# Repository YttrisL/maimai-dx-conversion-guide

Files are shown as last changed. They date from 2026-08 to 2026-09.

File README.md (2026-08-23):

# maimai FiNALE to DX Upgrade Guide

This repo hosts a step-by-step hardware guide for converting a **maimai
FiNALE** arcade cabinet into a working **maimai DX** cabinet - a project the
community calls "DxNALE". It covers everything from sourcing the right
equipment, to wiring, the touchscreen, the I/O board, the Aime reader, proxy
compatibility, audio, lighting, and cameras, in an order meant to be
followed start to finish by someone who isn't an electronics engineer.

The guide's guiding principle is **total software fidelity**: the goal is
never to modify the game's own software, but to make the hardware
adaptation invisible to it, so the resulting cabinet stays the way 
a genuine cabinet would behave.

## Building, running, or publishing this site

If you need to set up MkDocs locally, preview changes as you write, or build/publish
the static site, that's all covered separately in [DEVELOPMENT.md](DEVELOPMENT.md).

---

## A note on AI involvement

Claude (Anthropic) was used to help set up the MkDocs infrastructure for this
repo, and to assist with proofreading - fixing spelling and grammar,
rewording awkward turns of phrase - and with translating pages. 
Claude was **not** used to draft or generate the guide's
actual content from scratch: every `.md` file's substance - the steps, the
explanations, the technical knowledge - is human-written. AI here played an
editing and translation role, not an authoring one.

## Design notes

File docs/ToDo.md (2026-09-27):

---
title: "☑️ ToDo"
search:
  exclude: true
---

# ☑️ ToDo

- [ ] Check que toutes les références de FiNALE sont entre ** et pareil pour DX
- [ ] Vérifier la graphie de ALLS et de RingEdge2, s'assurer qu'elle est cohérente entre toutes les pages. (Entre ** également ?)
- [ ] PCB de conversion : Toujours écrit avec un lien
- [ ] Hub 4x RS-232 vers USB: Décider d'une graphie et la réutiliser partout. De manière générale, toute les pièces référencées.
- [ ] "Voir étape XX : Description" : S'assurer que tous les liens sont cohérents, qu'ils aient tous la même graphie et la même description.
- [ ] Vérifier les quantités et les objets de la liste de course
- [ ] Proposer un support en 3D de caméra incluant les leds et utilisant un module simple à trouver
- [ ] Pour toutes les mentions du style 1P SELECT, s'assurer qu'ils soient entre accent comme `1P SELECT`
- [ ] 
- [ ] 
- [ ] 
- [ ] 
- [ ] 
- [ ] 
- [ ] 
- [ ] 
- [ ] 
- [ ] 
- [ ] 
- [ ] 
- [ ] 
- [ ] 
- [ ] 
- [ ]

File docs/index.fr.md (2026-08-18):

---
title: "🏠 Accueil"
---

# Guide Complet : Projet "DxNALE"

## Convertir une borne maimai FiNALE en maimai DX

Bienvenue dans le guide détaillé de conversion matérielle d'une borne d'arcade **maimai FiNALE** vers le système **maimai DX**. Ce document est basé sur [les notes de conversion de la communauté](pdfs/dxnale-original-guide.pdf) et a été enrichi pour être accessible même si vous n'êtes pas un ingénieur en électronique.

---

## Qu'est-ce que "DxNALE" ?
DxNALE est le nom donné par la communauté aux bornes maimai FiNALE converties afin de faire fonctionner maimai DX. En effet, les deux systèmes sont radicalement différents, et il est strictement impossible de faire tourner DX sur une borne FiNALE dans son état d'origine.

Il existe une rumeur persistante au sein de la communauté selon laquelle convertir une borne en DxNALE serait un travail colossal, titanesque, presque irréalisable. **Il n'en est rien.** Certaines étapes sont effectivement complexes, mais ce guide a pour but de vous assister tout au long de l'opération.

!!! tip ""
    **L'objectif final : Une fidélité logicielle parfaite**

    Il est possible de modifier les données du jeu afin de pouvoir rendre compatible n'importe quelle dalle tactile produite par la communauté, toutefois nous visons ici une fidélité logicielle totale.
    
    **Aucune modification logicielle du jeu n'est tolérée.** Le jeu doit "penser" qu'il tourne sur une borne originale Sega. Par conséquent, toute notre adaptation matérielle doit être invisible pour le jeu.

    L'avantage de cette approche est que la borne DxNALE obtenue est théoriquement compatible avec l'idéologie de la plupart des serveurs privés principaux pour maimai DX.

---

## Par où commencer ?

1. Lisez les [Avertissements](warnings.md) pour comprendre les enjeux du projet et les conséquences de la modification.
2. Familiarisez-vous avec le [Lexique](glossary.md) afin de vous assurer de comprendre les termes employés par la suite.
3. Consultez la [Liste de courses](equipment.md), vous devez vous procurer chacun des éléments mentionnés.
4. Suivez les étapes de conversion dans l'ordre, en commençant par l'[Étape 1 : PC Central (ALLS)](step-1-pc-alls.md).
5. Pour les détails techniques du pont tactile, référez-vous à l'annexe [Comprendre maitouch_rs](understanding-maitouch_RS.md).

**Félicitations d'avance !** Si vous suivez toutes ces étapes, vous obtiendrez une borne *maimai DxNALE* fonctionnelle, sublimée et prête pour le jeu en ligne.

---

Prêt à vous lancer ? Commençons par les [Avertissements](warnings.md).

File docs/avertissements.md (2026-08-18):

# ⚠️ Avertissements et Considérations

Avant de vous lancer, voici la réalité du projet :

* **C'est coûteux :** Comptez entre 3000€ et 4000€ en plus du prix de la borne de base pour les pièces (Écrans tactiles ADX, PC ALLS, Raspberry Pi, câblages, etc.).
* **C'est complexe et long :** Il faut savoir lire un schéma de câblage, dénuder/sertir des fils, et utiliser Linux. Prévoyez au moins une semaine complète de travail acharné.
* **C'est quasi-irréversible :** Revenir en arrière (vers *Finale*) sera extrêmement fastidieux.
* **Testez avant :** Assurez-vous que votre borne *Finale* fonctionne parfaitement avant de commencer. Cela vous évitera de chercher des pannes imaginaires plus tard.

---

Un peu perdu dans les termes techniques ? Direction le [lexique](lexique.md).

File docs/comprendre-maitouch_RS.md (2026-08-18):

# Comprendre `maitouch_rs` : Un pont entre l'ancien et le nouveau

Ce document explique simplement le projet GitHub [`maitouch_rs`](https://github.com/4ndr3w/maitouch_rs). Si vous n'êtes pas un expert en protocoles de communication comme le port série RS-232 ou l'USB, ce guide est fait pour vous !

## L'Analogie Globale

Imaginez que vous avez un vieux jeu vidéo d'arcade qui ne sait communiquer qu'à l'aide d'un vieux talkie-walkie très lent. Vous voulez connecter à ce jeu un écran tactile moderne et ultra-rapide. 

L'écran tactile *fait semblant* d'avoir une prise de talkie-walkie pour être compatible avec l'ancien système (ce qu'on appelle l'USB-CDC), mais en réalité, il communique à la vitesse d'une connexion internet moderne. Parce que le talkie-walkie du vieux jeu est trop lent et qu'il est vite submergé, et parce que l'écran tactile est très exigeant sur la façon dont il reçoit les messages, les deux appareils ne peuvent pas se comprendre directement.

C'est ici qu'intervient **`maitouch_rs`**. C'est un petit programme qui agit comme un **traducteur intelligent** placé entre les deux.

## Les Deux Problèmes Principaux

Le créateur du projet explique deux problèmes majeurs lorsqu'on essaie de relier ces deux appareils directement avec des outils standards :

1. **La différence de vitesse (La lance à incendie vs la paille) :**
   L'écran tactile envoie des mises à jour de position (où vous touchez l'écran) à une vitesse folle (vitesse USB). De l'autre côté, le vieux jeu ne peut recevoir des données qu'au compte-gouttes (à "9600 baud"). Si on les relie sans réfléchir, le jeu est inondé de données, tout s'accumule, et le système plante.
   
2. **Le problème de la "gorgée unique" (Pas de mémoire tampon) :**
   L'écran a une particularité capricieuse : il exige qu'une commande lui soit envoyée en **un seul bloc parfait** (un seul appel de programmation appelé `write()`). Si la commande est découpée en plusieurs petits morceaux pendant le trajet sur le câble, l'écran ne sait pas comment la reconstituer et l'ignore tout simplement.

## Ce que fait cet outil

Pour résoudre ces problèmes, `maitouch_rs` effectue trois tâches principales :

1. **Il regroupe les commandes (Mise en mémoire tampon) :**
   Quand des messages lents arrivent du jeu pour paramétrer l'écran, le programme les conserve temporairement. Il attend que le message soit 100% complet, puis il l'envoie à l'écran tactile en **une seule fois** pour que l'écran l'accepte sans broncher.
   
2. **Il absorbe la haute vitesse :**
   Quand le jeu demande à l'écran tactile de commencer à envoyer les mouvements (mode "streaming"), l'écran se met à cracher des données à toute vitesse. Le programme absorbe cette quantité massive de données instantanément.
   
3. **Il donne la priorité aux données récentes :**
   Comme la connexion vers le jeu est trop lente pour lui transmettre *absolument tous* les petits mouvements de doigt, le programme fait le tri. Il jette les vieilles positions et n'envoie au jeu que **la position la plus récente possible**, aussi vite que la connexion lente le permet. Le jeu reste ainsi fluide et sans retard.

---

## Annexe : Petit lexique pour les débutants

Si les termes techniques vous semblent encore flous, voici de quoi y voir plus clair :

### Qu'est-ce que le RS-232 ?
Le RS-232 est une norme de câblage très ancienne pour brancher des appareils (comme les vieilles souris, imprimantes ou les modems des années 90) via ce qu'on appelle un **port série**. 
*   Il envoie les données à la queue leu-leu, "en série" (bit par bit sur un seul fil).
*   On mesure sa vitesse de transmission en **"bauds"**. Le terme "9600 baud" mentionné dans le projet signifie qu'il transmet environ 9 600 petits morceaux d'information par seconde. C'était suffisant pour du texte dans les années 80, mais c'est extrêmement lent pour du matériel d'aujourd'hui.

### Qu'est-ce que l'USB-CDC ?
CDC signifie *Communication Device Class*. C'est une petite ruse technique intégrée à l'USB.
*   Quand on branche un appareil USB-CDC sur un ordinateur, l'appareil ment à l'ordinateur et lui dit : *"Hé, fais comme si j'étais un vieux port série RS-232"*. 
*   Cela permet aux vieux logiciels (comme notre jeu d'arcade qui ne connaît que le RS-232) de fonctionner avec du matériel moderne USB sans que les développeurs aient besoin de modifier le code du jeu.
*   **Le piège :** Même s'il *fait semblant* d'être un vieux port série réglé à 9600 bauds, le matériel en lui-même s'en moque éperdument. Il utilise les vrais fils et la vraie puce USB (qui peut transmettre des millions de bits par seconde) et ignore totalement cette limite virtuelle. C'est exactement cette contradiction qui crée le goulot d'étranglement que `maitouch_rs` vient corriger !

---

Retour à l'[Étape 5 : Compatibilité avec le système d'origine via le Proxy](etape-5-proxy-compatibilite.md).

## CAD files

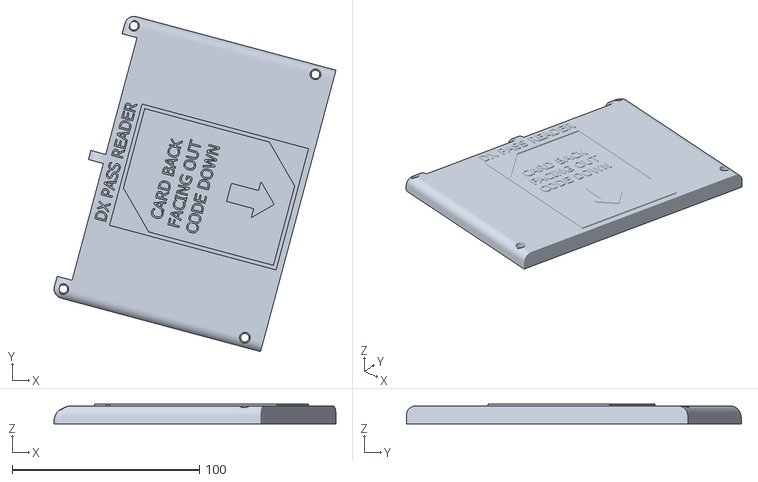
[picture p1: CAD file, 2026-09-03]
docs/resources/models/spiralglide/dxnale-dx-pass-reader-front-panel-v2.stl
150.5 x 178.9 x 10.5

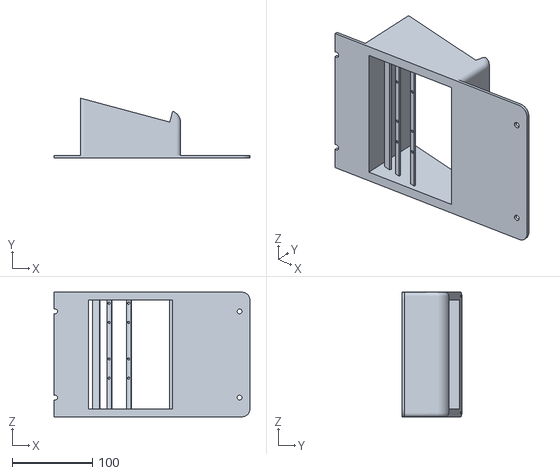
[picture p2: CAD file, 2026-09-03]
docs/resources/models/spiralglide/dxnale-dx-pass-reader.stl
244.5 x 74.5 x 155.5

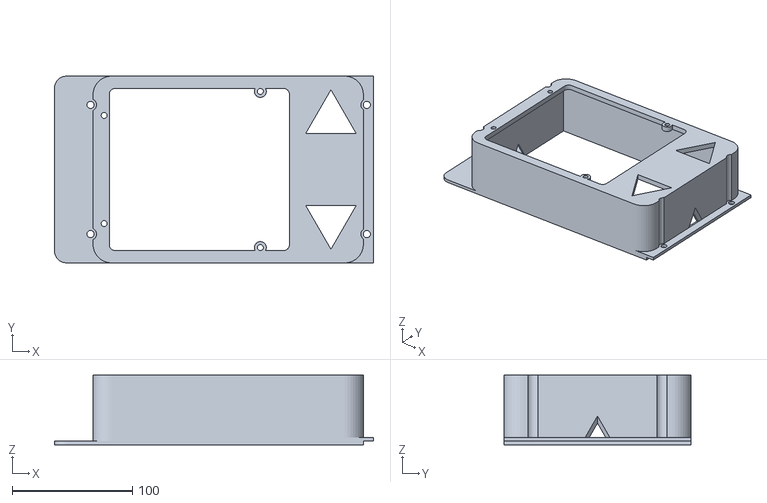
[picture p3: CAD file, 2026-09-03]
docs/resources/models/spiralglide/maimai-aime-reader.stl
265.5 x 155.5 x 58.0

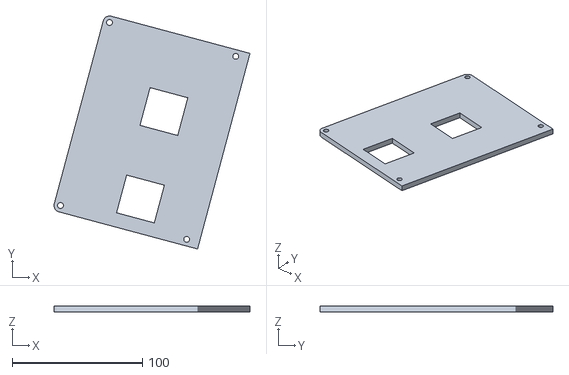
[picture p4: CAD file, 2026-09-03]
docs/resources/models/spiralglide/dxnale-dx-pass-reader-midpanel-v2.stl
150.5 x 178.9 x 4.50

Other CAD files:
docs/resources/models/spiralglide/maimai-aime-reader.ipt

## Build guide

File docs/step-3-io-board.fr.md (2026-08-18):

---
title: "🔌 3 - Carte I/O et boutons"
---

# 🔌 Étape 3 : La Carte I/O et les Boutons

Pour faire tourner *DX*, il est nécessaire de remplacer l'ancienne carte I/O par le nouveau modèle **IO4**. Heureusement, le câblage reste globalement le même, à quelques exceptions près.

*(Note : Le détail complet du câblage de la carte IO4 se trouve à la page 194 du [manuel](pdfs/maimai-dx-manual-full.pdf), en bas à droite)*

## 1. Le Bloqueur de Pièces (Coin Locker)

La broche (pin) correspondant au bloqueur de pièces a été déplacée au passage à l'IO4. Sur une borne *FiNALE*, il était câblé sur la broche 51.

1. Sur le gros faisceau de câbles anciennement raccordé à l'IO3, repérez la broche **51**.
2. Déplacez ce fil vers la broche **53**.

## 2. L'ajout des boutons "Select"

Sur *DX*, de nouveaux boutons physiques sont apparus pour permettre aux joueurs de trier les chansons. Vous devez les câbler manuellement :

1. Vous devez installer vos boutons sur le panneau central de votre borne, idéalement via la confection d'un boîtier personnalisé pour éviter une modification destructrice de la coque.
2. Connectez une broche de chaque bouton sur le neutre du faisceau de câbles (broches de 9 à 16).
3. Connectez l'autre broche du bouton sur la broche de la nappe correspondante :
   * "1P SELECT BUTTON" : Broche **27**
   * "2P SELECT BUTTON" : Broche **26**

## 3. Le contrôle des LEDs du Billboard (Toit de la borne)

Sur *DX*, l'IO4 est responsable de la gestion des lumières du sommet de la borne. Ce point sera également abordé à l'[Étape 7](step-7-lighting.md), mais voici déjà le schéma (pinout) des LEDs à raccorder :

* "BILLBOARD LED L RED" : Connecteur **CN3** - Broche **51** (Le gros faisceau de câbles)
* "BILLBOARD LED R RED" : Connecteur **CN3** - Broche **52** (Le gros faisceau de câbles)
* "BILLBOARD LED L GREEN" : Connecteur **CN9** - Broche **5**
* "BILLBOARD LED R GREEN" : Connecteur **CN9** - Broche **6**
* "BILLBOARD LED L BLUE" : Connecteur **CN9** - Broche **9**
* "BILLBOARD LED R BLUE" : Connecteur **CN9** - Broche **10**

Si vous ne souhaitez pas installer les LEDs du dessus de la borne, vous pouvez ignorer cette étape.

## 4. Branchement USB de la carte IO4

La nouvelle carte IO4 communique avec le PC *ALLS* via un simple câble USB. Cependant, **le choix du port USB sur l'ordinateur est défini dans le [manuel](pdfs/maimai-dx-manual-full.pdf)** *(Voir page 128 du manuel)*. Si vous regardez le PC *ALLS* posé à plat (à l'horizontale), vous devez brancher le câble de l'IO4 sur le port USB situé **en bas à gauche**.

---

Passons à l'[Étape 4 : Le Lecteur de Cartes Aime](step-4-aime-reader.md).

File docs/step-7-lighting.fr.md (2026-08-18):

---
title: "💡 7 - Lumières (optionnelle)"
---

# 💡 Étape 7 : Lumières (Optionnelle)

À ce stade, le jeu devrait être totalement jouable, mais l'éclairage esthétique de la borne n'est pas encore fonctionnel.
Sur *DX*, il y a trois contrôleurs différents qui gèrent l'éclairage de la borne :

* L'IO4 gère l'éclairage du "Billboard", le sommet de la borne. Référez-vous à l'[Étape 3](step-3-io-board.md) (point 3) pour savoir quelles broches utiliser.
* Deux cartes de contrôle identiques :
  * Une gère les LEDs des huit boutons du P1, l'éclairage du côté gauche, l'éclairage de l'anneau central de gauche et l'éclairage du fond de gauche.
  * L'autre gère les LEDs des huit boutons du P2, l'éclairage du côté droit, l'éclairage de l'anneau central de droite et l'éclairage du fond de droite.

Les deux cartes de contrôle s'interfacent en norme série RS-232 à une unique PCB convertissant les deux signaux RS-232 en USB. Cette PCB est elle-même raccordée à la même multiprise USB (Hub) que les caméras lecteurs de QR-Code (voir [Étape 8](step-8-cameras.md)).
Les ports COM logiciels sur lesquels les contrôleurs de LEDs sont interfacés sont le **COM21** pour les LEDs du P1 et le **COM23** pour les LEDs du P2.

Dans le cas d'une borne convertie, toutefois, les choses sont un peu plus compliquées.

Il est théoriquement possible de réutiliser les contrôleurs de LEDs d'une borne *FiNALE*, toutefois ceci s'accompagne de plusieurs inconvénients.

- Le numéro de série de la PCB ne correspond pas à ce que *DX* s'attend à trouver, cela provoquera ainsi un avertissement ("warning") au démarrage de la borne. Cela dit, le contrôleur fonctionnera tout de même.
- En cas de "warning", le jeu n'envoie simplement pas les données permettant d'éclairer l'anneau central (à ne pas confondre avec les boutons) et le corps de la borne (les données FET).

Les contrôleurs de LEDs de *FiNALE* s'interfacent de la même manière que ceux de *DX*, en passant par une carte de traduction intermédiaire convertissant le RS-232 des deux cartes en une unique connexion USB.
Les références sont les suivantes :

- *FiNALE* - Contrôleur LED : `837-15070-02-91 IC BD LED DRV32CH RS232` (Identique pour les deux joueurs)
- *FiNALE* - Convertisseur Serial-USB intermédiaire : `837-15067-02 IC BD USB TO 4SERIAL 232 IF`

Dans [le manuel de maimai *PiNK*](pdfs/maimai-pink-manual-full.pdf), on peut retrouver le contrôleur de LED à la page 192, et le convertisseur Serial-USB à la page 191 aux alentours de la zone FG-2.

Pour contourner le problème des avertissements sans avoir besoin de changer le contrôleur des LEDs, nous pouvons utiliser la même astuce de Proxy que nous avons utilisée à l'[Étape 5](step-5-proxy-compatibility.md). À l'aide d'un second Raspberry Pi 5 [et du logiciel `mailight_rs` (écrit en langage Rust)](https://gitea.farewell.dev/Yttris/mailight_rs), nous pouvons interfacer le contrôleur des LEDs avant la carte de traduction USB-Serial pour l'envoyer à notre proxy. Ce dernier s'occupera d'adapter le signal en modifiant les en-têtes pour fournir au jeu un signal lui faisant croire qu'il s'agit des bonnes PCB, il retournera ainsi un signal "GOOD" à la place du "warning". Le Raspberry Pi se placera alors entre les PCBs de contrôle des LEDs et le convertisseur serial USB, qui pourra lui être directement branché au ALLS sur le port dédié au Hub USB, ou au Hub USB lui-même si des lecteurs de QR-Code sont également installés.

Il est également possible de réutiliser le même Raspberry Pi 5 que celui des ADX pour effectuer le proxy des LEDs, toutefois à des fins de netteté et d'organisation, il est suggéré d'en dédier un pour chaque proxy.

---

Dernière étape (optionnelle) : les [Caméras](step-8-cameras.md).

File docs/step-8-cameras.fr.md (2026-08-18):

---
title: "📷 8 - Caméras (optionnelle)"
---

# 📷 Étape 8 : Caméras (Optionnelle)

Si vous souhaitez finaliser votre borne pour qu'elle soit parfaite, vous pouvez ajouter les caméras. Cependant, le jeu est tout à fait fonctionnel sans elles.

## 1. Caméra des joueurs (Photos in-game)

Prenez une webcam très basique et bon marché. Imprimez un support en 3D pour la fixer au sommet de la borne, sur la vitre en acrylique.

* **Branchement :** Sur l'ordinateur *ALLS* posé à plat, cette webcam doit se brancher sur le port USB situé **en bas à droite** *([Manuel](pdfs/maimai-dx-manual-full.pdf), page 128)*.
  Deux LEDs dédiées sont également à câbler sur l'IO4. Sur le connecteur CN9, en position 7 "CAMERA LED WARM" et en position 8 "CAMERA LED RED". *(Voir [manuel](pdfs/maimai-dx-manual-full.pdf), page 194)*.
* La plupart des réseaux privés ne gèrent pas la caméra, son usage se résumera donc à l'affichage en jeu.

## 2. Caméras des lecteurs de QR-Code

Dans *DX*, les joueurs peuvent scanner des cartes avec des QR codes.

* Pour que cela fonctionne, vous devez obligatoirement utiliser des webcams capables de filmer en **format UVC 640x480**.
* **L'éclairage :** Le jeu exige d'éclairer ces cartes avec des LEDs blanches (alimentées en 12V). Ces LEDs sont contrôlées par l'IO4, via les broches 55 et 56. *(Voir [manuel](pdfs/maimai-dx-manual-full.pdf), page 194)*.
  *Astuce : Ne braquez pas les LEDs directement sur la lentille de la caméra. Éclairez plutôt la paroi en plastique pour que la lumière rebondisse de façon diffuse sur la carte.*
* **Branchement :** Sur une véritable borne *DX*, ces caméras sont reliées à la même multiprise USB (Hub) que les lumières de la borne. Vous pouvez faire la même chose en utilisant un simple Hub USB branché sur le PC. Sur l'ordinateur *ALLS* posé à plat, le Hub doit être branché sur le port USB situé en **haut à droite** *([Manuel](pdfs/maimai-dx-manual-full.pdf), page 128)*.

**Faut-il vraiment installer les caméras QR Code ?**
C'est tout à fait optionnel. À moins que vous n'ayez accès à une autre borne très spécifique (le *Sega CardMaker*) pour imprimer vos cartes, elles ne vous serviront à rien. De plus, la plupart des réseaux privés offrent virtuellement un "DX Pass" à tous les joueurs, débloquant les fonctionnalités sans avoir besoin de scanner de cartes.

*Sachez qu'il est souvent possible lors de l'enregistrement de votre borne sur un réseau privé de demander à l'administrateur de désactiver complètement la recherche de ces caméras si vous ne souhaitez pas les installer.*

---

Vous avez terminé toutes les étapes ? Direction la [conclusion](conclusion.md) !

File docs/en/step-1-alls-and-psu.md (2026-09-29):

---
title: "🛠️ 1 - ALLS and PSU"
---

# 🛠️ Step 1: Replacing the Central PC (ALLS)

The old *RingEdge 2* PC cannot run *DX*: you need an **ALLS HX2** PC. Beyond the newer, more powerful hardware, the operating system is radically different between the two machines. **The replacement is mandatory.**

## Technical background

??? note "Click here for the technical explanation"
    The **ALLS HX2** is DX's native system: it is the one we substitute for FiNALE's RingEdge 2. An **ALLS MX2** also works: its specifications exceed the minimum required for *DX*. In principle, **every second-generation ALLS** (those whose model name ends in 2) **is software-compatible**, but some lack the power to run the game properly. That is the case, for example, of the **ALLS X2**: compatible, but too weak for a pleasant experience. These models can be upgraded, but the job quickly gets complicated: *you are better off getting a suitable model from the start.*

    An ALLS is very similar to a modern gaming PC, with two particularities:

    - **A recessed USB port** on top of the motherboard, reserved for the **keychip**. This USB key identifies the cabinet's owner on the official Sega network and decrypts the game data.
    - **Two expansion cards** (on second-generation models), which add three RS-232 serial ports and a 2.5mm audio jack. Together with the motherboard's COM port, these serial ports connect the Aime reader, the VFD and the touch panels of both screens. The jack is dedicated to one of the two headphone outputs.

    !!! tip "The ALLS power supply"
        The ALLS power supply switches voltage automatically: its C13 connector accepts 100V, 110V, 220V or 240V alike. **No external transformer is needed.**

    !!! warning "Storage"
        An official *DX* ALLS HX2 contains **two drives**: a 120GB SSD and a 500GB hard drive (named "SUB STORAGE"). **The game needs both**, the SSD alone is not enough. If your ALLS has only one drive, you will need to install a second one.

        To do so, see the [ALLS HX2 Service Manual](../resources/pdfs/alls-hx2-service-manual-full.pdf): **plugging in the drive is not enough**, a software step detailed in the manual is also required.

## Installing it in the cabinet

### Removing the RingEdge 2 and clearing the PC compartment

Start by **unplugging every connector from the RingEdge 2** and take it out of the cabinet. It will no longer be used: only keep it if you plan to convert the cabinet back to FiNALE someday.

!!! tip "Take out the whole board"
    Depending on your cabinet model, the RingEdge 2 is probably mounted on a wooden board. If so, remove the board directly rather than fighting with the hard-to-reach screws holding the PC in place.

Most of the surrounding components can be removed as well. To the right of the RingEdge 2, you will find **three PCBs**:

- **The IO3**, at the very top, recognizable by the large ribbon cable connected to it.
    * **Remove it**, along with its USB cable: it is replaced by the IO4 on *DX*.
- **The RS-232 to USB adapter**, bottom left, connected to the RingEdge 2 over USB. Two two-wire connectors are normally plugged into its bottom row.
    * **Keep it**: this board links the LED controllers to the PC. Take the opportunity to remove it and dust it off, you will reinstall it later.
- **The FiNALE touch panel controller**, bottom right, connected to the RingEdge 2 by a three-wire cable ending in a DB9.
    * **Remove it**, along with its cable and the two white cables connected underneath: the *DX* touch panels are radically different and no longer use this component.

Once these three PCBs are out, tidy up: **you will need all the available space.** If the RingEdge 2 was mounted on a board, you should now have a perfectly flat surface. *If it sat on two wooden slats, remove them too.* Where possible, secure the cables along the side walls rather than on the floor, to free up as much room as possible.

**The FiNALE router and camera** can be removed too: the router was notably used to link the camera to the RingEdge 2, and that camera is no longer used on *DX*. Also remember to remove the 2.5mm audio jack cable that linked the camera to the RingEdge 2.

#### Video cables

Originally, pre-*DX* maimai cabinets connect their screens to the RingEdge 2 with **two DVI to VGA cables** (VGA end on the screen). A choice that remains a mystery, since both screens have a DVI input: many operators therefore replaced them with plain DVI to DVI cables. Depending on your cabinet's history, you will find one or the other:

- **Player 1**: remove the cable, whatever it is.
- **Player 2**: **keep it if it is a DVI to DVI cable**, remove it if it is the original DVI to VGA.

!!! success "What should remain"
    Of the original RingEdge 2 wiring, you should only have left:

    - the two 2.5mm audio jack cables for the player 1 and player 2 speakers
    - the Molex Mini-Fit Jr cable (power)
    - possibly, the DVI to DVI cable for the player 2 screen

### Installing the ALLS

The ALLS is wider than the RingEdge 2, but the space you just cleared lets you install it comfortably, along with the various PCBs we will connect to it later. On official *DX* cabinets, the ALLS is actually installed *vertically*: that is an option if you are short on space. **What matters is that the PC is firmly secured** and cannot move if the cabinet is moved.

Once the ALLS is in place, you can already:

- **Mount the IO4**, ideally where the old IO3 was, to take advantage of the nearby original power cables. If you opted for the [conversion PCB]({{IO4_CONVERSION_PCB}}), plan room for it as well.
- **Reinstall the RS-232 to USB adapter.**
- **Plug the USB hub into the ALLS's USB 2 port**, then the RS-232 to USB adapter into that hub.
- **Install your new 5V/12V switching power supply** (see [Power supply](#power-supply)). Ideally, place it on the player 1 side with the other switching power supplies, even if that requires longer cables.

The remaining cables will be reconnected over the following steps.

## Connections

Here is the plate from the [official maimai DX manual](../resources/pdfs/maimai-dx-instruction-manual-full.pdf) (page 128) detailing all the connectors on an ALLS HX2. Let's go through each connection in detail.

!!! lightbox wide
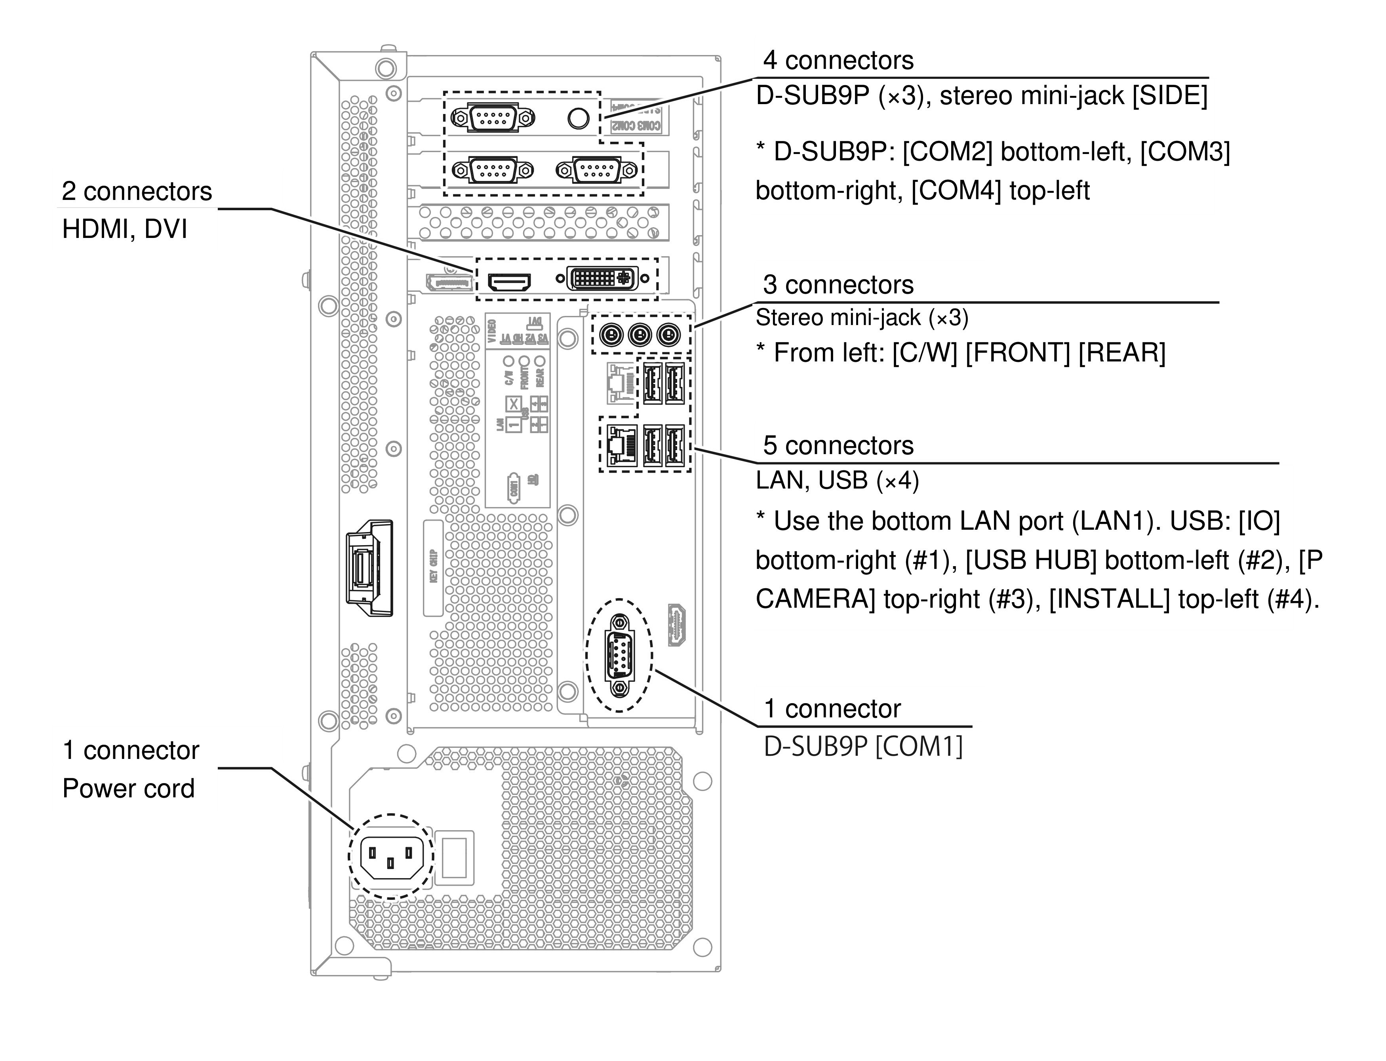
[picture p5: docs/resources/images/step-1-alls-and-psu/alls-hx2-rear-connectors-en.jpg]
Rear view of an ALLS HX2 and detail of its connectors.
    

Most of the devices to connect are covered in more detail in the following steps: if in doubt about a connection, finish the corresponding chapter first, then come back to this page. **According to the official *DX* manual, the order of the USB ports matters**: stick to the assignment below.

### Internal PSU

- **C13 connector**: Mains connection, accepts any input voltage from 100V to 240V.

### Keychip

- **USB port**: Reserved for the keychip. It can **not** be used as a regular USB port.

### Motherboard

- **COM1 - DB9 port**: Aime reader
- **LAN1 - RJ45 port**: Network port, to be connected to the service router. The second network port is unused.
- **2.5mm audio jacks**:
    - **C/W**: Player 1 [headphones](step-5-audio-headphones.md#the-headphone-jacks)
    - **FRONT**: Player 1 [speakers](step-5-audio-headphones.md#connecting-the-speakers)
    - **REAR**: Player 2 [speakers](step-5-audio-headphones.md#connecting-the-speakers)
- **USB**:
    - **USB 1**: SEGA IO4
    - **USB 2**: USB hub, to which the two QR code cameras and the `4x RS-232 to USB` adapter are connected.
    - **USB 3**: Player camera
    - **USB 4**: Installation port, for a USB stick containing the game data to install.

### Graphics card

- **HDMI**: Connected to the player 1 screen via an HDMI - DVI-D cable.
- **DVI**: Connected to the player 2 screen via a DVI-D cable.
- **DisplayPort**: Unused, mirrors the player 1 video signal.

### Expansion cards

- **COM2 - DB9 port**: VFD
- **COM3 - DB9 port**: Player 1 touch panel
- **COM4 - DB9 port**: Player 2 touch panel
- **SIDE**: Player 2 [headphones](step-5-audio-headphones.md#the-headphone-jacks)

## Power supply

Most connections are fairly straightforward, but **one essential RingEdge 2 connector has no equivalent on the ALLS**: the one that powers the external peripherals.

On the RingEdge 2, next to the keychip port, comes out a **female 2x7-pin Molex Mini-Fit Jr connector**. It links several parts of the cabinet, including the IO3, to the PC's internal power supply. Rather than rewiring the whole area, **the simplest solution is to build a small adapter** from an identical Molex Mini-Fit Jr connector, wired to a **switching power supply providing 5V and 12V** (typically an enclosed model with screw terminals, like those from the Mean Well brand). The original connector also provides 3.3V, but no hardware in this area uses it.

!!! warning "Do not reuse the cabinet's power supplies"
    Among other things, this harness will power the IO4. Reusing the existing 5V supply would have little consequence, but **reusing the LEDs' 12V supply would be a mistake**: to avoid any backfeed current, the IO4 and the LEDs must each have their own power supply, as the IO4 is not designed to handle that much current.

!!! warning "Tie the grounds together"
    **Connect the GND of your new power supply to the GND of one already in place in the cabinet.** A floating power supply can cause all sorts of unexpected problems.

Female Molex Mini-Fit Jr 2x7 connector, front view from the contact side: pins 1 to 7 are GND, 8 to 10 are +12V, 11 to 13 are +5V and 14 is +3.3V

Wire the female connector following the diagram above. It is shown **from the front, contact side**: do not confuse it with the wire side.

- Pin 14: **3.3V** (optional, unused)
- Pins 13-11: **5V**
- Pins 10-8: **12V**
- Pins 7-1: **GND**

Connect each wire to the matching terminal of your power supply. Little current flows through this harness (less than 3A in total, all voltages combined), but **make sure to use a suitable wire gauge**: the **20 AWG** (0.5mm²) wire from the [equipment list](equipment.md) is ideal. 22 AWG would also work, since each voltage is spread over several pins. Just check that your Mini-Fit Jr crimp terminals accept the gauge you choose (18-24 AWG terminals are the most common).

All that's left is to plug your homemade connector into the original cable.

!!! warning "The power supply must be firmly secured"
    The cabinet moves around a lot: **the power supply must never be able to shift or tip over.** Screw it firmly to the floor of the compartment.

## Summary
!!! tldr "The big picture"
    For the ALLS and the power supply:

    * Remove the RingEdge 2 and clear the compartment (IO3, FiNALE touch controller, router, camera)
    * Install the ALLS HX2 in its place and secure it firmly
    * Connect the various peripherals to the ALLS (see the following steps)
    * Build an adapter cable for the external power connector
    * Install the external power supply and the adapter cable in the cabinet, then plug in the existing connector

---

Let's move on to [Step 2: HDX Display and Touchscreens](step-2-touchscreen-display.md).

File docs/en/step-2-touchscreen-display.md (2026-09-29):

---
title: "📺 2 - Screens & touchscreens"
---

# 📺 Step 2: The Display and the HDX Touchscreens

--8<-- "includes/wip-en.md"

Let's start by installing the display and the touchscreens.

## The video connections

The game is programmed to send video to the two screens in a very specific way. The order must be respected. *(Reference: official [manual](../resources/pdfs/maimai-dx-instruction-manual-full.pdf) for the DX cabinet, page 128)*

* **Player 1 (P1):** can be connected to the **HDMI** or **DisplayPort** port (the [official manual](../resources/pdfs/maimai-dx-instruction-manual-full.pdf) recommends HDMI).
* **Player 2 (P2):** must be connected to the **DVI** port.

There is, however, a slight native difference between the screens of a *FiNALE* and a *DX*. In both cases they are 1920x1080 screens running at 60 Hz, but the *FiNALE* screens measure 42" diagonally, while the *DX* screens measure 43". The difference is practically imperceptible in-game.

## The HDX touchscreens

Remove the old touchscreens from the *FiNALE* cabinet (held by 8 screws) and install the new HDX touchscreens.
You then have to connect the touchscreens to the right "addresses" (COM ports) on the ALLS, otherwise the game will mix up the two players: *([manual](../resources/pdfs/maimai-dx-instruction-manual-full.pdf), page 128)*

* **Player 1:** must be connected to port **COM3**.
* **Player 2:** must be connected to port **COM4**.

!!! lightbox
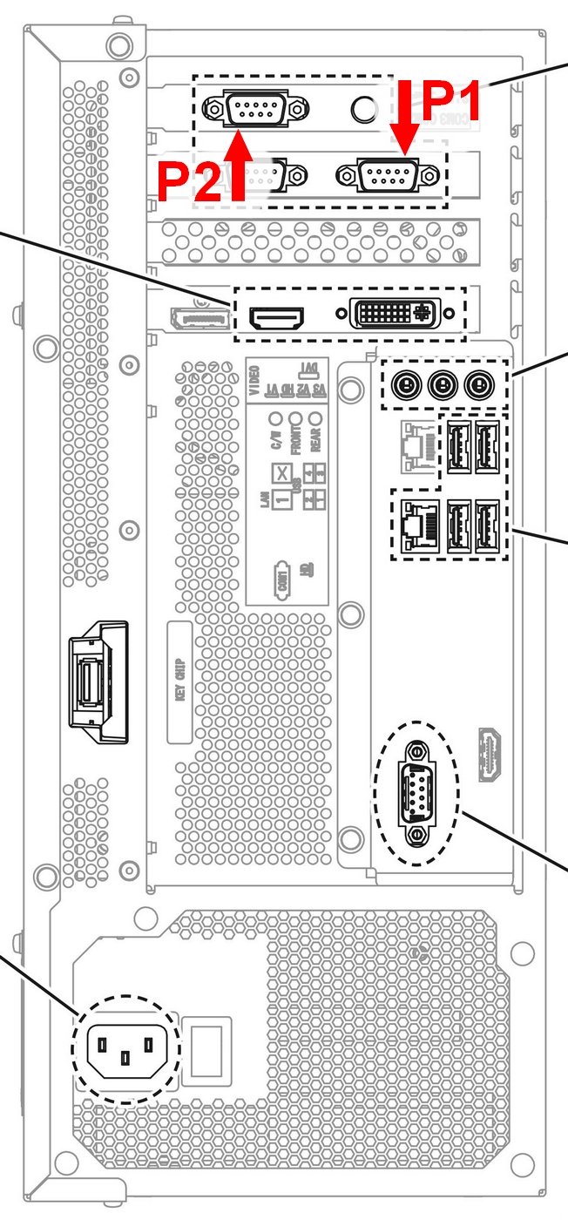
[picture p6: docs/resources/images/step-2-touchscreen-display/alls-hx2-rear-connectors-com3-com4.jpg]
Rear view of an ALLS HX2: red arrows point to the touchscreen DB9 ports on the expansion card, P1 at the bottom right and P2 at the top left
    

Unlike other conversion kits, the HanDevice I/O board supplied with the HDX touchscreens exposes a UART serial port directly. You can therefore connect it straight to the ALLS, with no signal conversion or intermediate Raspberry Pi - see the [Shopping list](equipment.md) for the details of this I/O board.

---

Let's move on to [Step 3: The Aime Card Reader](step-3-aime-reader.md).

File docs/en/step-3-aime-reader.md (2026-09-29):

---
title: "💳 3 - Aime card reader"
---

# 💳 Step 3: The Aime Reader and the VFD

**The FiNALE Aime readers are not compatible with DX**: you need to install a newer-generation reader. The VFD has no real use in our conversion, but the software still requires it. Good news: both are very simple to install.

## Technical explanation

??? note "Click here for the technical explanation"
    FiNALE uses two previous-generation Aime readers, chained to each other: the top one reads the left player's card, the bottom one the right player's.

    On DX, there is only **a single reader**. When a card is scanned, the profile appears on both screens: its owner confirms the login on their screen, then the second player can scan their own card. The technology used is completely different: **a FiNALE Aime reader cannot be reused.**

    !!! info "aic_pico"
        It is technically possible to use an [aic_pico]({{AIC_PICO_REPO}}), an open-source project that imitates a real Aime reader transparently for the game. It is much cheaper to produce, but would need a good deal of tinkering to be connected to the corresponding DB9 port on the ALLS.

    Last-generation Aime readers are not that rare anyway, and are often sold **as a combo with the VFD** that we also need. This generation is technically compatible with electronic payment, but even in Japan, that feature is almost never used: operators prefer to install their own, more flexible payment terminal.

## The connectors

Connecting to the ALLS is extremely simple:

* Aime reader: **COM1**
* VFD: **COM2**

Both COM ports are physical DB9 ports on the ALLS. However, your Aime + VFD combo probably did not come with a ready-to-use DB9 cable: **you will have to crimp your own cables**, from the Aime reader and VFD connectors to the DB9.

!!! lightbox
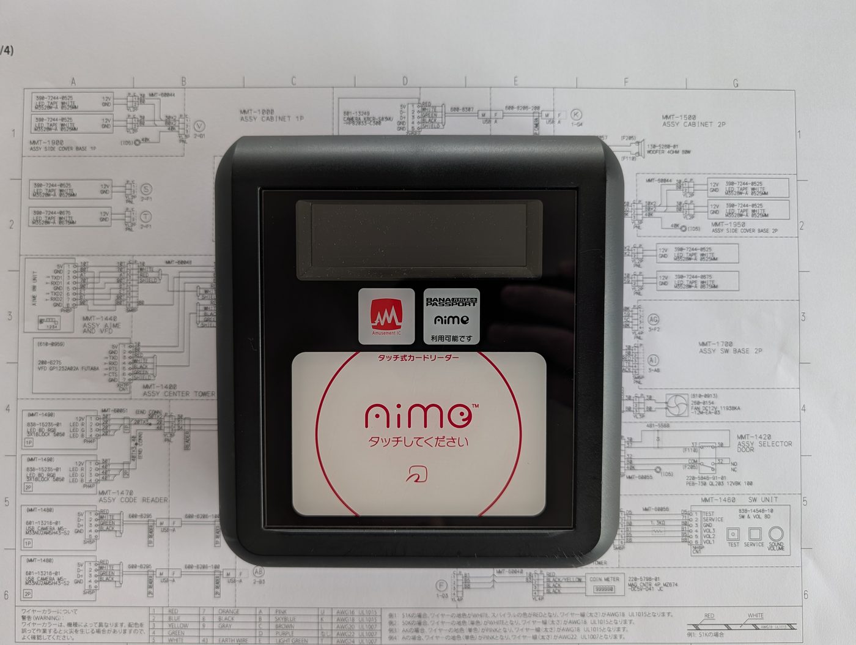
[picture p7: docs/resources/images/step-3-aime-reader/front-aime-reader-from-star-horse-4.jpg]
Front face of an Aime reader from a Star Horse 4 cabinet
    
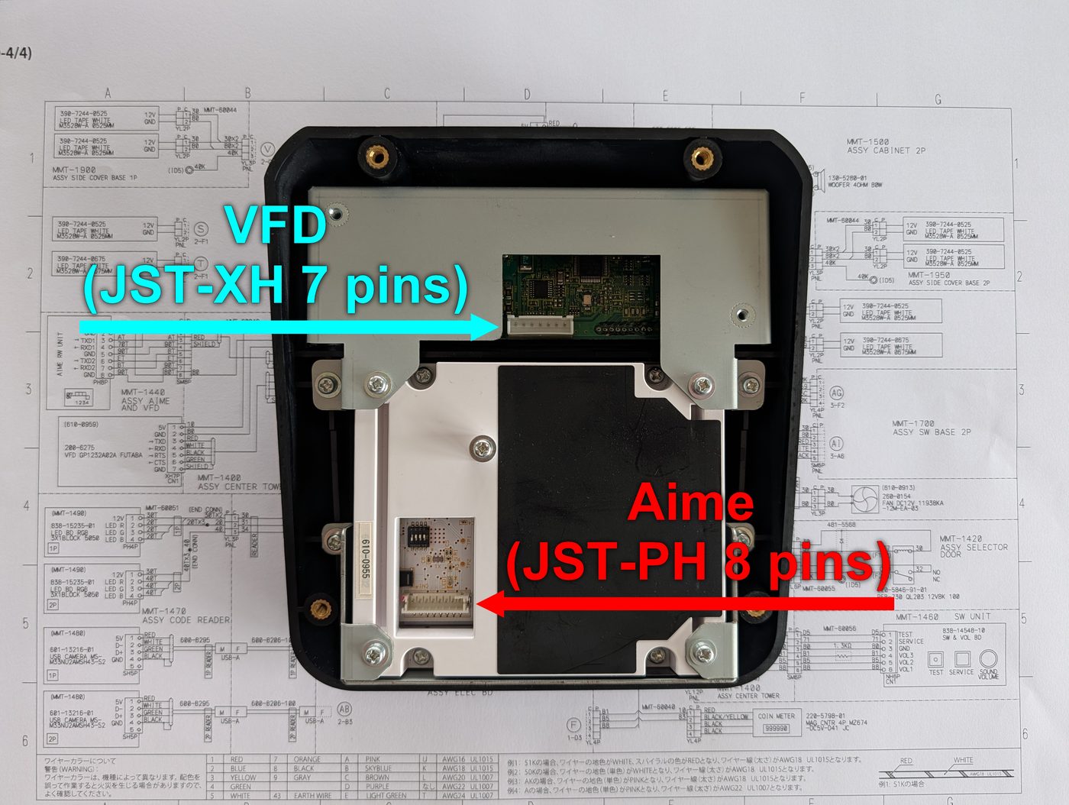
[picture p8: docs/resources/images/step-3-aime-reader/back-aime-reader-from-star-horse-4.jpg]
Rear face of an Aime reader from a Star Horse 4 cabinet
    

### Preparing the DB9 cable

Take your female-female DB9 cable and **cut it in two** to expose the wires. Two options:

* **Cut a long cable in the middle**, long enough once cut to run cleanly from the ALLS to the center of the cabinet, where the combo will be installed.
* **Cut about twenty centimeters** from one connector, then reach the ALLS with a simple male-female DB9 cable of the right length.

*The second option is recommended*: no bulky cable length while crimping, an easier installation, and a combo that is easier to unplug for maintenance.

!!! lightbox
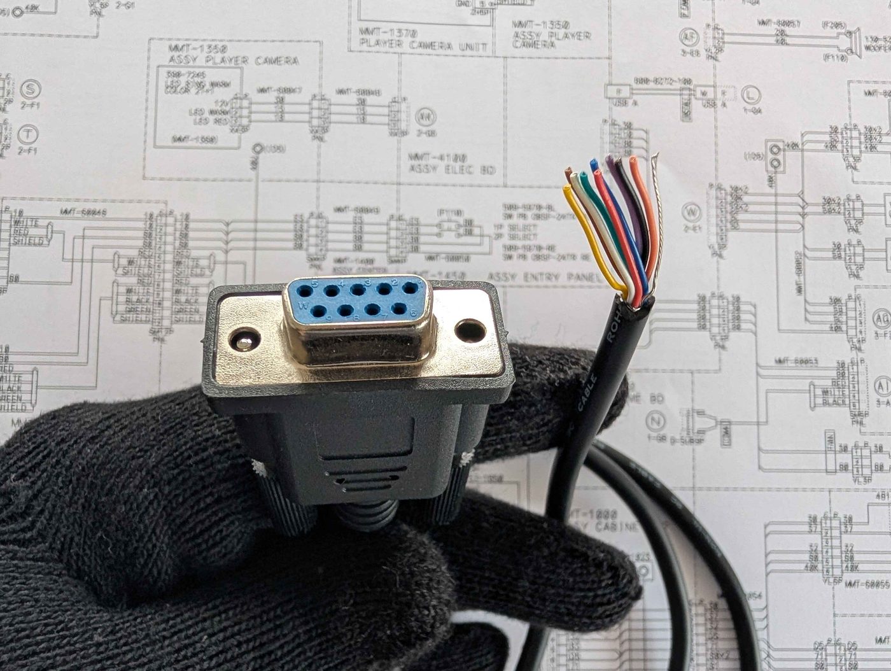
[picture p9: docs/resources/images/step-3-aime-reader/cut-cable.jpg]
Female DB9 cable cut open, sheath removed to expose the internal wires
    

### Identifying the right wires

Wire colors vary from one DB9 cable to another: do not rely on the colors in the photos. **The safest way is to use a multimeter in continuity mode**:

* Put one multimeter probe into the hole of the female DB9 plug matching the pin you want (see the diagrams below).
    * If the probe is too wide, attach a male Dupont wire to it.
* With the other probe, touch the wires one by one until you hear the beep. **The wire that beeps matches your pin**: mark it.
* Once all the useful wires are identified (*3 for the Aime reader, 5 for the VFD*), cut the others.

### Aime reader cable

The Aime reader is the simpler of the two: **only 5 of its 8 pins are used**. All 5 wires are crimped with **female JST-PH** pins and inserted into an **8-pin JST-PH** connector:

1. **3 signal wires**: the ones you identified on the DB9 cable.
2. **2 "flying" power wires**: a **red** wire on the **5V** pin and a **black** wire on the **GND** pin right next to it. They are not connected to the DB9: leave their other end free for now, it will be joined with the VFD's on a single connector (see [Grouping the power wires](#grouping-the-power-wires)).

Pin mapping between the Aime reader's JST-PH connector and the female DB9 port

!!! warning "Crimp both GNDs"
    Two of the pins to crimp are GND (common ground). In theory one would be enough, but **wire both**: one goes with the 5V to power the reader, the other is connected to the DB9 as the RS-232 standard requires.

### VFD cable

The VFD has a 7-pin connector, and **all of its pins must be crimped**.

The method is almost identical to the Aime reader's, with two differences:

* The VFD connector is a JST-**X**H (not JST-PH): crimp the wires with **female JST-XH** pins.
* **5 signal wires** instead of 3: you also need to connect the `CTS` and `RTS` signal wires to the serial port.

As for the Aime reader, add **2 flying power wires**, red on **5V** and black on **GND**, leaving their other end free.

Pin mapping between the VFD's JST-XH connector and the female DB9 port

### Grouping the power wires

The Aime reader and the VFD now each have a pair of flying 5V/GND wires. **Join them in a Y on a single 2-pin JST-SM connector**: both red wires (5V) together on one pin, both black wires (GND) together on the other. Placed next to your two DB9 cables, this connector makes the combo easier to install and to unplug for maintenance.

Congratulations, your cables for the ALLS are ready!

!!! lightbox
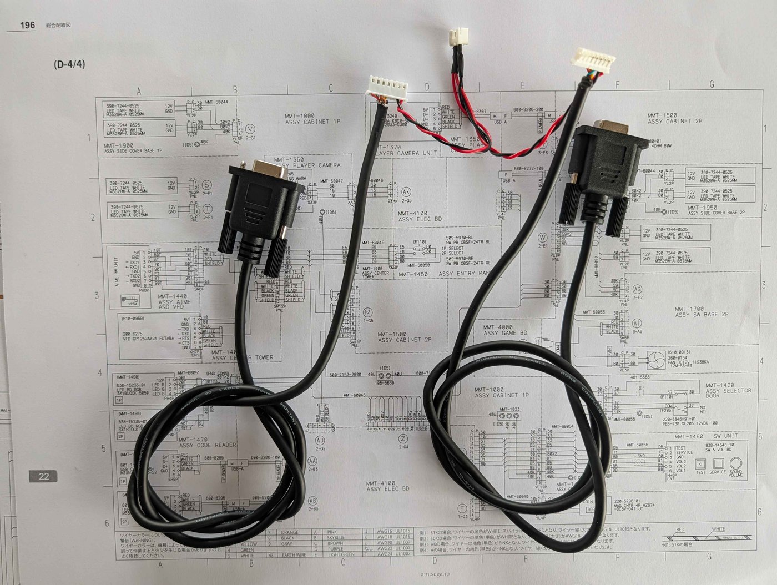
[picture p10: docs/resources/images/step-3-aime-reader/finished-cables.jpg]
The two finished female DB9 cables, with their JST connectors for the Aime reader and the VFD
    

### Securing the cables

Plug both cables into their connectors, then **fasten them to the back of the combo** so they are under no strain. Even well crimped, these connectors remain fragile.

!!! lightbox
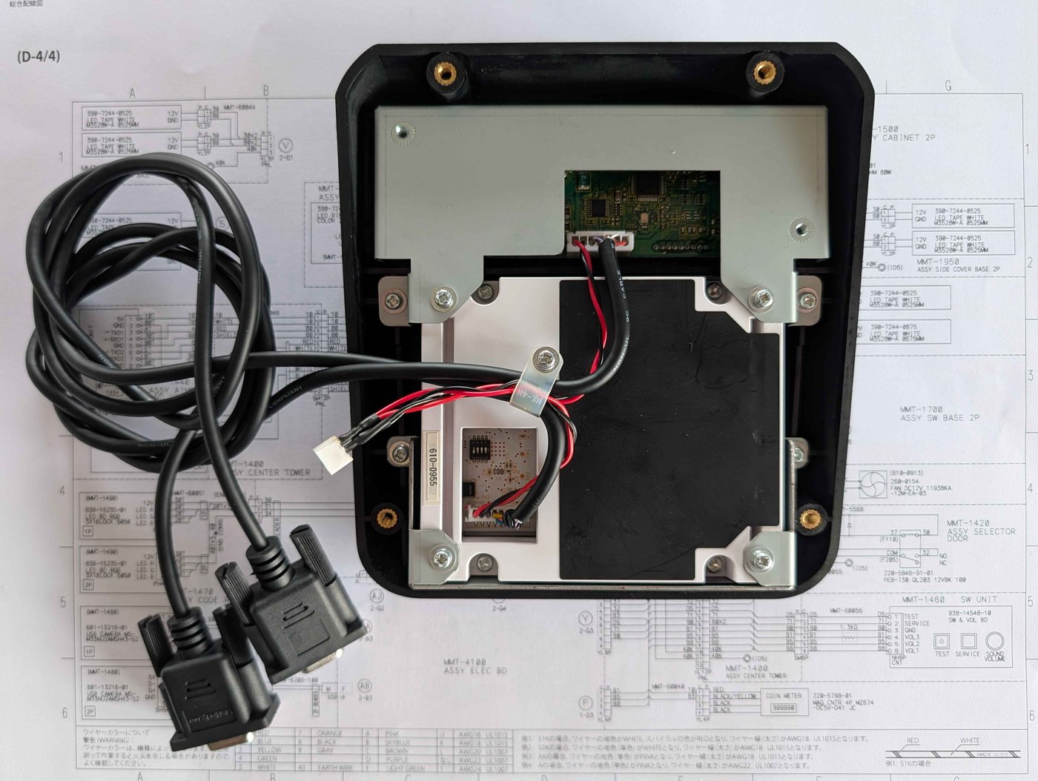
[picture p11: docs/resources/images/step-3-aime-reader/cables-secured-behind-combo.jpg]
The cables plugged in and then fixed at the back of the Aime reader + VFD combo to avoid any strain on the connectors
    

## Installing it on the cabinet

Use [the 3D model designed by SpiralGlide](spiralglide-resources.md#aime-reader-mount), which attaches to the cabinet using the existing screws of the acrylic panel. Designed for the Star Horse 4 Aime reader, it fits **without any destructive modification**, using the holes already there for the Aime readers. It also includes a spot for the 1P SELECT and 2P SELECT buttons, which you will install in [the next step](step-4-io-board.md).

!!! lightbox
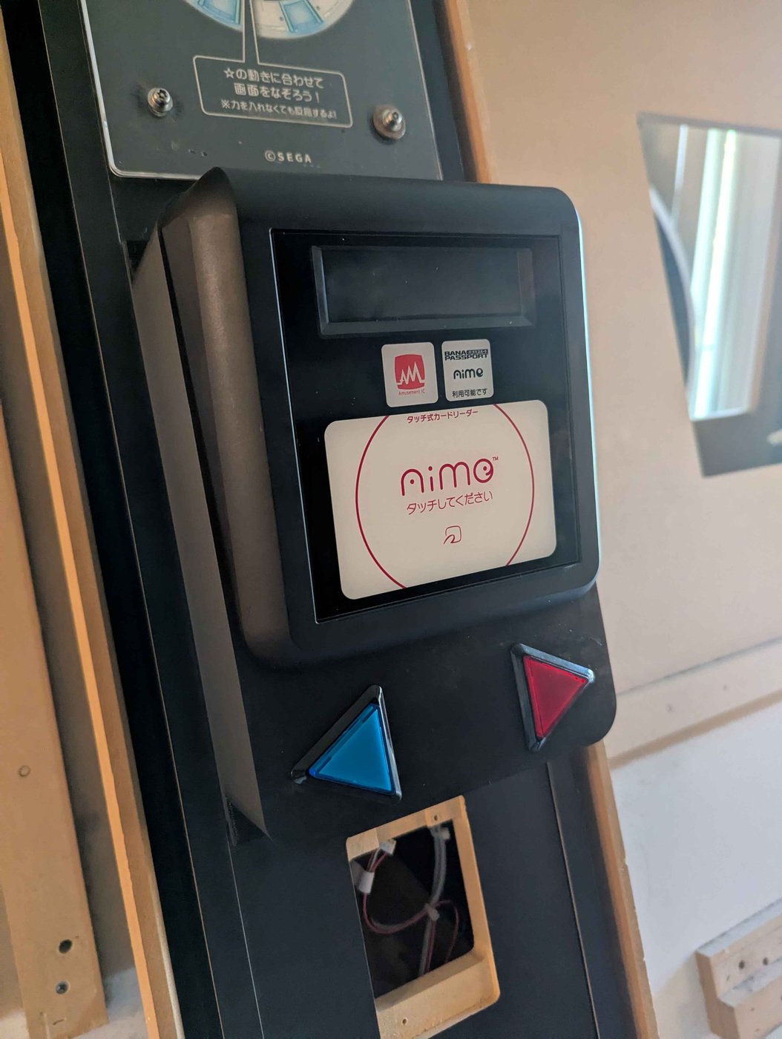
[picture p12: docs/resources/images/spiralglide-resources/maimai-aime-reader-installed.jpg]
The Aime reader mount printed and fitted into the front of the center tower, with the Aime reader in place. Photo by SpiralGlide
    

## Final step

Once the combo is installed on the front of the cabinet, all that's left is to plug the two cables into the ALLS DB9 ports. As a reminder: **Aime on COM1**, **VFD on COM2**.

Then don't forget to **connect the 5V and GND** of both connectors to the power supply installed in [step 1](step-1-alls-and-psu.md).

**Check that everything works** before moving on.

!!! lightbox
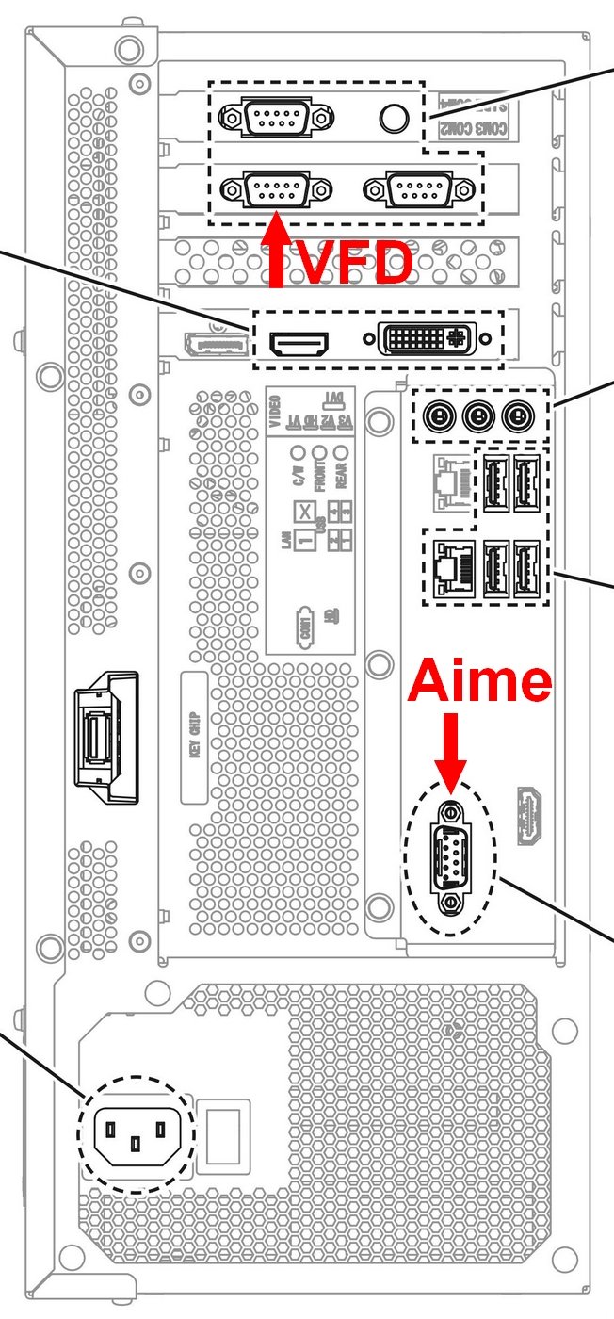
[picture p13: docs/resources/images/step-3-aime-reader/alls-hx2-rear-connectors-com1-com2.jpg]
Rear view of an ALLS HX2: red arrows point to the VFD DB9 port, on the expansion card at the top, and to the Aime reader one, at the bottom right of the motherboard
    

## In summary
!!! tldr "The big picture"
    For the Aime reader and the VFD:

    * Make a female DB9 cable for the Aime reader.
    * Make a female DB9 cable for the VFD.
    * Secure the cables so they don't move.
    * Install the combo on the front of the cabinet.
    * Plug both connectors into the ALLS.
    * Connect the power supply.

---

Let's move on to [Step 4: The I/O Board and the Buttons](step-4-io-board.md).

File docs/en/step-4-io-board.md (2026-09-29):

---
title: "🕹️ 4 - I/O board & buttons"
---

# 🕹️ Step 4: The I/O Board and the Buttons

To run *DX*, **the FiNALE IO3 must be replaced with a newer IO4**. Button-wise, the two models differ very little, but the wiring still needs to be adapted.

## Technical explanation

??? note "Click here for the technical explanation"
    The move to the IO4 brings two major changes to the DX cabinet wiring compared to FiNALE:

    * **The wiring harness was modified**: it now includes the two 1P SELECT and 2P SELECT buttons, and the Coin Locker moves from pin 51 to pin 53.
    * **The IO4 now handles the lighting** of several parts of the cabinet.

    The first point is simple, the second far more restrictive: **6 LED signals now go through the IO4**, where the LED controllers used to handle the lighting on their own on FiNALE.

    Another change: **the IO4 talks to the PC over USB**, no longer over JVS as on RingEdge 2. *Some IO4 variants also support JVS, but that doesn't matter here: the connection is always made over USB.*

    !!! lightbox
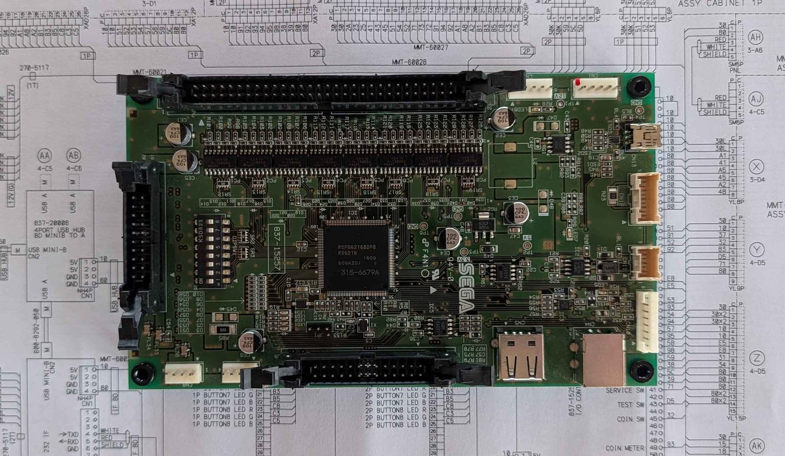
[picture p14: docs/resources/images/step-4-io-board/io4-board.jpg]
A Sega IO4 board (837-15257)
        

    *(Note: the full wiring detail for the IO4 is on page 194 of the [manual](../resources/pdfs/maimai-dx-instruction-manual-full.pdf), or directly [here](../resources/images/wiring-diagrams/maimai-dx-wiring-diagram-2-of-4.jpg), from **[E-2]** to **[F-6]**.)*

    !!! info "Powering the IO4"
        The USB connection is not enough to power the IO4. It also needs:

        * a **5V** source, through connector **CN7**, **CN8** or both,
        * a **12V** source, through connector **CN1**, **CN2** or both.

        Good news: **the IO3 power connectors plug into the IO4 as they are**. They are already connected to the external power supply installed in [step 1](step-1-alls-and-psu.md).

## Installing the IO4

Start by **plugging the original IO3 power connectors into the IO4, mounted in [step 1](step-1-alls-and-psu.md)**: **CN1**/**CN2** for 12V, **CN7**/**CN8** for 5V.

To install the IO4 in a FiNALE cabinet, you have two options:

* **Modify the harness by hand.**
* **Use the conversion PCB.**

**The second option is by far the easiest**:

* **No harness modification**: it plugs into the PCB as is, and the PCB takes care of the rest.
* **Ready-to-use connectors** for the new signals the cabinet lacks, such as the 1P SELECT and 2P SELECT buttons.
* **Free**: the files are [on GitHub]({{IO4_CONVERSION_PCB}}), with a short guide to have it manufactured yourself.

Either way, *the LEDs are covered in detail in [step 6](step-6-lighting.md)*: this chapter focuses on the harness.

??? example "The easy way - The conversion PCB"

    ### The conversion PCB

    The conversion PCB makes things much simpler, **especially for the LEDs** in [step 6](step-6-lighting.md). It has two connectors in the same format as CN3: **one plugs into the IO4, the other takes the cabinet harness.**

    !!! lightbox
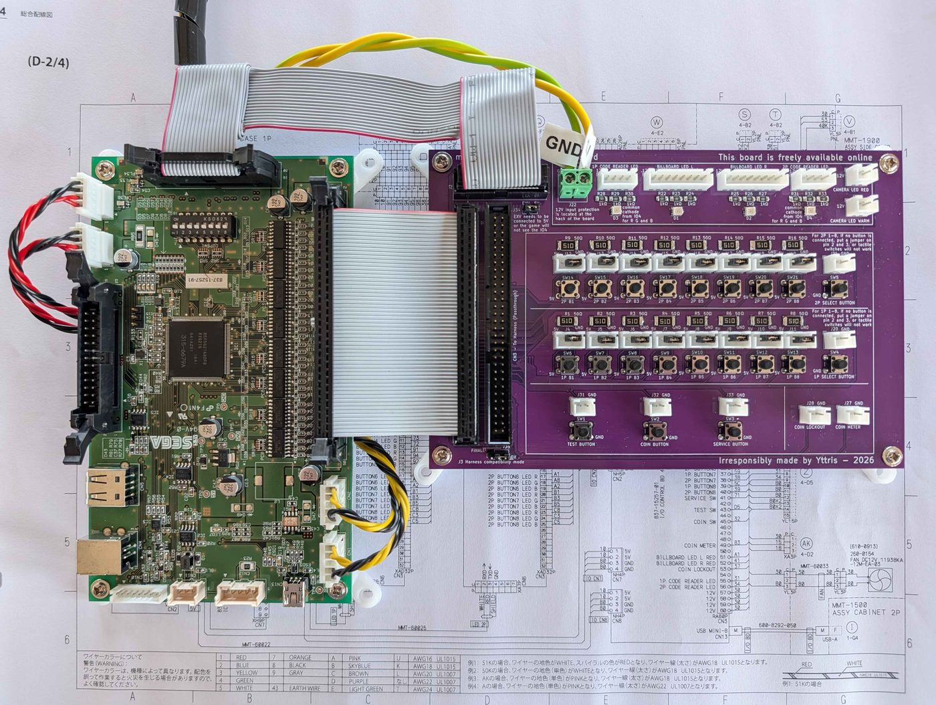
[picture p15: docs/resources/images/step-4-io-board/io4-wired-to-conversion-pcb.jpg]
The IO4 board wired and connected by ribbon cables to the conversion PCB
        

    #### Installing the PCB

    The PCB goes right next to the IO4. **Four connections are all it takes:**

    1. PCB **J1** → IO4 **CN3**.
    2. PCB **J2** → IO4 **CN9**.
    3. **12V** on the PCB's **J22** connector (see below).
    4. **Cabinet harness** → PCB **J3**.

    !!! tip "Which ribbon cables to use"
        The IO4's original connector is a JST-RA, but **any connector with a 2.54 mm pitch will do**. The easiest option: **IDC ribbon cables with a female connector on each end**. You need two: a **2x30** for CN3 and a **2x10** for CN9.

    #### Powering the PCB

    The PCB needs **clean 12V on the J22 connector**: it lights up the LEDs now driven by the IO4. **Ideally, use the cabinet's LED power supply.**

    A lot of current will flow through this circuit: **use a wire gauge that is large enough**, ideally **1.5 mm²**. *Better too much than not enough.*

    !!! warning "Polarity"
        **Double-check your wiring.** If 12V and GND are swapped, the PCB protects itself: your cabinet is not at risk, *but the PCB fuse blows* and will have to be replaced before the board works again.

    !!! danger "Don't use the IO4's power supply"
        The IO4 and the LEDs must **each have their own power supply**. So don't reuse the switching power supply installed in [step 1](step-1-alls-and-psu.md) for the PCB, for two reasons:

        * **Not enough power**: unless it is a high-end model, a small switching power supply won't handle the load of all the LEDs. It will run hotter than it should, which is dangerous. The cabinet's power supply, on the other hand, is designed for exactly that.
        * **Backfeed current**: the IO4's 12V rail is not designed for such a load. Using it for the PCB would eventually damage the IO4.

    #### Setting the jumpers

    The PCB has two jumper locations:

    * **J34 - EXV jumper**: ties the `EXV` signal to 5V. *Normally the cabinet harness already does this*, but you can install it if that isn't the case.
    * **J35 - Harness type**: tells the PCB whether the connected harness comes from FiNALE or DX.
        * **Unmodified FiNALE harness** (the case in this guide): jumper on the **two left pins**.
        * **Harness already modified by hand**, or a real DX cabinet: jumper on the **two right pins**.

    !!! lightbox
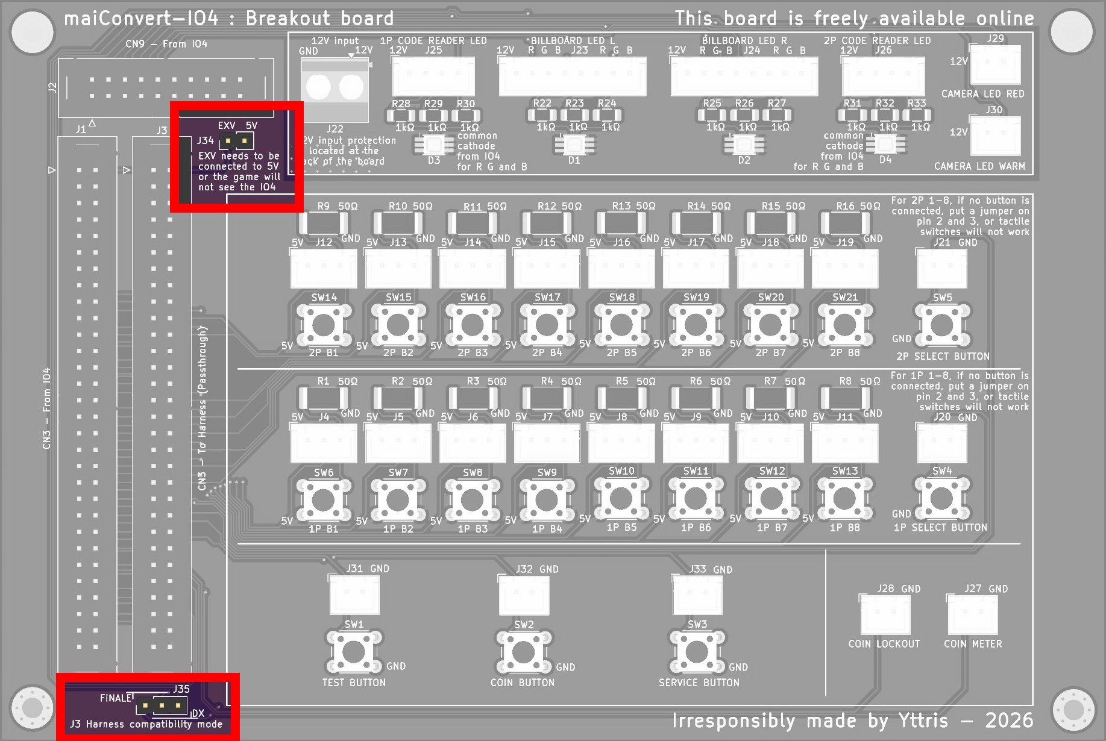
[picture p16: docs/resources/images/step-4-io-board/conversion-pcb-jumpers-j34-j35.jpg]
Render of the maiConvert-IO4 conversion PCB, with the jumper locations outlined in red: J34 (EXV to 5V jumper) at the top, near connectors J1 and J3, and J35 (harness compatibility mode, FiNALE on the left, DX on the right) at the bottom left
        

    #### Connecting the Select buttons

    The PCB provides **two male 2-pin JST-XH connectors** for the 1P SELECT and 2P SELECT buttons: crimp a **female 2-pin JST-XH** on the button side, plug it in, and you're done. [SpiralGlide's Aime reader mount](spiralglide-resources.md#aime-reader-mount), installed in [step 3](step-3-aime-reader.md), has a spot reserved for them.

    *No other button needs to be connected to the PCB*: **all the others go through the cabinet harness.**

??? example "Modifying the harness by hand"

    ### Modifying the harness by hand

    To modify the harness by hand, there are four points to handle.

    #### The coin blocker (Coin Locker)

    Its pin changed: **wired to pin 51 on *FiNALE*, it moves to pin 53**.

    1. On the large harness formerly plugged into connector **CN3** of the IO3, locate pin **51**.
    2. Move that wire to pin **53**.

    #### Adding the "Select" buttons

    *DX* adds **two buttons to sort songs**, which you wire yourself:

    1. **Install the buttons** on the central panel. [SpiralGlide's Aime reader mount](spiralglide-resources.md#aime-reader-mount), installed in [step 3](step-3-aime-reader.md), has a spot reserved for them.
    2. **Connect one pin of each button to ground (GND)** on the **CN3** connector harness (pins 9 to 16).
    3. **Connect the other pin** to the matching pin of connector **CN3**:
        * "1P SELECT BUTTON": pin **27**
        * "2P SELECT BUTTON": pin **26**

    #### Preparing the billboard LEDs

    Lighting is covered in [step 6](step-6-lighting.md), but **since you are already working on CN3, prepare the two red billboard signals now**:

    1. Crimp a wire on pins **51** (`BILLBOARD LED L RED`) and **52** (`BILLBOARD LED R RED`) of **CN3**. *Pin 51 is precisely the one freed up by the Coin Locker.*
    2. Terminate them with a **female 2-pin JST-SM**, which will be connected to the billboard harness in step 6. *Since this side carries current, a female connector prevents any accidental contact.*

    ??? info "For reference: all the LEDs handled by the IO4"
        * "BILLBOARD LED L RED": connector **CN3** - pin **51**
        * "BILLBOARD LED R RED": connector **CN3** - pin **52**
        * "BILLBOARD LED L GREEN": connector **CN9** - pin **5**
        * "BILLBOARD LED R GREEN": connector **CN9** - pin **6**
        * "BILLBOARD LED L BLUE": connector **CN9** - pin **9**
        * "BILLBOARD LED R BLUE": connector **CN9** - pin **10**
        * "CAMERA LED WARM": connector **CN9** - pin **7**
        * "CAMERA LED RED": connector **CN9** - pin **8**
        * "1P CODE READER LED": connector **CN3** - pin **55**
        * "2P CODE READER LED": connector **CN3** - pin **56**

    #### Checking the EXV jumper

    Normally already done, but check that pins **1-2** of **CN3** are connected to pins **3-4**. This jumper ties the `EXV` signal to 5V: **without it, the game won't detect the IO4.**

## USB connection

All that's left is to **plug the IO4 into the ALLS USB 1 port**, as explained in [step 1](step-1-alls-and-psu.md).

!!! lightbox
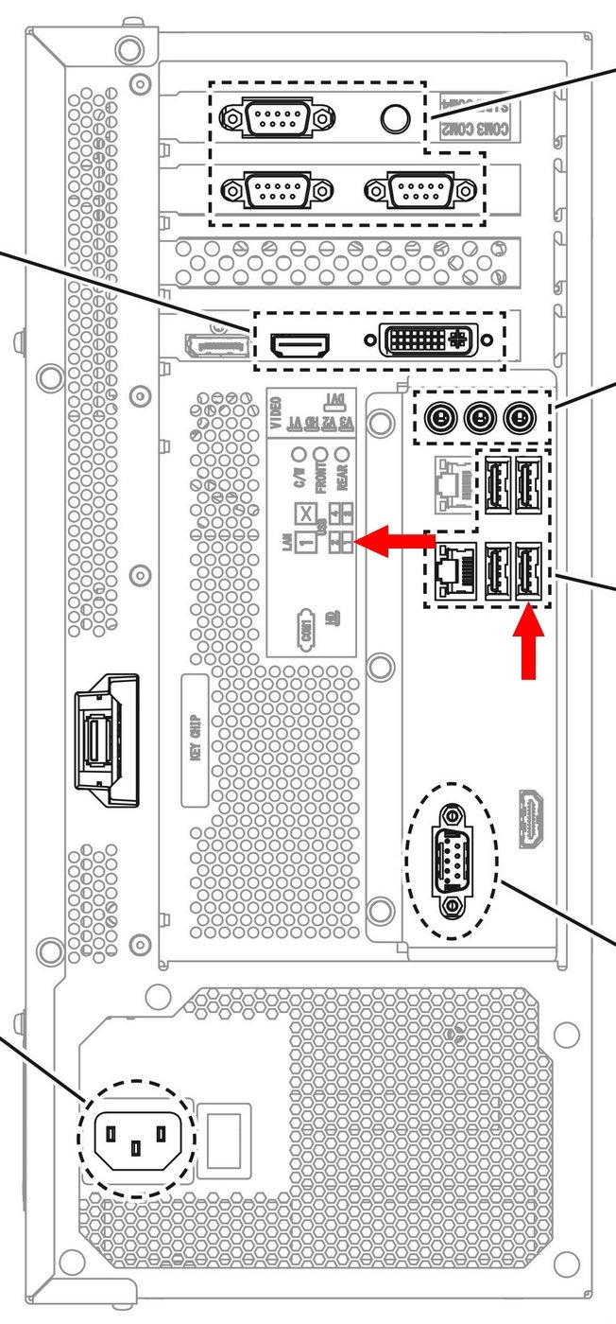
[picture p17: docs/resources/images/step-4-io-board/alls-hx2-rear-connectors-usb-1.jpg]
Rear view of an ALLS HX2: red arrows point to the USB 1 port, at the bottom right of the USB port block, and to its marking on the case label
    

## In summary
!!! tldr "The big picture"
    For the I/O board:

    * Plug the original power connectors into the IO4.
    * Install the 1P SELECT and 2P SELECT buttons on the central panel.

    If you choose the conversion PCB:

    * Connect the PCB to the IO4's CN3 and CN9 connectors with IDC ribbon cables, then plug the cabinet harness into it.
    * Power the PCB with 12V from the cabinet's LED power supply, using 1.5 mm² wire.
    * Set jumper J35 to the FiNALE position (two left pins).
    * Plug the Select buttons into their JST-XH connectors.

    If you choose manual wiring:

    * Move the Coin Locker wire from pin 51 to pin 53 of CN3.
    * Wire the Select buttons to pins 26 and 27 of CN3.
    * Prepare a female 2-pin JST-SM connector for the red billboard LEDs.
    * Check the EXV jumper.

    Finally:

    * Plug the IO4 into the ALLS USB 1 port.

---

Let's move on to [Step 5: Headphone Jacks and Sound System](step-5-audio-headphones.md).

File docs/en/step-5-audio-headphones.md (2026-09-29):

---
title: "🎧 5 - Headphones & audio"
---

# 🎧 Step 5: Headphone Jacks and Sound System

Unlike FiNALE, which had none, DX natively gives players a **headphone jack with in-game volume control**. Installing it is very simple.

## Connecting the speakers

The cabinet's existing sound system connects without any modification: just plug the jack into the appropriate motherboard port, as explained in [Step 1](step-1-alls-and-psu.md).

- **FRONT**: Player 1 side
- **REAR**: Player 2 side

!!! lightbox
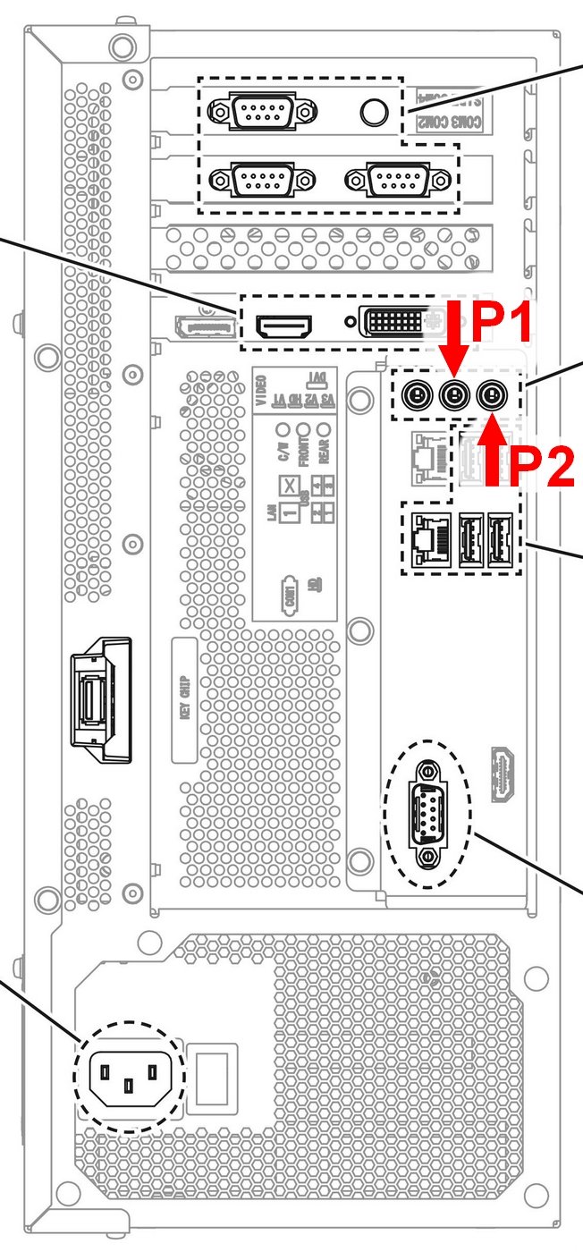
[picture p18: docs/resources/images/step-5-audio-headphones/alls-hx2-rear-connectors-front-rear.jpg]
Rear view of an ALLS HX2: the motherboard and expansion card with their connectors, red arrows P1 and P2 point to the speaker outputs
    

## The headphone jacks

The ALLS has 4 audio jacks: three in the usual location and a fourth on the expansion card. The headphone outputs use the two remaining ports:

- **C/W**: Player 1 headphone jack
- **SIDE**: Player 2 headphone jack

!!! lightbox
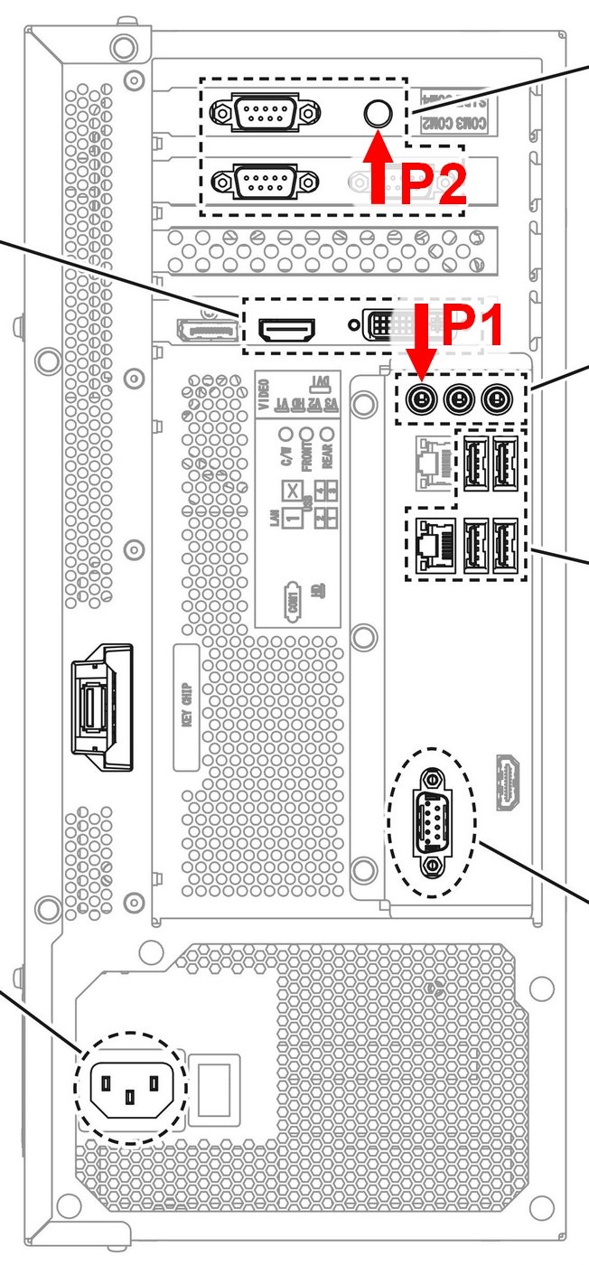
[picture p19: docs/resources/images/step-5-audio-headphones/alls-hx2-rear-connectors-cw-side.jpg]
Rear view of an ALLS HX2: red arrows point to the headphone outputs, C/W for P1 on the motherboard and SIDE for P2 on the expansion card
    

!!! warning
    The ALLS only outputs a **pre-amplified (very weak) sound**. In a real *DX* cabinet, this sound goes through a large dedicated amplifier. A FiNALE cabinet has none for headphones, since it had no headphone jack originally: these outputs cannot be used as they are.

### Installing an amplifier

Since the signal on the C/W and SIDE outputs is too weak, you need to buy **one or two small, cheap audio amplifiers**, one per player, plus 3.5 mm male-to-male jack cables to connect them to the ALLS. Everything is listed in the [shopping list](equipment.md#electronics).

!!! tip "No need for amps with volume knobs"
    On DX, headphone volume is adjusted digitally in the game menus. However, if your FiNALE had already been modified with a headphone jack, you can reuse the amp already in place.

### Installing on the cabinet

The jacks are simple 3.5 mm female Jack connectors. You have two options to install them:

1. **The faithful method:** drill the plastic shell under the buttons (as on a real DX) to embed the jacks.
2. **The non-destructive method:** install the two jacks in the center of the cabinet, between the two players, in a hand-made enclosure.

!!! tip "Jack durability"
    In an arcade, jacks wear out quickly from repeated plugging and unplugging of headphones. Plan for a shell-mounted jack that is **easy to replace**: connect it to the amplifier with a detachable cable rather than soldering the connector directly onto the amp.

## In summary
!!! tldr "The big picture"
    For sound and headphones:

    * Plug the existing speakers into the ALLS FRONT and REAR outputs.
    * Connect the C/W (Player 1) and SIDE (Player 2) outputs to one audio amp each, using 3.5 mm male-to-male jack cables.
    * Connect each amp to a 3.5 mm female jack socket for the headphones.
    * Install the sockets on the shell under the buttons, or in a central enclosure between the players.

---

Let's move on to [Step 6: Lighting](step-6-lighting.md).

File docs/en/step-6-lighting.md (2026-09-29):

---
title: "💡 6 - Lighting (optional)"
---

# 💡 Step 6: Lighting

Lighting is technically *optional*: it has no impact on gameplay. But the job is not that complex, and lighting adds a lot to DX's charm. **It is recommended not to skip this step.**

## Technical explanation

??? note "Click here for the technical explanation"
    ### How the LEDs work on a maimai DX

    On a real *DX* cabinet, lighting is driven by three controllers:

    * The **IO4** handles the **billboard** (labeled `BILLBOARD LED` / `ROOF LED` on Sega's diagrams). See [Step 4](step-4-io-board.md).
    * Two identical control boards (part no. `837-15070-04`):
        * P1 side: the eight buttons, the background lighting and the left side lighting.
        * P2 side: the eight buttons, the background lighting and the right side lighting.

    Lighting control chain: the P1 and P2 LED boards (part no. ) join the RS-232 to USB adapter (part no. ) over RS-232, itself plugged into the USB hub shared with the P1 and P2 QR-code cameras

    Both control boards are connected over RS-232 to a single RS-232 to USB adapter, itself plugged into the same USB hub as the QR-code readers (see [Step 7](step-7-cameras.md)).

    !!! info "COM port software configuration"
        The LED controllers show up on the following virtual COM ports of the ALLS:

        * **COM21** for the P1 LEDs.
        * **COM23** for the P2 LEDs.

    ### How the LEDs work on a maimai FiNALE

    Things are a bit simpler on FiNALE:

    * Unlike DX, no LED goes through the IO3.
    * Two identical control boards handle the LEDs (part no. `837-15070-02-91`):
        * P1 side: the eight buttons, the background lighting, the woofers, and the billboard on the P1 side and in the center.
        * P2 side: the eight buttons, the background lighting, the woofers, and the billboard on the P2 side.

    Lighting control chain on FiNALE: the P1 and P2 LED boards (part no. ) join the same RS-232 to USB adapter as on DX (part no. ) over RS-232, plugged directly into a USB port of the RingEdge 2, with no USB hub

    As on DX, these two boards are connected over RS-232 to an RS-232 to USB adapter. Luckily, **it is exactly the same one on FiNALE and DX (part no. `837-15067-02`)**. The only difference: on FiNALE, it plugs directly into a USB port of the RingEdge 2, with no hub.

    ### What this means for a conversion

    * **The RS-232 to USB adapter plugs into the 4-port USB hub** installed in [step 1](step-1-alls-and-psu.md). Any port on the hub will do.
    * **The billboard must be rewired to the IO4**: on DX, the LED controllers no longer receive any information to light it.
    * Above all, **the FiNALE and DX LED controllers do not have the same part number**. Plugged into an ALLS running DX, a FiNALE controller causes **a non-blocking error at startup**: it reports `837-15070-02-91` while the game expects `837-15070-04`. Fun fact: in this state, the game still sends the button lighting, but not the background lighting.

    Fortunately, all three problems have a solution.

## For the gameplay buttons and the background of both players

For the LED controllers, **DX expects the ID `837-15070-04`**, but the FiNALE ones return `837-15070-02-91`, which puts the game in error. That is the only problem: otherwise, the FiNALE controller is 100% compatible with the instructions sent by DX.

Both controllers therefore need to return the expected ID. A software patch would be simple, but we want to leave the game software untouched: **the solution will be hardware.**

**The solution:** a simple Raspberry Pi Pico, running a dedicated firmware, placed between the LED controller and the RS-232 to USB adapter. It **only modifies the message containing the ID**, and forwards all the others unchanged, in both directions.

The firmware already exists: it is [mailight_pico]({{MAILIGHT_PICO_REPO}}), a port of *[mailight_rs]({{MAILIGHT_RS_REPO}})* by [4ndr3w]({{GITHUB_4NDR3W}}) on GitHub. All that's left is to build the proxy.

### Building a proxy

!!! info "In duplicate"
    You need **two proxies**, one per LED controller. So do every operation twice.

**1. Install the firmware.** Flash mailight_pico onto the Raspberry Pi Pico. If you have never done it, it is extremely simple: [all the instructions are on the project page]({{MAILIGHT_PICO_FIRMWARE_INSTRUCTIONS}}).

**2. Mount the Pico on the `Pico-2CH-RS232`.** Watch the orientation: the markings under the `Pico-2CH-RS232` show where the Pico's USB port should be.

!!! lightbox
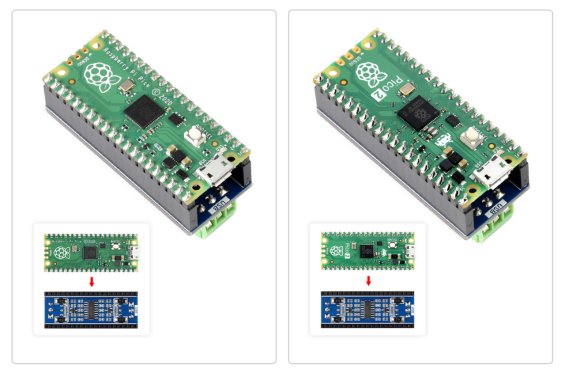
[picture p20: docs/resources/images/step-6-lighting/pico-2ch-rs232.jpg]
The module, image from the [official Waveshare wiki page]({{WAVESHARE_PICO_2CH_RS232_WIKI}})
    

!!! warning "Watch the orientation"
    Make sure your assembly matches the image. If your Pico's USB port ends up, for example, between the two PCBs rather than on the outside, its pins are soldered the wrong way. **Do not try to power it on**, you would damage the `Pico-2CH-RS232`. Resolder the pins the right way, or get a correctly assembled Pico.

**3. Prepare the connectors.** The proxy sits between the LED controller and the RS-232 to USB adapter. The connector differs depending on the side:

* P1 side: **7**-pin JST-XH, male **and** female
* P2 side: **9**-pin JST-XH, male **and** female

!!! lightbox
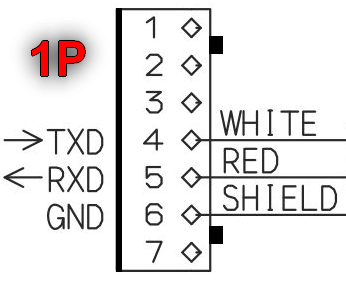
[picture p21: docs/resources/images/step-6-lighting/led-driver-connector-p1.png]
JST-XH connector, P1 side
    
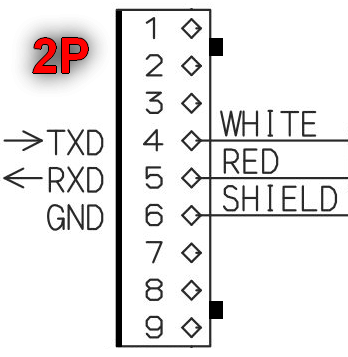
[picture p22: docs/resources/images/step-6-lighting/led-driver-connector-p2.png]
JST-XH connector, P2 side
    

To make things easier, reuse the cabinet's colors: **white wire on pin 4, red wire on pin 5**. Wire both connectors so the colors line up when the male is plugged into the female.

These images come from the wiring diagram, but the actual connectors in the cabinet have no `SHIELD` wire: the common ground will therefore have to be connected elsewhere on the `Pico-2CH-RS232`.

!!! lightbox
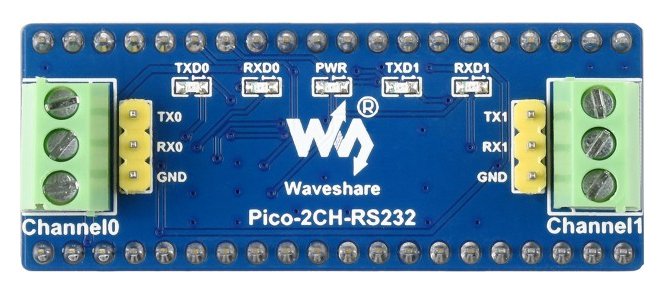
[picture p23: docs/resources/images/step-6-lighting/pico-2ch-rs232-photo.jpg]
Top view of the module
    
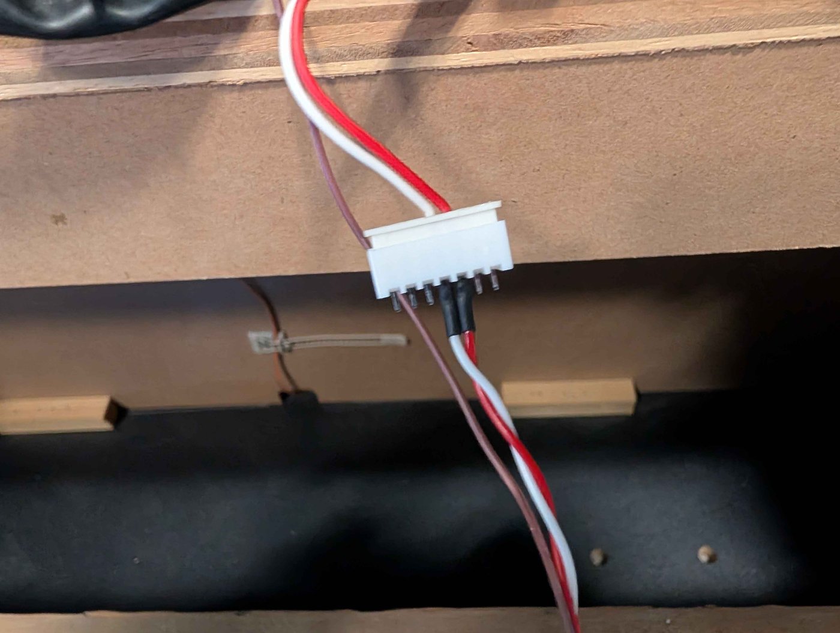
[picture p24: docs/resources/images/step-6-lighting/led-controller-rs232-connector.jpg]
The cabinet's original LED controller connector plugged into the hand-made connector
    

**4. Wire the screw terminals.** The **female JST-XH connector goes on the Channel0 terminal** (RS-232 to USB adapter side), the **male JST-XH connector on the Channel1 terminal** (LED controller side):

* Channel0
    * TX0: red
    * RX0: white
    * GND: a black wire, whose other end goes to the GND of the power supply installed in [step 1](step-1-alls-and-psu.md).
* Channel1
    * TX1: white
    * RX1: red

**5. Power the proxy.** The simplest way is to plug a micro-USB cable into the Pico and cut off its other end: **red wire to 5V, black wire to GND** on the power supply installed in [step 1](step-1-alls-and-psu.md).

Your proxy is done!

!!! lightbox
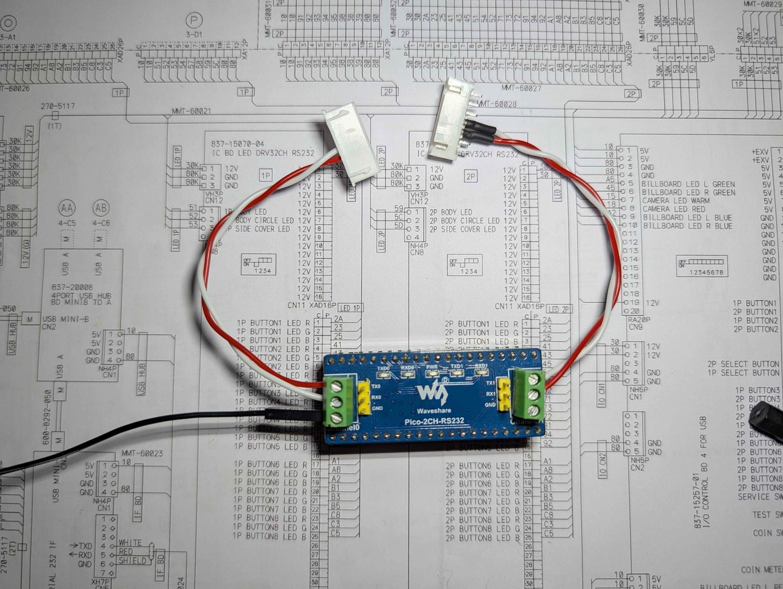
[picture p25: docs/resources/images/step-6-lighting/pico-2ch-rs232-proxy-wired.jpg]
The finished proxy: the Raspberry Pi Pico assembled onto the , with the female JST-XH connector (Channel0, RS-232 to USB adapter side) and the male JST-XH connector (Channel1, LED controller side) wired in red and white, plus the micro-USB power cable
    

### Installing the proxy

For each LED controller:

* Unplug the LED controller's connector and plug it into the proxy's **male connector**.
* Plug the proxy's **female connector** in its place, on the RS-232 to USB adapter.
* Power the proxy.

All that's left is to plug the RS-232 to USB adapter into the ALLS through the USB hub. **The game should recognize the LED controllers natively**, without any software modification.

!!! warning "Plug the adapter in correctly"
    As explained in [step 1](step-1-alls-and-psu.md), **the USB hub must be plugged into USB port #2** of the ALLS, and the RS-232 to USB adapter into that hub. maimai DX is very strict about USB ports: if plugged in wrong, the LEDs will not light up.

## For the billboard and the woofers

??? note "Click here for the technical explanation"
    On FiNALE, the woofers and the billboard share the same circuit: lighting one always lights the other. The woofers are no longer lit on DX, but that is not a problem since the billboard still is.

    However, on DX, **the IO4 handles these LEDs**: the game simply no longer sends this information to the LED controller. The reason for this change remains a mystery, but it means part of the wiring has to be redone.

    Luckily, the FiNALE wiring diagram references a very handy connector, which lets us distribute the signal to the player 1 and player 2 sides without rewiring the whole cabinet:

    !!! lightbox
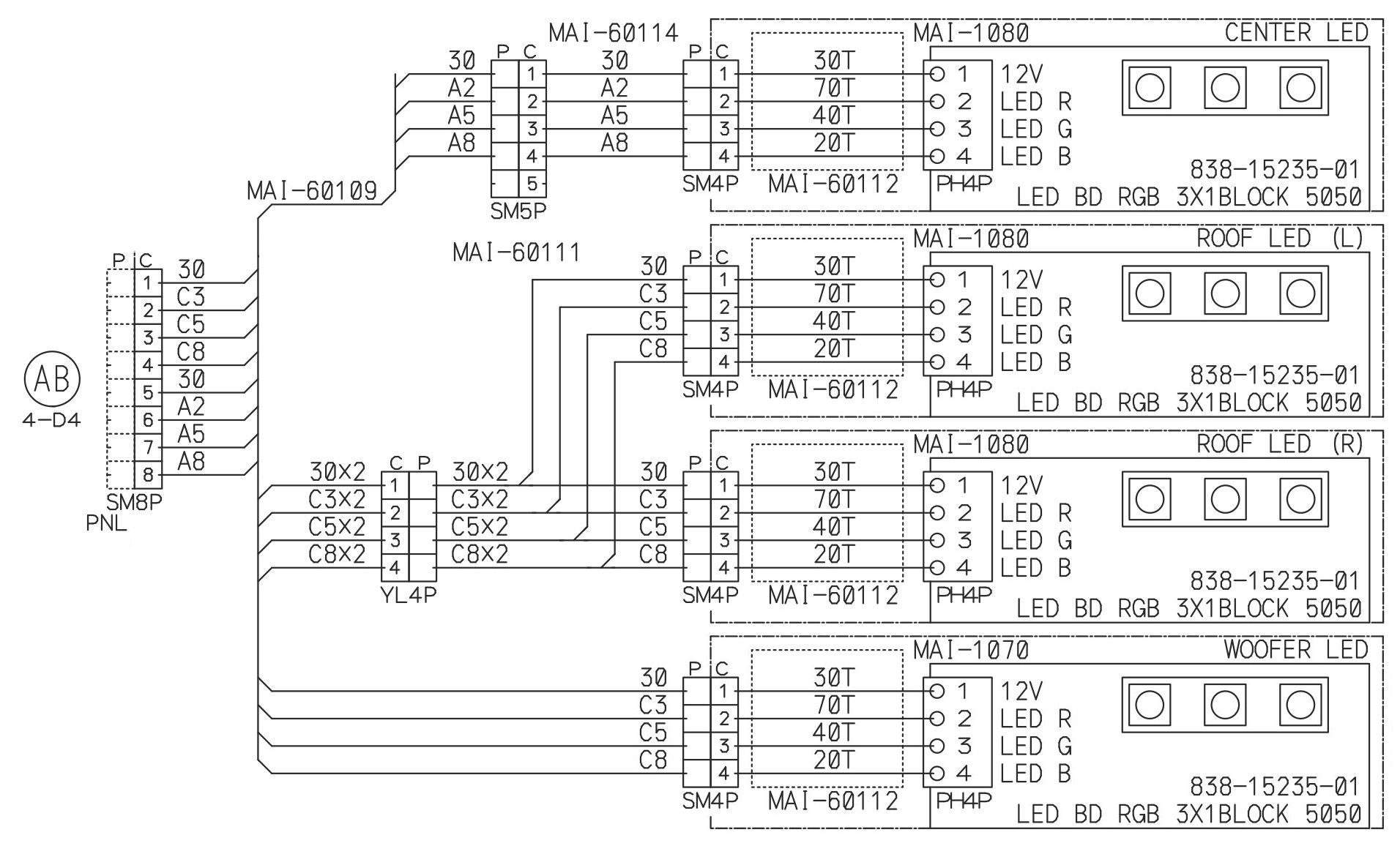
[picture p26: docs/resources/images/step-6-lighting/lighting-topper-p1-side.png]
FiNALE wiring diagram, connector AB on the P1 side: the MAI-60109 harness powers the CENTER LED, ROOF LED (L), ROOF LED (R) and WOOFER LED boards
        
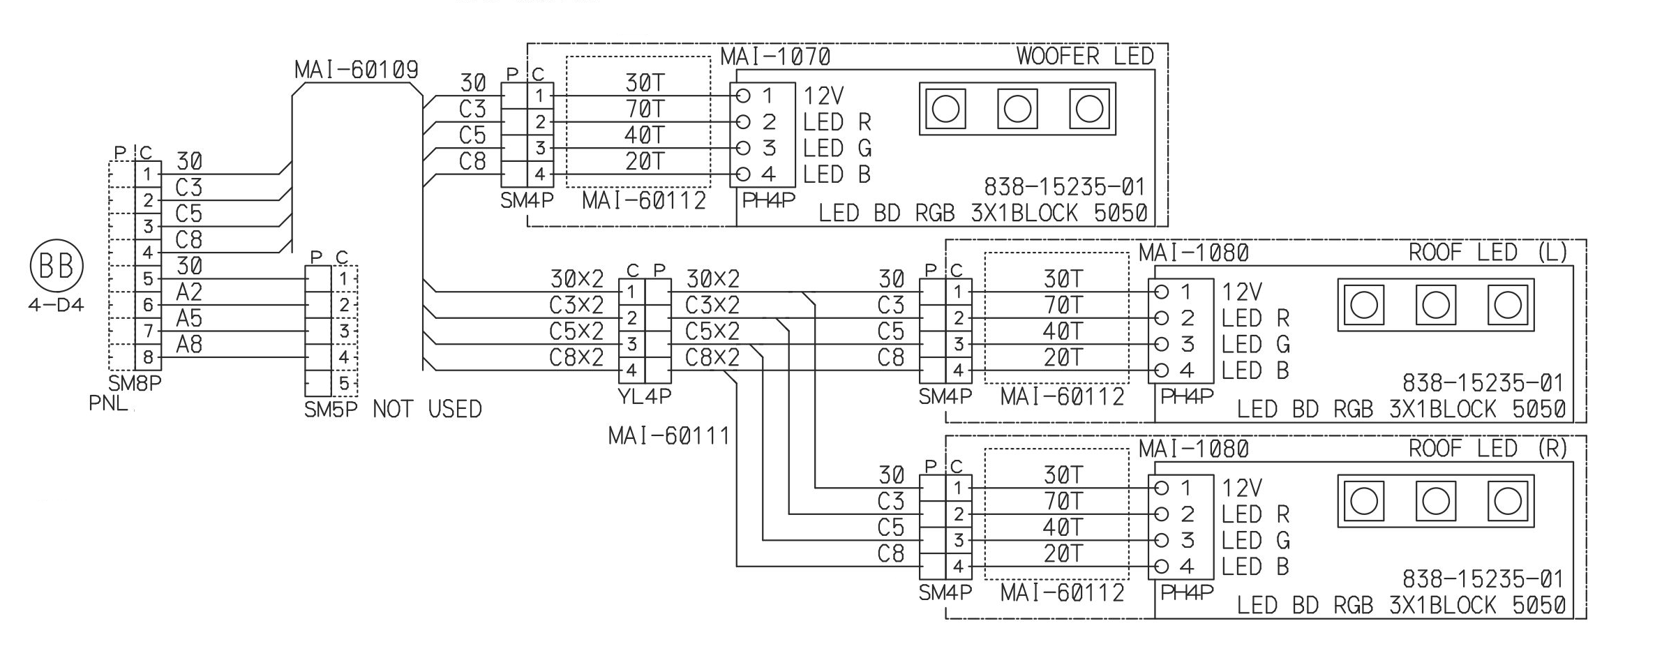
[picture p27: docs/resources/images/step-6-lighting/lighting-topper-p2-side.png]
FiNALE wiring diagram, connector BB on the P2 side: the MAI-60109 harness powers the WOOFER LED, ROOF LED (L) and ROOF LED (R) boards, with the SM5P connector unused
        
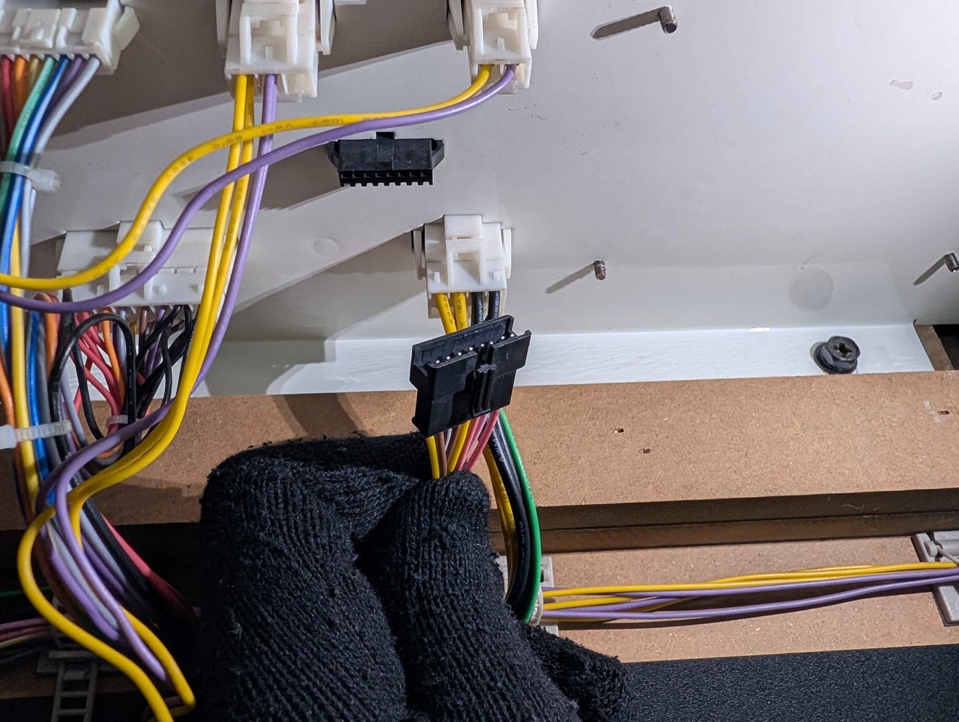
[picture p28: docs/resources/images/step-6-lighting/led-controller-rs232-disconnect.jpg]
8-pin JST-SM connector that connects the woofers and the billboard lighting (in black)
        

    The P1 diagram includes a `CENTER LED` element, absent on the P2 side: it is the lighting for the center of the billboard. On DX, this distinction does not exist: even though the signals are separate, the billboard is always the same color on both sides. The simplest solution is therefore to **connect pins `A2`, `A5` and `A8` of the P1 connector to pins `C3`, `C5` and `C8`**, so the center takes the same color as the player 1 side.

Two methods are possible:

* **With the [conversion PCB]({{IO4_CONVERSION_PCB}})**, if you installed it in [step 4](step-4-io-board.md): just plug the LEDs into the right ports on the PCB.
* **Without it**: make your own IO4-compatible wiring harness to connect the LEDs.

??? example "The easy way - The conversion PCB"
    Simply plug the LED controller's output connector into the conversion PCB. That's it: *the 12V has already been connected since [step 4](step-4-io-board.md).*

    !!! tip "Reminder: two separate power supplies"
        The PCB is powered by **the cabinet's LED power supply**, never by the IO4's 12V. The two circuits share a common ground, but stay separate.

    You will need an extension to reach the existing cable: **2 meters on the player 2 side, 3 meters on the player 1 side**. It is easy to crimp: a `8-position female JST-XH` connector on one end, and an `8-position female JST-SM` on the other.

    !!! lightbox
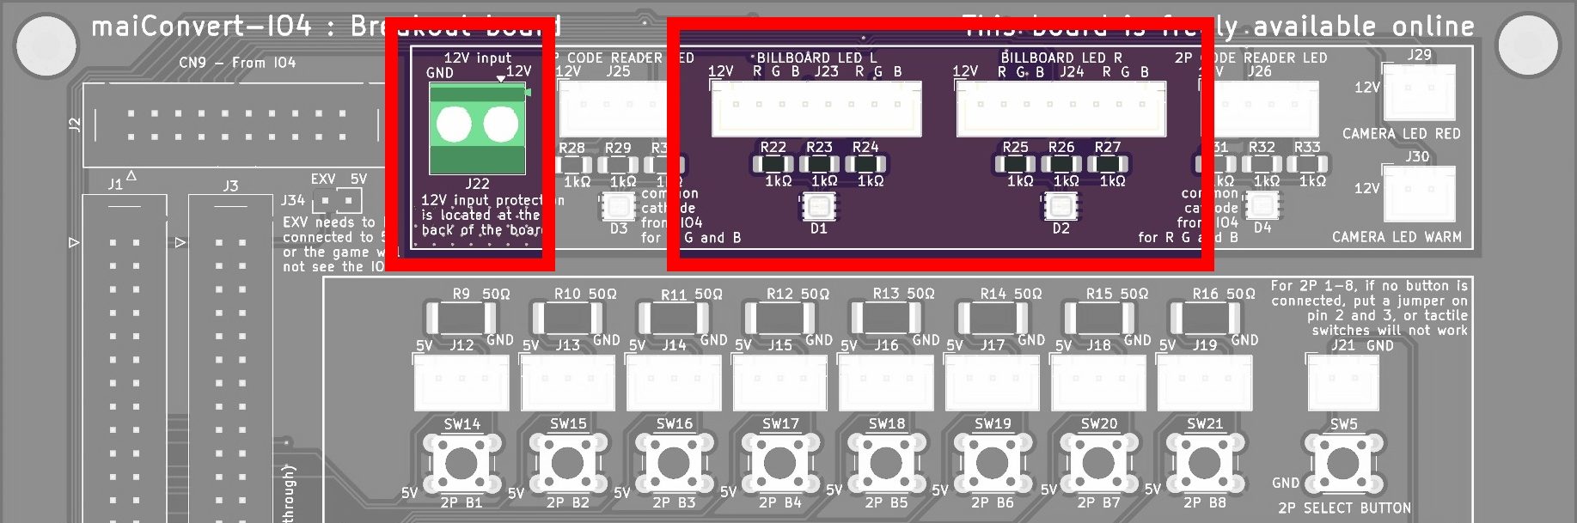
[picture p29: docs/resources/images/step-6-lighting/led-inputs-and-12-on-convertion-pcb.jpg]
Conversion PCB [maiConvert-IO4]({{IO4_CONVERSION_PCB}}): location of connector J22 ( , watch the polarity) and connectors J23/J24 ( / ) where the billboard LED harness connects
        
        Male 8-position JST-SM wiring harnesses that handle the billboard and woofer LEDs, unplugged from the connector wired to the LED controller on a FiNALE cabinet

    *If you plan to install the cameras in the next step*, the conversion PCB will make your life easier there too: it already has ready-to-use connectors for their LEDs.

??? example "Making a wiring harness by hand"
    The harness plugs into the IO4 through a 20-pin JST-RA connector (CN9), and ends in two 8-pin JST-SM connectors, for the left and right sides. If you followed the suggestions in [step 4](step-4-io-board.md), you already have a female 2-pin JST-SM connector wired to the IO4's CN3 for the `BILLBOARD LED L RED` and `BILLBOARD LED R RED` signals.

    !!! lightbox
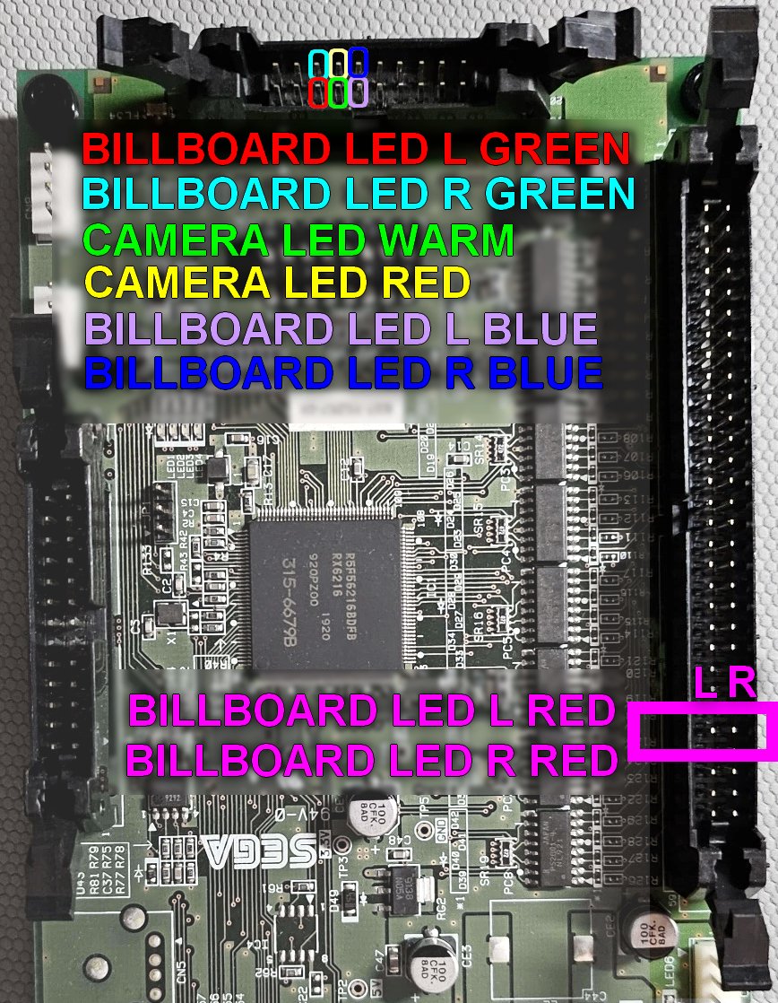
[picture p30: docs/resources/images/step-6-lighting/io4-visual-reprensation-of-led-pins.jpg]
Visual identification of the LED pins on the IO4: the CN9 connector (20-pin JST-RA) carries BILLBOARD LED L/R GREEN, CAMERA LED WARM/RED and BILLBOARD LED L/R BLUE, while BILLBOARD LED L/R RED is on the CN3 connector
        
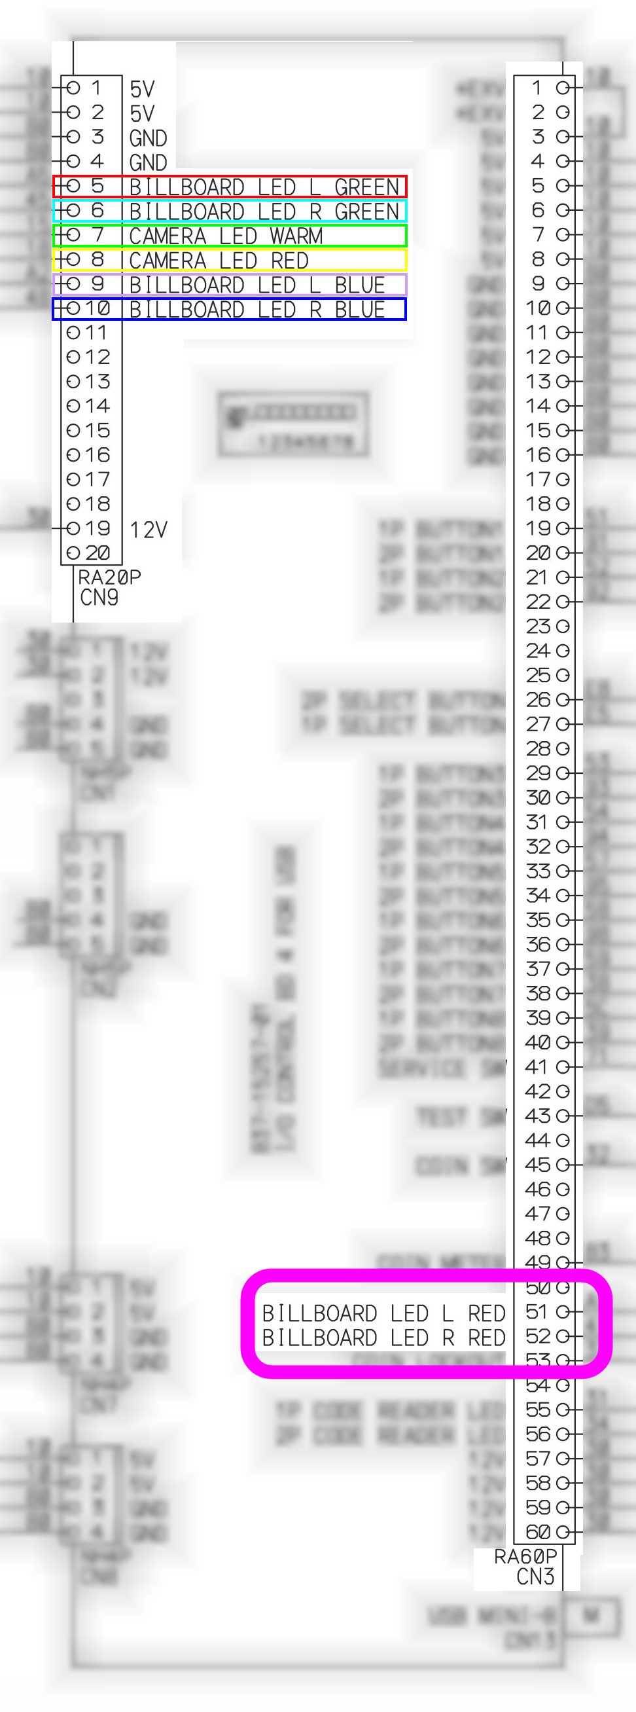
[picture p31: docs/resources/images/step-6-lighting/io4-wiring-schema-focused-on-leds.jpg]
Official IO4 wiring diagram centered on the LED pins: CN9 connector (RA20P) for BILLBOARD LED L/R GREEN, CAMERA LED WARM/RED and BILLBOARD LED L/R BLUE, and CN3 connector (RA60P) pins 51-52 for BILLBOARD LED L/R RED
        

    Build the harness following the diagram below, long enough for a clean installation: **3 meters on the player 1 side, 2 meters on the player 2 side**. For the 12V, **do not use the CN9 12V pin**: connect directly to the cabinet's LED 12V power supply, so as not to put unnecessary load on the I/O board.

    Wiring harness for the billboard lighting: from the IO4 (CN9 pins 5, 6, 9 and 10, and CN3 pins 51-52 already wired in step 4) and the internal 12V power supply, making two 8-pin JST-SM connectors - P1 side (3 meters, with a bridge from pins 1-4 to 5-8 to also power CENTER LED) and P2 side (2 meters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

    Once the harness is done, plug it into the IO4, connect the 12V, then plug the two original 8-pin JST-SM connectors into your new cable. **Test the continuity of all your cables before installing them**, to rule out any badly crimped pin.

    !!! lightbox
        Male 8-position JST-SM wiring harnesses that handle the billboard and woofer LEDs, unplugged from the connector wired to the LED controller on a FiNALE cabinet

    !!! tip "The camera LEDs"
        If you plan to install the optional cameras, crimp a few extra connectors now:

        - Female 2-pin JST-SM on CN9 pins 7 and 8, for the `CAMERA LED WARM` and `CAMERA LED RED` signals respectively.
        - Female 2-pin JST-SM on CN3 pins 55 and 56, for the `1P CODE READER LED` and `2P CODE READER LED` signals in that order.

## In summary
!!! tldr "The big picture"
    For the button LEDs and the cabinet background:

    * Build two proxies, each based on a Raspberry Pi Pico and a `Pico-2CH-RS232`.
    * Install each proxy between its LED controller and the RS-232 to USB adapter.
    * Plug the adapter into the USB hub, and the hub into USB port #2 of the ALLS.

    For the billboard and the woofers:

    * Either: connect the cabinet's existing connectors to the [conversion PCB]({{IO4_CONVERSION_PCB}}).
    * Or: make and install a wiring harness running from the IO4 and plugging into the cabinet's existing connectors.

---

Let's move on to [Step 7: Cameras (Optional)](step-7-cameras.md).

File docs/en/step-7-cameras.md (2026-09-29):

---
title: "📷 7 - Cameras (optional)"
---

# 📷 Step 7: Cameras (Optional)

At this point, only one feature still separates your conversion from a real *DX*: **the cameras**. The game uses them very little, and they are widely considered optional. But if you want to get as close as possible to a real *DX*, they are fortunately quite simple to install.

## Technical explanation

??? note "Click here for the technical explanation"
    A real *DX* has **three cameras**: one pointed at the players, and two that serve as QR-code readers for the *DX Pass*.

    - **The player camera**: a simple USB UVC camera, at 1280x960 with a 95° HFOV. [[reference]]({{SHIKINO_PLAYER_CAMERA_REFERENCE}})
    - **The QR-code reader cameras**: two USB UVC cameras, at 640x480 with a 50° FOV.

    !!! info "DX Pass"
        DX Passes are physical cards that players get printed on the "Sega CardMaker" cabinet. That cabinet is rare outside Japan, and even rarer in working printing order. Moreover, DX Passes are nowadays automatically linked to the player's account: the physical card is no longer needed. **The QR-code readers are therefore largely optional**, even useless.

        Some in-game events only trigger by scanning specific cards, but most private servers unlock them by default.

    **For the player camera, any USB UVC camera will do**, even a cheap webcam. The game only uses it to show a photo of the players at the end of each song, an option most players turn off to save time.

    **For the QR-code readers, the game is much stricter**: you absolutely need USB UVC cameras able to film at 640x480, with a precise FOV, otherwise the QR-codes are not recognized.

    In both cases, the game provides **dedicated lighting for each camera**, driven by the IO4. Connecting it is not essential, but without proper lighting, the QR-code readers are likely to work very poorly. For the player camera, lighting becomes necessary if your cabinet is in a dark room. The game also drives a red LED, which warns players that the camera is filming.

    The cameras connect to the ALLS over USB: the player camera directly to the motherboard, the two QR-code reader cameras to the USB hub that already hosts the LED controllers' RS-232 to USB adapter (see [step 6](step-6-lighting.md)).

## Player camera (in-game photos)

Every camera model is different, so a universal mount is hard to offer. The best option is to **design a 3D-printable mount** to install at the top of the cabinet, using the existing screws of the acrylic panel.

* **Installation on the cabinet:** 3D printing.
* **Connection to the ALLS:** USB, on port **#3**.
* **Connection to the IO4:**
    - **CAMERA LED WARM: CN9 - Pin 7**: cathode of the white LED ring that lights the filmed area.
    - **CAMERA LED RED: CN9 - Pin 8**: cathode of the red LED that tells players the camera is filming.

If you made your own wiring harness and followed the suggestion in [step 6](step-6-lighting.md), you already have a connector ready for the IO4. With the conversion PCB, two dedicated connectors are available for these LEDs.

!!! lightbox
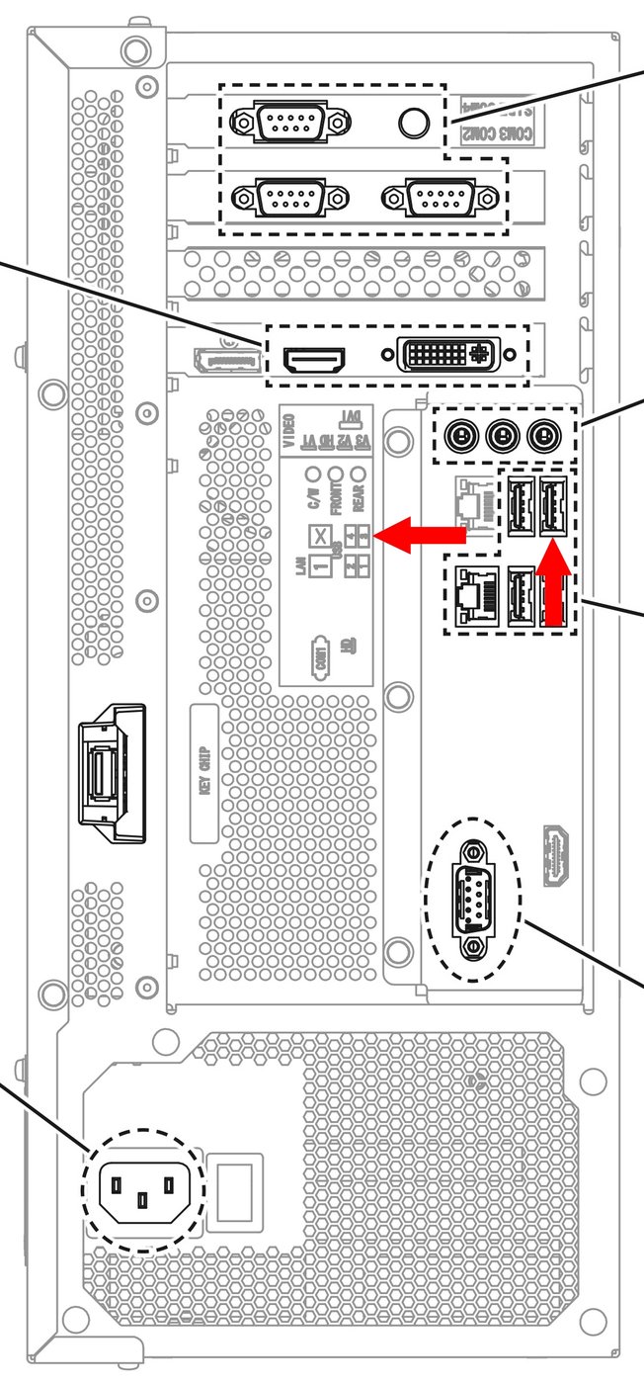
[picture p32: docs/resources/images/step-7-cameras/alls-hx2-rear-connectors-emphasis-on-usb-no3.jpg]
ALLS diagram: USB port #3 used for the player camera, highlighted by the red arrow
    
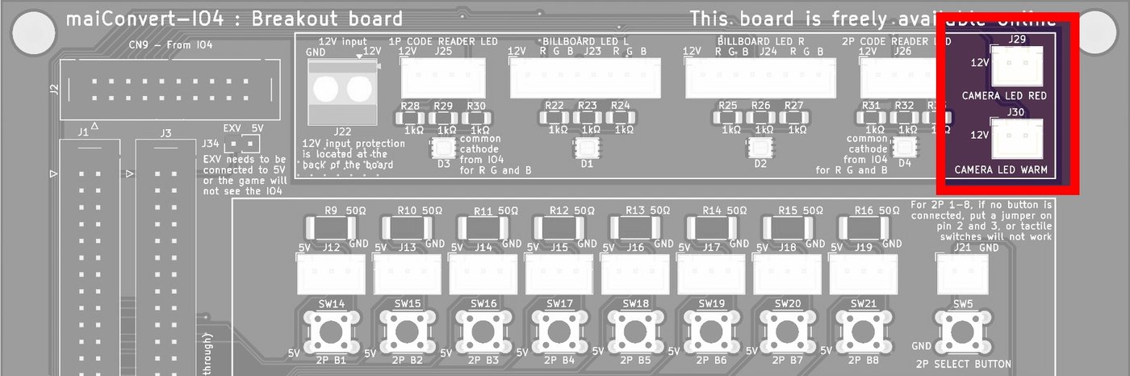
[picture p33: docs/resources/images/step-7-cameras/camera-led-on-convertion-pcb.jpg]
Conversion PCB [maiConvert-IO4]({{IO4_CONVERSION_PCB}}): location of connectors J29 ( ) and J30 ( )
    

## QR-code reader cameras

Ideally, get **two small 30mm x 25mm modules**: they fit [the 3D model designed by SpiralGlide](spiralglide-resources.md#qr-code-reader-mount-dx-pass-reader), which attaches using the existing screws of the acrylic panel.

* **Installation on the cabinet:** [3D printing](spiralglide-resources.md#qr-code-reader-mount-dx-pass-reader).
* **Connection to the ALLS:** USB, through the USB hub plugged into port **#2** in [step 1](step-1-alls-and-psu.md). Any port on the hub will do.
* **Connection to the IO4:**
    - **1P CODE READER LED: CN3 - Pin 55**: common cathode (R, G and B) of the LED strip lighting the player 1 reader.
    - **2P CODE READER LED: CN3 - Pin 56**: common cathode (R, G and B) of the LED strip lighting the player 2 reader.

If you followed the suggestion in [step 6](step-6-lighting.md), you already have a connector ready for these two signals. They are also available on the conversion PCB.

**For the game to identify the cameras, each one must film a specific QR-code**: *SDEZ01* on the player 1 side, *SDEZ02* on the player 2 side. SpiralGlide's 3D model has a slot of the right size for these codes. Print [this PDF](../resources/images/step-7-cameras/codes-for-qr-code-readers.pdf) on A4, with a properly calibrated printer, to get QR-codes of the right size, then stick them in place.

If you chose the cameras from the [shopping list](equipment.md), their lens is adjustable: you can tweak the focus.

!!! tip "The QR-code reader LEDs"
    *DX* originally uses an RGB LED strip, but its three colors share a single cathode driven by the IO4: they always light up together, at (almost) the same intensity. **A warm white LED strip will give the same result.**

    **Do not point the LEDs directly at the camera lens.** Light the plastic wall instead, so the light diffuses onto the card. Front lighting creates a glare that blinds the camera and prevents the QR-code from being read.

!!! tip "Installing the camera modules"
    **The game is very strict about the cameras' orientation**: if the angle is off, it will not read the cards' QR-codes. Also beware: a default QR-code that reads fine does not guarantee the cards will, so run some tests. To adjust a module's height and tilt, you can for example add nuts on its screws. It is not ideal, but it works.

    Test the detection in the game's Test menu. Unfortunately, nothing beats trial and error for this step.

!!! lightbox
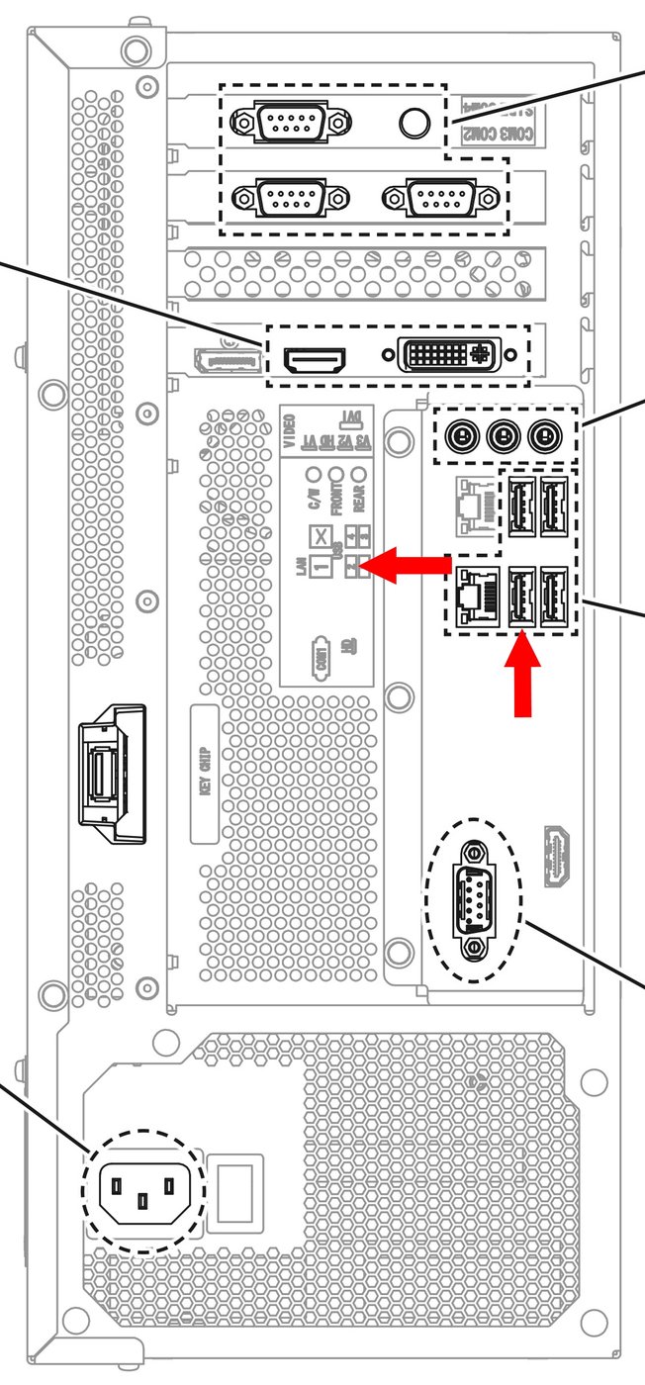
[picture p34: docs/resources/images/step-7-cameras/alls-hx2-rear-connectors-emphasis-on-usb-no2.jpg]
ALLS diagram: USB port #2 used for the QR-code reader cameras' hub, highlighted by the red arrow
    
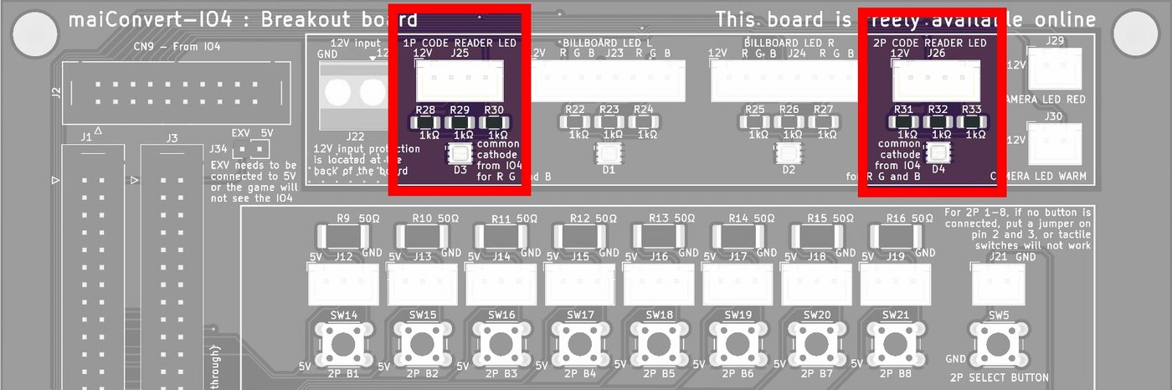
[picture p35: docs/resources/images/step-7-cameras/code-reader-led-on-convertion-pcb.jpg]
Conversion PCB [maiConvert-IO4]({{IO4_CONVERSION_PCB}}): location of connectors J25 ( ) and J26 ( )
    
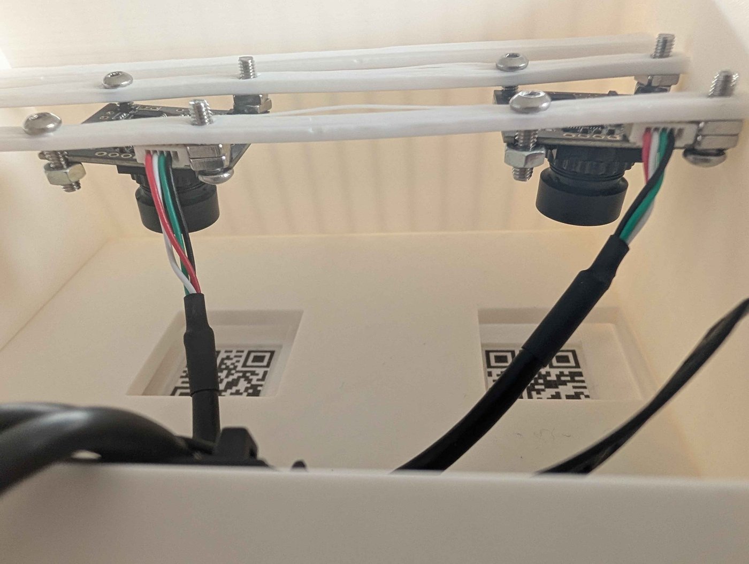
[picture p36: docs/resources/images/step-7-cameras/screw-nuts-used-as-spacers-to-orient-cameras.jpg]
Nuts used as spacers on the screws of the 3D-printed model, to adjust the height and angle of the camera modules above the QR-codes
    

## Validating the installation

The game's Test menu has a page dedicated to the cameras. The game looks for **three video streams** there, two of which must film the default QR-codes [SDEZ01](../resources/images/step-7-cameras/SDEZ01.svg) and [SDEZ02](../resources/images/step-7-cameras/SDEZ02.svg). Those two cameras are recognized automatically thanks to their QR-code, and the remaining camera is assigned to the players.

**If all three cameras are recognized in the right order, congratulations, the installation is complete!**

---

Let's move on to the [Conclusion](conclusion.md).

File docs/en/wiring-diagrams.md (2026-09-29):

---
title: "Wiring diagrams"
---

# 🖨️ Wiring diagrams

The [official manuals](official-manuals.md) contain, on their very last pages, the complete wiring diagram of the cabinet (A3-format plates, one per manual of several dozen MB). To avoid having to download an entire manual and zoom into a PDF reader just to find a wire, here are those plates extracted in high resolution.

_(Click a plate to open it at full resolution in a new tab. Each plate is preceded by the list of boards/modules that appear on it, with their part number, so you can find a board with `Ctrl+F`. The coordinates in brackets, e.g. **[C-3]**{: .wiring-coord }, refer to the reference grid printed around the edge of each plate - columns A to G, rows 1 to 6 - and indicate where the part is on the diagram.)_

## maimai DX manual

Chapter *22 総合配線図* ("general wiring diagram"), pages 193 to 196 of the [maimai DX manual](../resources/pdfs/maimai-dx-instruction-manual-full.pdf).

### Plate 1/4 - Power, *ALLS* PC, amp and player screens

* `MMT-1050` **ASSY AC UNIT** **[A-1]**{: .wiring-coord } - mains input block (noise filter, fuse, IEC socket)
* `MMT-4200` **ASSY XFMR** **[C-1]**{: .wiring-coord } - power transformer
* `MMT-4300` / `601-13203-63` **ASSY ROUTER (ROUTER RTX830 BD MMT)** **[F-1]**{: .wiring-coord } - network router board
* `MMT-4100` **ASSY ELEC BD** **[A-2]**{: .wiring-coord } - main electronics board, which brings together:
    * `838-15228` **2.1CH 40W STEREO AMP BD** ×2 **[B-2/B-3]**{: .wiring-coord } - Player 1 and 2 audio amps
    * `839-1363-01` **HEADPHONE AMP BD SHC** ×2 **[B-5/B-6]**{: .wiring-coord } - Player 1 and 2 headphone amps
    * `400-5489-15024` **SW REGU VS150E-24** **[A-3]**{: .wiring-coord } - 24V switching power supply
    * `400-5464-01505` **SW REGU VS15C-5** **[A-4]**{: .wiring-coord } - 5V switching power supply
* `849-1004` **ASSY CASE ALLS HX2 W HDD** **[E-4]**{: .wiring-coord } - the *ALLS* PC case itself
* `MMT-1000` / `MMT-1500` **ASSY CABINET 1P / 2P** **[D-2/G-2]**{: .wiring-coord } - player screens (`200-6280` **LCD DSPL 43 LED**)
* `MMT-1200` / `MMT-1700` **ASSY SW BASE 1P / 2P** **[C-5/D-4]**{: .wiring-coord } - button bases

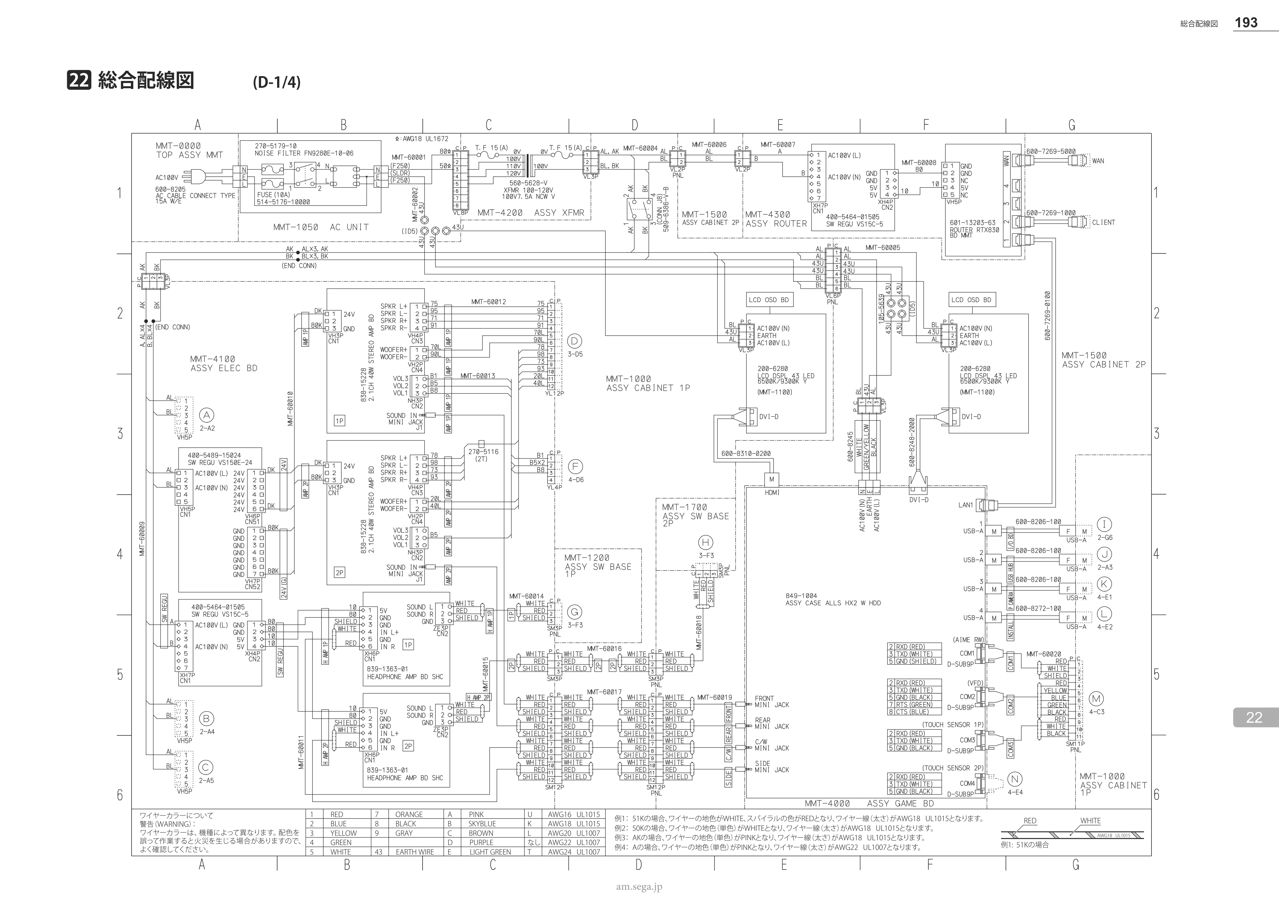
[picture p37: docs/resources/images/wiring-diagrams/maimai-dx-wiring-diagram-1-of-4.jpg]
maimai DX wiring diagram, plate 1 of 4


---

### Plate 2/4 - Buttons, button LEDs, USB hub and I/O board

* `MMT-1200` / `MMT-1700` **ASSY SW BASE 1P / 2P** **[A-1]**{: .wiring-coord } - button bases
* `837-15070-04` **IC BD LED DRV32CH RS232** ×2 **[E-2/D-2]**{: .wiring-coord } - LED driver, one per side
* `837-20008` **4PORT USB HUB BD MINIB TO A** **[B-4]**{: .wiring-coord } - 4-port USB hub
* `837-15067-02` **IC BD USB TO 4SERIAL 232 IF** **[A-5]**{: .wiring-coord } - USB to 4-port serial adapter
* `837-15257-01` **I/O CONTROL BD 4 FOR USB** **[E-4]**{: .wiring-coord } - the **IO4** board (JVS), see [step 4](step-4-io-board.md)
* `MMT-1000` / `MMT-1500` / `MMT-1900` **ASSY CABINET 1P / 2P / SIDE COVER BASE 1P** **[G-3/G-6/G-1]**{: .wiring-coord }

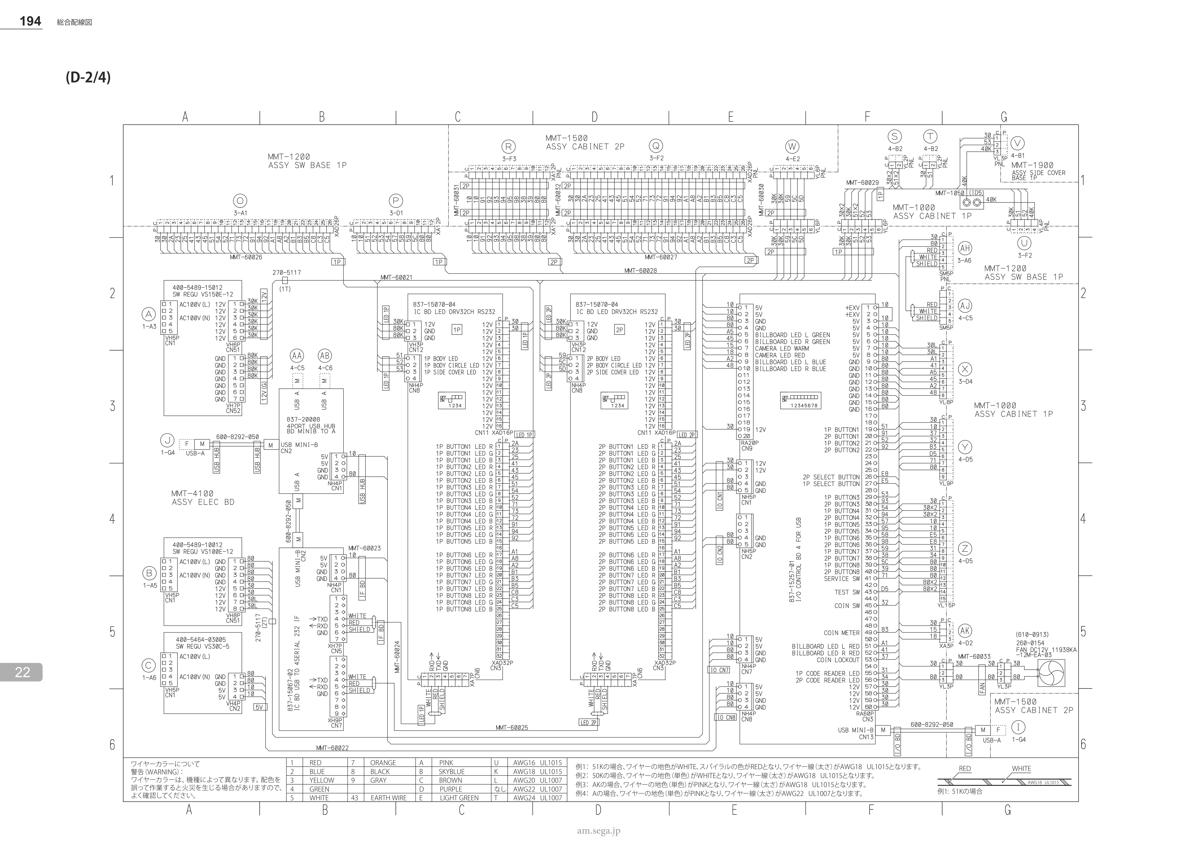
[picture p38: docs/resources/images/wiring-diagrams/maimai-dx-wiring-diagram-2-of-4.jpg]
maimai DX wiring diagram, plate 2 of 4


---

### Plate 3/4 - Buttons, touch ring sensor, billboard

* `MMT-2000` **ASSY BUTTON SWITCH** ×8 **[B-1→B-4]**{: .wiring-coord } - buttons, each with:
    * `838-15235-01` **LED BD RGB 3X1BLOCK 5050** **[B-1→B-4]**{: .wiring-coord } - button RGB LED
    * `370-5359` **PHOTO INTERRUPTER OJ-555S-A5** **[C-1→C-4]**{: .wiring-coord } - optical button-press sensor
* `837-20015` **HEADPHONE JACK BD** (`MMT-1070`) **[E-3]**{: .wiring-coord } - headphone jack board
* `509-6483` **TOUCH SENSOR UNIT TPK** **[B-6]**{: .wiring-coord } - touch ring sensor board
* `MMT-1800-01` **ASSY BILLBOARD** **[F-5]**{: .wiring-coord } - billboard at the top of the cabinet
    * `390-5768` **LED TAPE RGB** **[F-4/G-4]**{: .wiring-coord } - billboard RGB LED strips
    * `MMT-1080` speakers `130-5310` **[F-5/G-5]**{: .wiring-coord }
* `390-7244` **LED TAPE WHITE M3528W-A** **[E-2]**{: .wiring-coord } - white LED strips of the ring
* `130-5280-01` **WOOFER 4OHM 80W** **[E-6]**{: .wiring-coord }

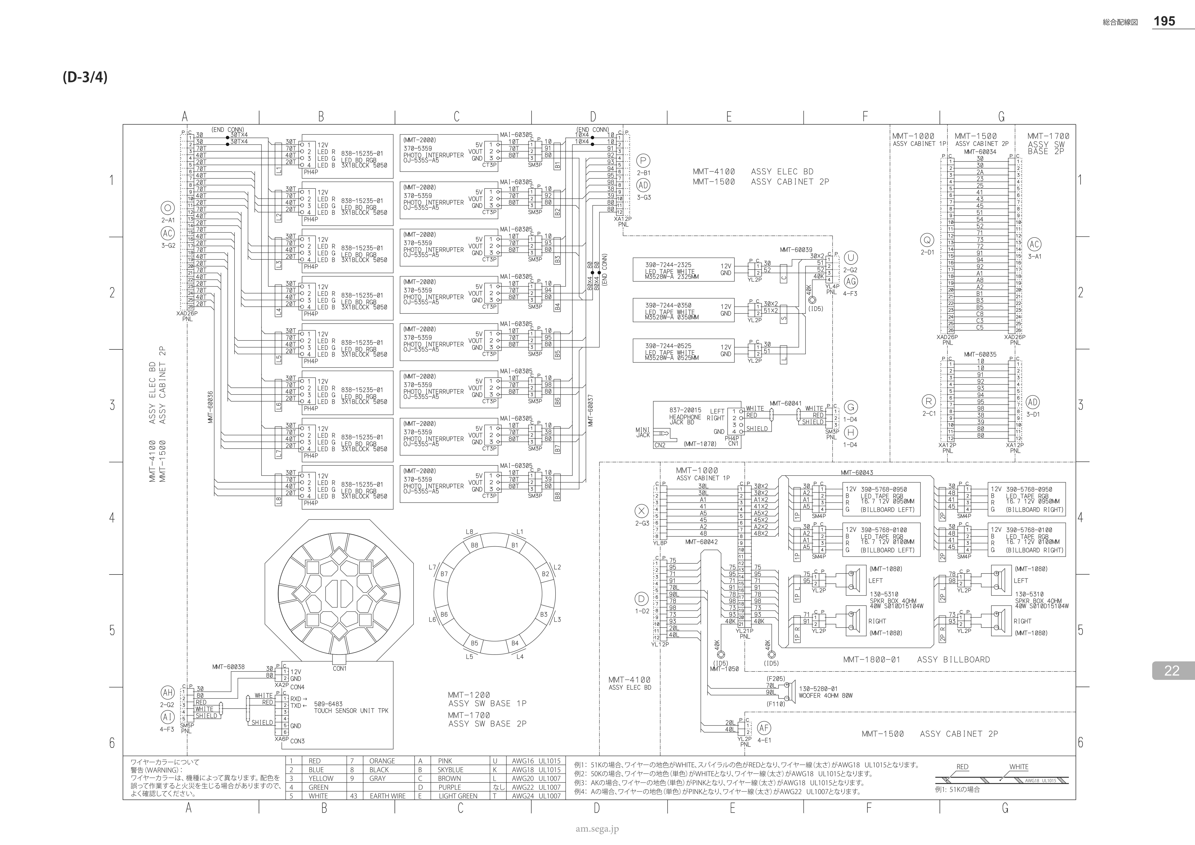
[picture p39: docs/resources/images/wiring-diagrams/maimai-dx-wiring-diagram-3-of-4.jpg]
maimai DX wiring diagram, plate 3 of 4


---

### Plate 4/4 - Cameras, Aime reader, coin mech and entry panel

* `MMT-1350` / `MMT-1370` **ASSY PLAYER CAMERA / PLAYER CAMERA UNIT** **[D-1]**{: .wiring-coord } - player cameras
    * `601-13249` **CAMERA KBCR-S03MU-HPB2033-C300** **[D-1]**{: .wiring-coord }, see [step 7](step-7-cameras.md)
* `MMT-1440` **ASSY AIME AND VFD** **[B-3]**{: .wiring-coord } - Aime reader module (AIME RW UNIT) and display
    * `200-6275` **VFD GP1232A02A FUTABA** **[A-4]**{: .wiring-coord }, see [step 3](step-3-aime-reader.md)
* `MMT-1470` **ASSY CODE READER** **[B-5]**{: .wiring-coord } - QR code reader
    * `601-13216-01` **USB CAMERA MS-M33NU2AMSH43-S2** **[A-5/A-6]**{: .wiring-coord }
* `MMT-1400` **ASSY CENTER TOWER** **[B-4]**{: .wiring-coord } - center tower
* `MMT-1450` **ASSY ENTRY PANEL** **[D-3]**{: .wiring-coord } - player select buttons
    * `509-5970` **SW PB OBSF-24TR** **[D-3]**{: .wiring-coord } - Sanwa part
* `MMT-1420` **ASSY SELECTOR DOOR** **[G-5]**{: .wiring-coord } - selector/coin mech
    * `220-5846-91-01` **[G-5]**{: .wiring-coord } - coin acceptor mechanism
    * `220-5798-01` **MAG CNTR 4P MZ674** **[F-6]**{: .wiring-coord } - coin counter
* `MMT-1460` **SW UNIT** **[G-5]**{: .wiring-coord } - test/service buttons
    * `838-14548-10` **SW & VOL BD** **[G-5]**{: .wiring-coord }
* `MMT-1900` / `MMT-1950` **ASSY SIDE COVER BASE 1P / 2P** **[A-1/G-2]**{: .wiring-coord }

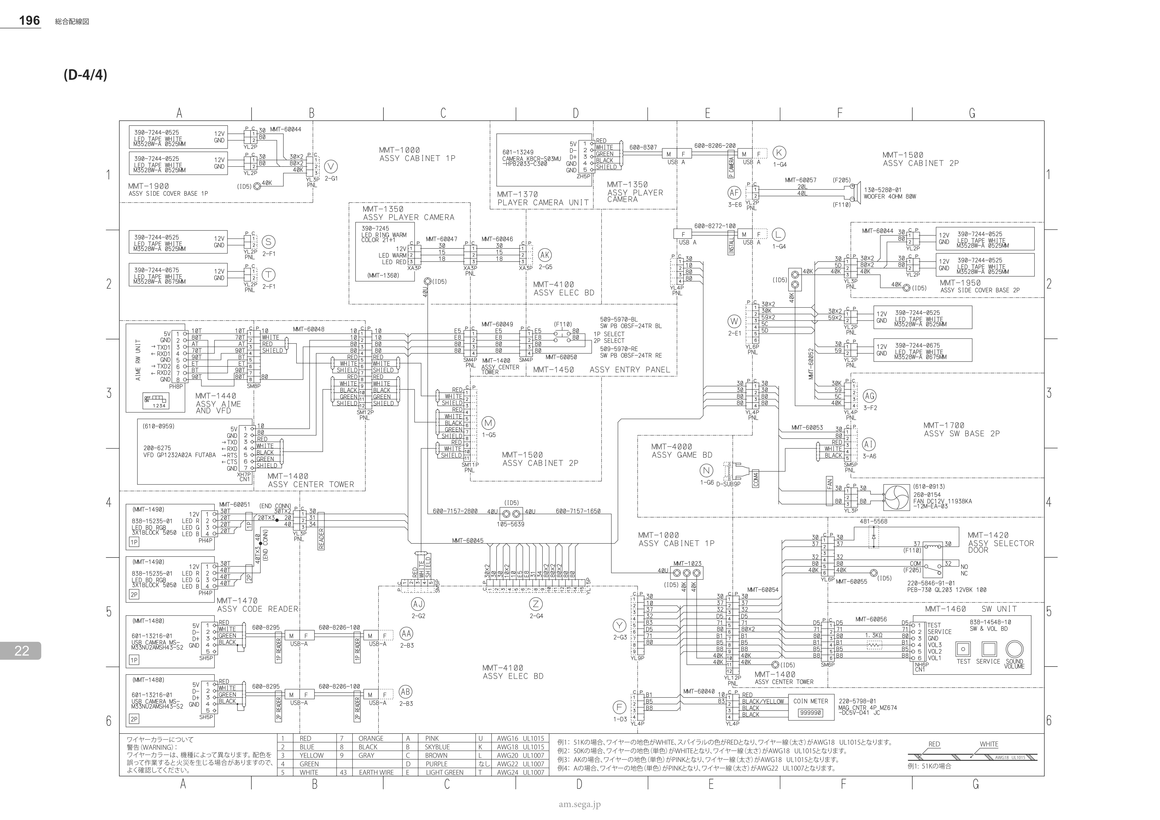
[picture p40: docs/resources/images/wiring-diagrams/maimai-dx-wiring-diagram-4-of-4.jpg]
maimai DX wiring diagram, plate 4 of 4


---

## maimai PiNK manual

Chapter *25 WIRING DIAGRAM*, pages 189 to 193 of the [maimai PiNK manual](../resources/pdfs/maimai-pink-manual-full.pdf).

### Plate 1/4 - Power, screen and coin selector

* `MAI-1050` **AC UNIT** **[B-1]**{: .wiring-coord } - mains input block
* **ASSY LCD** **[F-1]**{: .wiring-coord } - Player 1, screen (`200-6226-91` **ASSY LCD DSPL 42 TYPE LED Y**)
* coin acceptor mechanism
    * `MAI-1420` **ASSY SELECTOR DOOR** **[A-4]**{: .wiring-coord } - Japan version
        * `220-5846-01` **PFB-730 QL203 12VBK 100** **[B-3]**{: .wiring-coord }
    * `MAI-1420-01` **ASSY SELECTOR DOOR EXP** **[C-4]**{: .wiring-coord } - export version
        * `220-5842` **ELEC CC REJR SG-828** **[C-3]**{: .wiring-coord }
* **XFMR WIRING** **[B-5→G-6]**{: .wiring-coord } - multi-voltage transformers
    * `560-5515-V-91` **[B-6]**{: .wiring-coord } - 100V zone variant
    * `560-5599` **[C-5]**{: .wiring-coord } - 110V to 240V zone variant (repeated at several voltages on the plate)

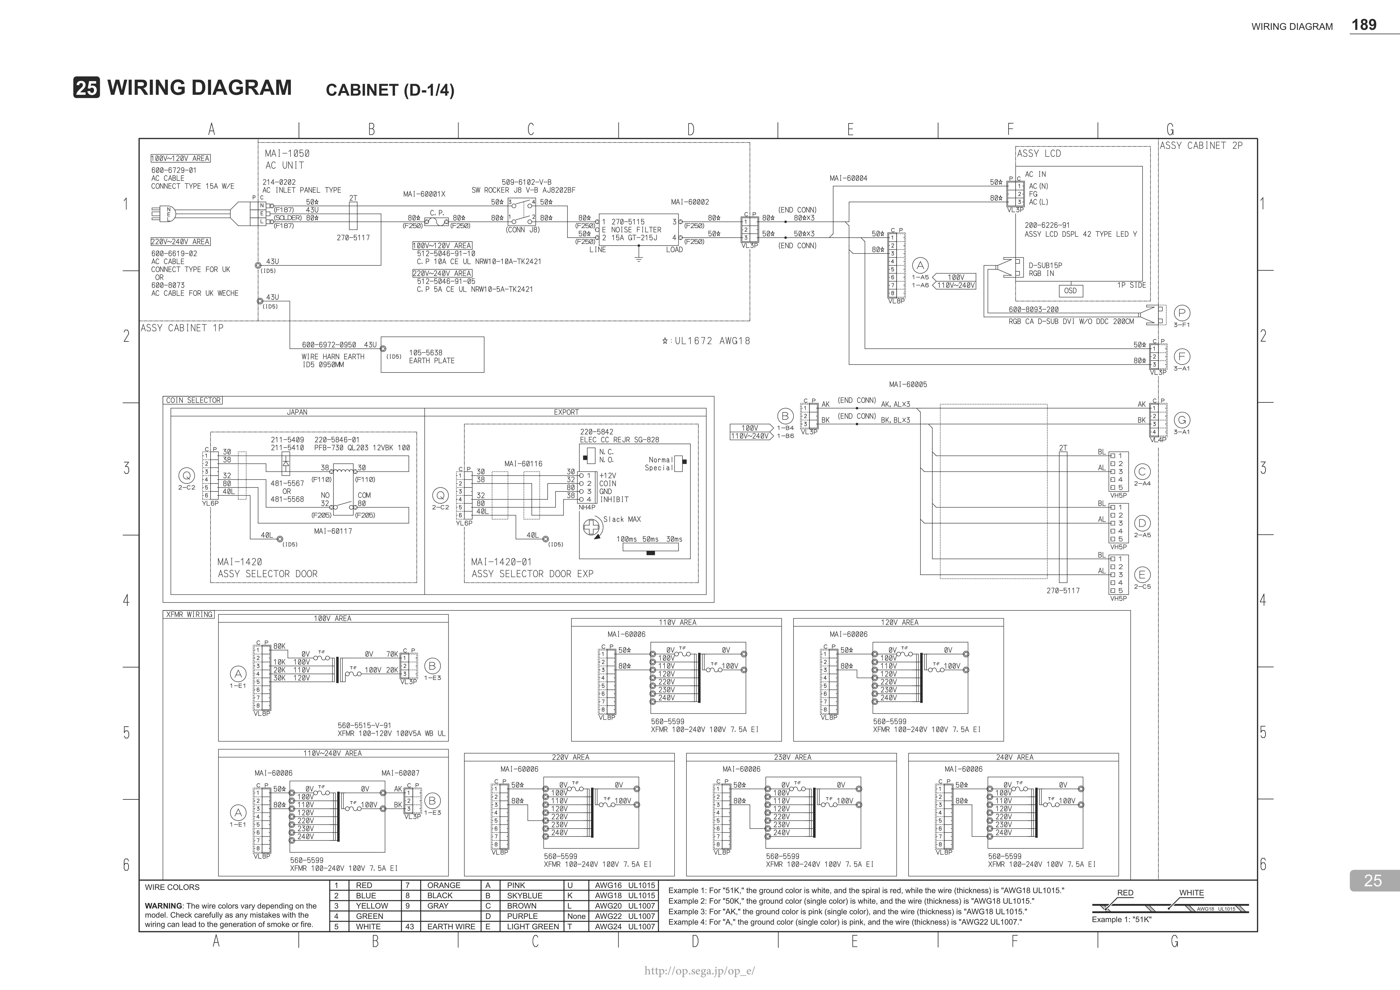
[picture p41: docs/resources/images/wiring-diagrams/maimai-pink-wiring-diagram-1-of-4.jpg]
maimai PiNK wiring diagram, plate 1 of 4


---

### Plate 2/4 - Aime reader, speakers, LEDs and power supplies

* `MAI-1400` **ASSY COIN CHUTE TOWER** **[B-2]**{: .wiring-coord } - center tower
    * `838-14971` **NFC RW BD TN32MSEC003S** **[D-1/D-2]**{: .wiring-coord } - the Aime card reader board, replaced in [step 3](step-3-aime-reader.md)
* `MAI-1420` **ASSY SELECTOR DOOR** **[D-2]**{: .wiring-coord }
    * `220-5798-01` **MAG CNTR 4P MZ674** **[C-2]**{: .wiring-coord } - coin counter
* `MAI-1460` **SW UNIT** (`838-14548-10` **SW & VOL BD**) **[D-3]**{: .wiring-coord } - test/service and volume buttons
* `MAI-0500` **ASSY SPEAKER** **[G-1]**{: .wiring-coord } - speakers
    * `838-15228` **2.1CH 40W STEREO AMP BD** ×2 **[F-2/F-3]**{: .wiring-coord }
    * `130-5296` enclosure **[G-1]**{: .wiring-coord }
    * `130-5280` woofer **[G-2]**{: .wiring-coord }
* `MAI-1090` **FAN UNIT DC12V** (`260-0139`) **[D-4]**{: .wiring-coord } - fan
* `MAI-4000` **ASSY SW RGLTR** **[C-4]**{: .wiring-coord } - switching power supplies (`400-5489-15024`/`15012`)
* `MAI-1080` **CENTER LED / ROOF LED (L) / ROOF LED (R)** ×3 **[F-3/F-4]**{: .wiring-coord }
    * `MAI-1070` **WOOFER LED** **[E-5]**{: .wiring-coord } - decorative LEDs (`838-15235-01` **LED BD RGB**)

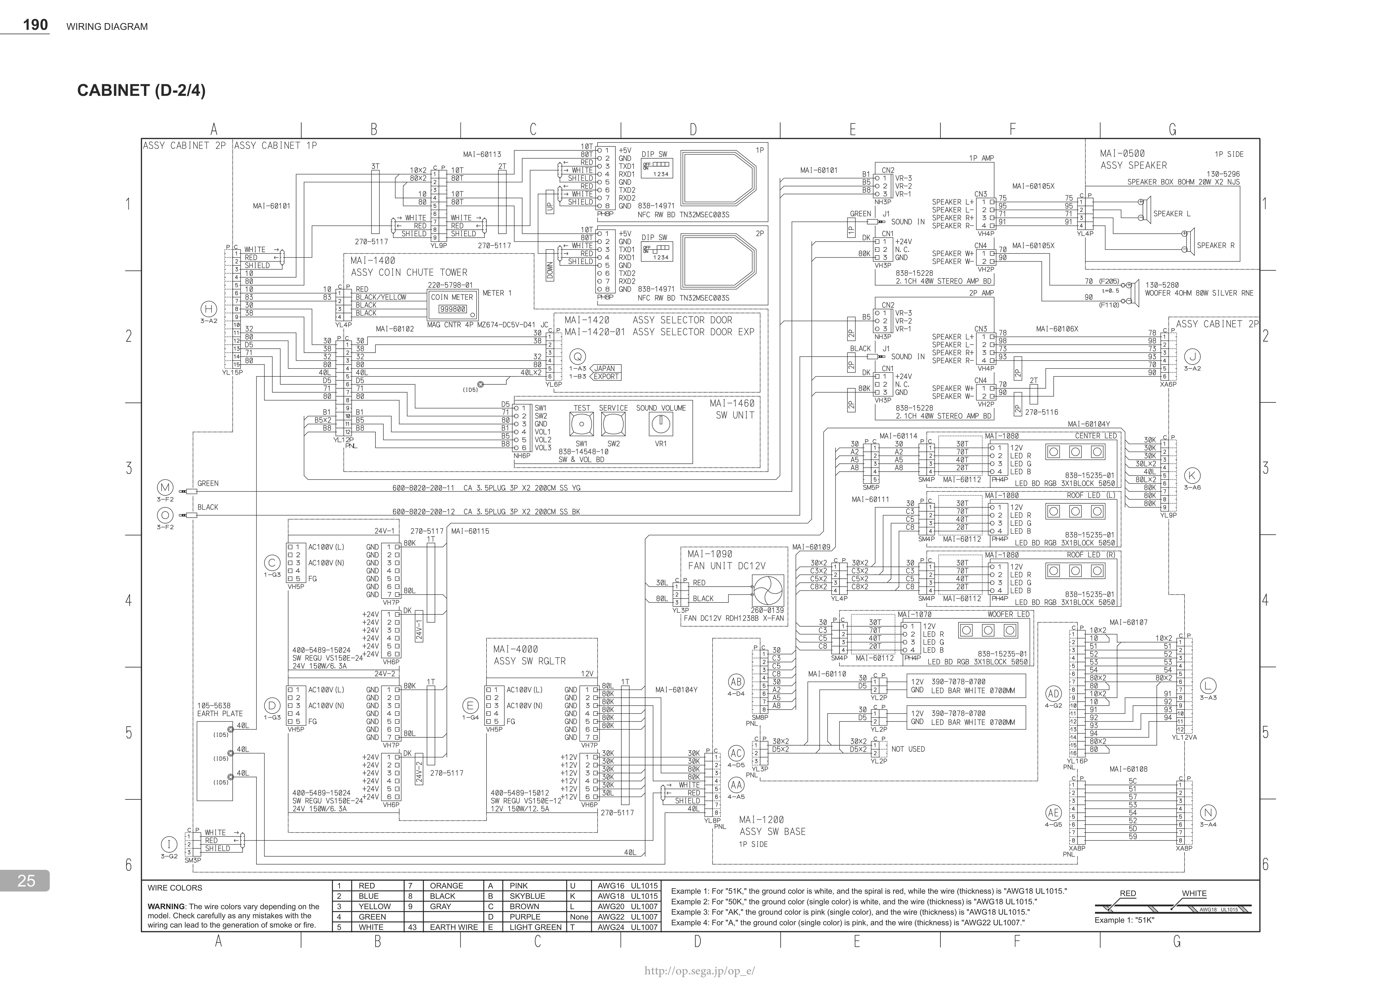
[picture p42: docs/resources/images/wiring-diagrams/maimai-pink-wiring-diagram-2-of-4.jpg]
maimai PiNK wiring diagram, plate 2 of 4


---

### Plate 3/4 - I/O board (JVS), Serial-USB adapter, touch controller and *RingEdge 2* PC

* **ASSY LCD** **[G-1]**{: .wiring-coord } - Player 2, screen (`200-6226-91` **ASSY LCD DSPL 42 TYPE LED Y**)
* `837-14505` **I/O CONTROL BD FOR JVS** **[D-1]**{: .wiring-coord } - the IO3 board, replaced by the IO4 in [step 4](step-4-io-board.md)
* `837-15067-02` **IC BD USB TO 4SERIAL 232 IF** **[F-2]**{: .wiring-coord } - the RS-232 to USB adapter mentioned in [step 6](step-6-lighting.md)
* `838-15221` **SERIAL I/F BD TOUCHPANEL GUNZE** **[D-4]**{: .wiring-coord } - touchscreen controller board
* **ASSY CASE RGE2 W M2G S64G** **[E-3/E-4]**{: .wiring-coord } - *RingEdge 2* PC
    * `846-5003D` **[E-3]**{: .wiring-coord } (Japan version)
    * `846-5003D-02` **[E-4]**{: .wiring-coord } (export version)
* `MAI-4100` **ASSY ROUTER** (`601-12336-34` **ROUTER RT107E BD MAI**) **[F-6]**{: .wiring-coord }

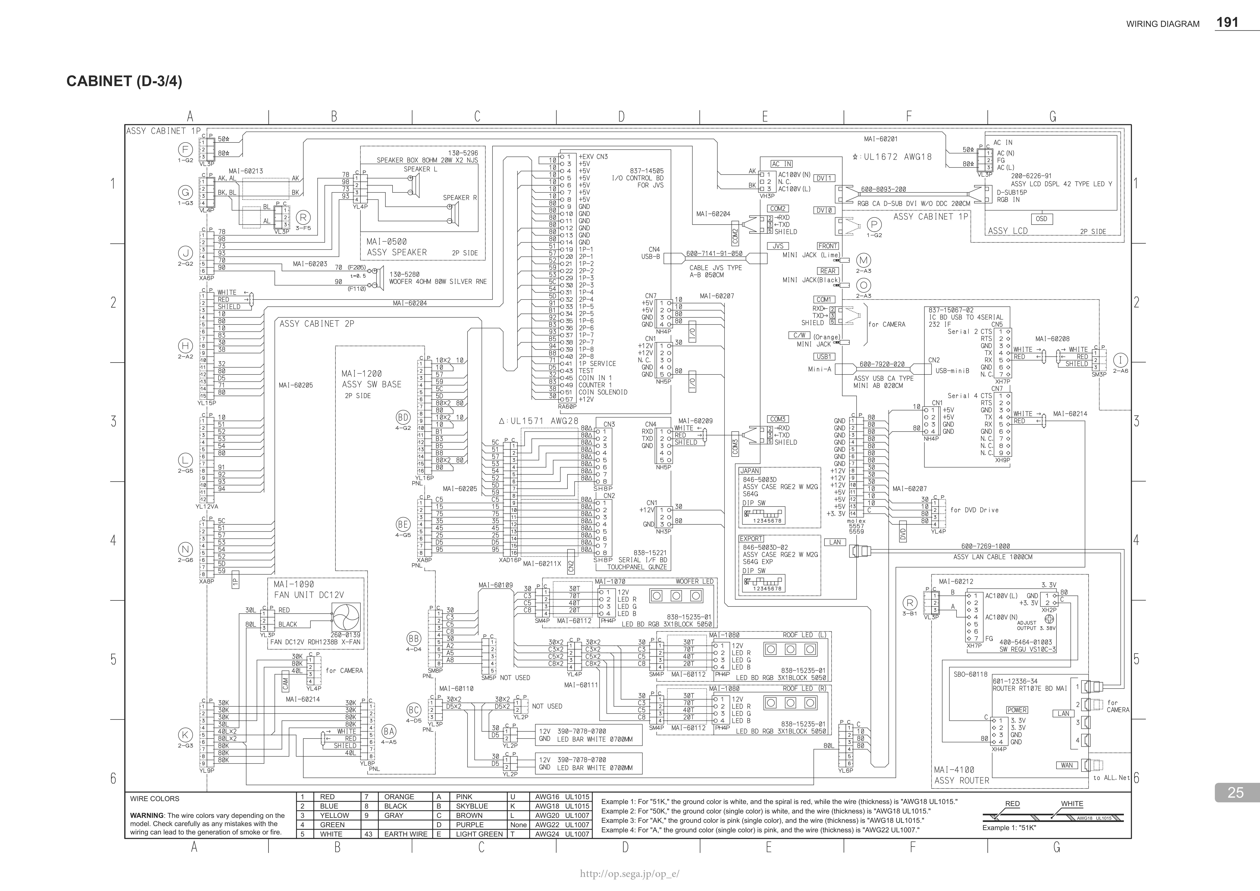
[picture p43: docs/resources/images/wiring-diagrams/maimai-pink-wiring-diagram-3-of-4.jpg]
maimai PiNK wiring diagram, plate 3 of 4


---

### Plate 4/4 - Buttons, LED controller and touch ring

* `MAI-1200` / `MAI-1201` **ASSY SW BASE** **[D-1/D-5]**{: .wiring-coord } - base and layout of the 8 buttons
    * `838-15235-01` **LED BD RGB** **[D-1→D-3]**{: .wiring-coord }
    * `370-5359` **PHOTO INTERRUPTER OJ-535S-A5** **[E-1→E-3]**{: .wiring-coord }
* `837-15070-02-91` **IC BD LED DRV32CH RS232** **[C-4]**{: .wiring-coord } - the LED controller mentioned in [step 6](step-6-lighting.md)
* `509-6384` **TOUCH SENSOR PANEL UNIT** **[E-5]**{: .wiring-coord } - touch ring sensor board

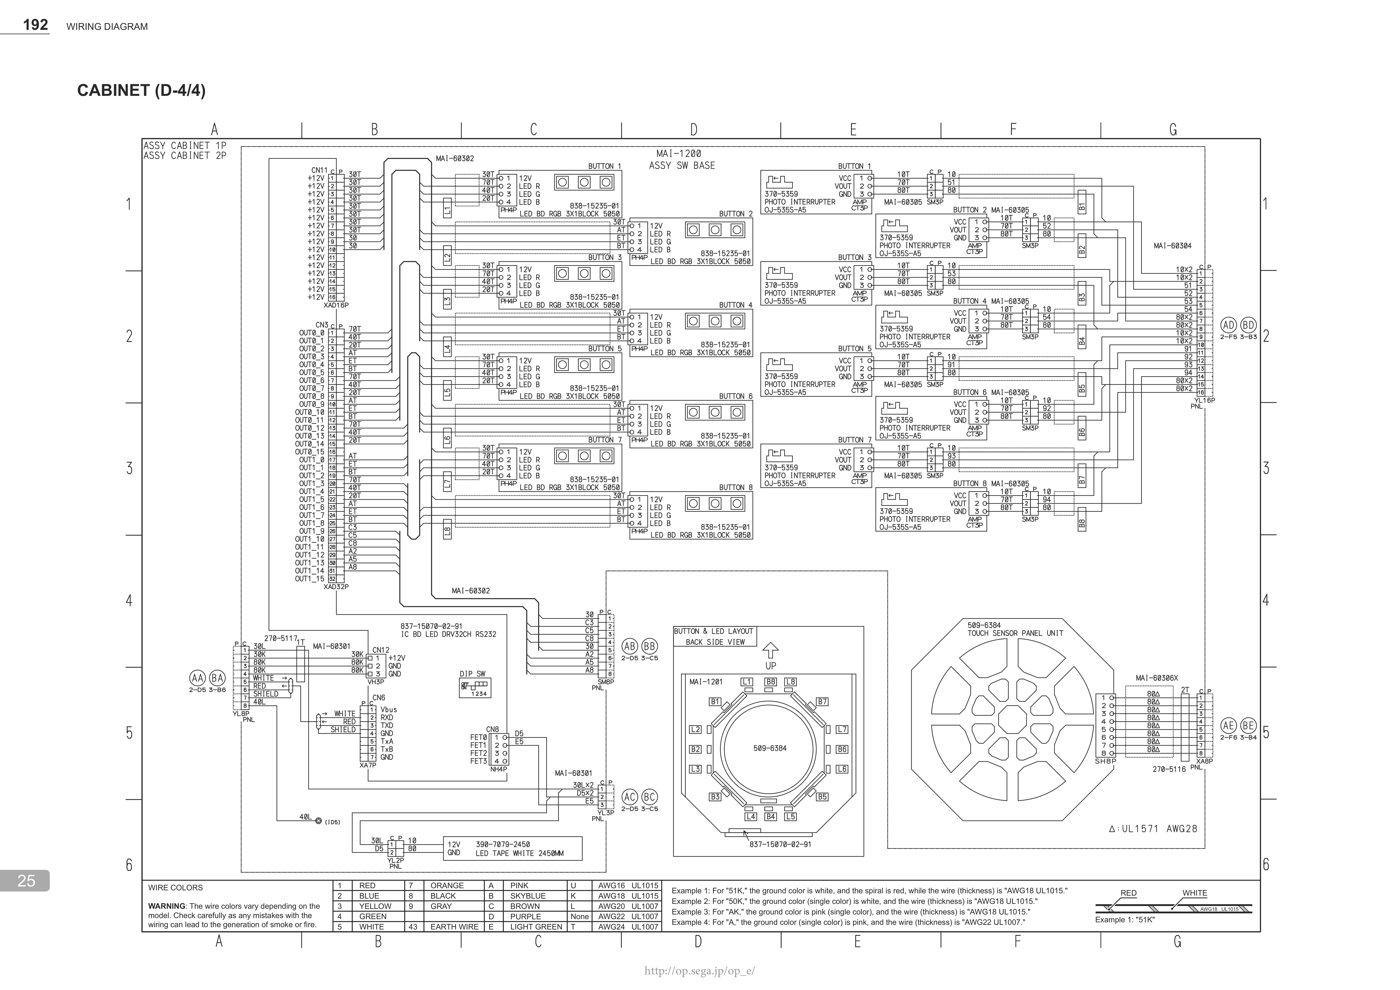
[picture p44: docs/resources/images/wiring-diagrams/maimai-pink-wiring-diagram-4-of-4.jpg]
maimai PiNK wiring diagram, plate 4 of 4


---

### Optional camera kit - Player camera and control box

* `MAI-3100` **ASSY CAMERA SW RGLTR** **[C-1]**{: .wiring-coord } - camera PSU
    * `400-5489-05012` **SW REGU VS50E-12** **[C-3]**{: .wiring-coord }
* `MAI-3000` **ASSY CAMERA BOX** **[D-1]**{: .wiring-coord } - camera box, see [step 7](step-7-cameras.md)
    * `838-15222` **MOVIE CAMERA CTRL BD** **[D-3]**{: .wiring-coord }
    * `601-12827-01` **BD CAMERA KBCR-S01MG-HPB1022** **[F-2]**{: .wiring-coord }
* `MAI-3050` **ASSY LCD W/CUSHION** **[F-3]**{: .wiring-coord } - feedback screen
    * `200-6211` **LCD MODULE NL6448BC18-01 NLT** **[F-3]**{: .wiring-coord }
* **ASSY CASE RGE2 W M2G S64G** **[C-3/C-4]**{: .wiring-coord } - *RingEdge 2* PC
    * `846-5003D` **[C-3]**{: .wiring-coord } (Japan version)
    * `846-5003D-02` **[C-4]**{: .wiring-coord } (export version)
* `MAI-4100` **ASSY ROUTER** (`601-12336-34` **ROUTER RT107E BD MAI**) **[B-5]**{: .wiring-coord }

maimai PiNK wiring diagram, optional camera kit

---

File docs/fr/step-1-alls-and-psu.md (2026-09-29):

---
title: "🛠️ 1 - ALLS et PSU"
---

# 🛠️ Étape 1 : Le remplacement du PC central (ALLS)

L'ancien PC *RingEdge 2* ne peut pas faire tourner *DX* : il vous faut un PC **ALLS HX2**. En plus d'un matériel plus récent et plus performant, le système d'exploitation change radicalement entre les deux machines. **Le remplacement est obligatoire.**

## Explications techniques

??? note "Cliquez ici pour l'explication technique"
    Le **ALLS HX2** est le système natif de DX, c'est celui que nous devons substituer au RingEdge 2 de FiNALE. Un **ALLS MX2** convient également : ses caractéristiques dépassent le minimum requis pour *DX*. En principe, **tous les ALLS de deuxième génération** (ceux dont la référence se termine par 2) **sont compatibles d'un point de vue logiciel**, mais certains manquent de puissance pour faire tourner le jeu correctement. C'est le cas par exemple du **ALLS X2** : compatible, mais trop faible pour une expérience agréable. Ces modèles peuvent être mis à niveau, mais l'opération devient vite complexe : *mieux vaut se procurer directement un modèle adapté.*

    Un ALLS ressemble beaucoup à un PC gaming moderne, avec deux particularités :

    - **Un port USB renfoncé** sur le dessus de la carte mère, réservé au **keychip**. Cette clé USB identifie le propriétaire de la borne sur le réseau officiel Sega et déchiffre les données de jeu.
    - **Deux cartes d'extension** (sur les modèles de deuxième génération), qui ajoutent trois ports série RS-232 et une prise jack 2,5mm. Avec le port COM de la carte mère, ces ports série servent à connecter le lecteur Aime, le VFD et les dalles tactiles des deux écrans. La prise jack est dédiée à l'une des deux prises casque.

    !!! tip "L'alimentation électrique du ALLS"
        L'alimentation du ALLS commute automatiquement sa tension : son connecteur C13 accepte indifféremment du 100V, 110V, 220V ou 240V. **Aucun transformateur externe n'est nécessaire.**

    !!! warning "Stockage"
        Un ALLS HX2 de *DX* officiel contient **deux disques** : un SSD de 120Go et un disque dur de 500Go (nommé "SUB STORAGE"). **Le jeu a besoin des deux**, le SSD seul ne suffit pas. Si votre ALLS n'a qu'un seul disque, vous devrez en installer un second.

        Pour cela, consultez le [Service Manual ALLS HX2](../resources/pdfs/alls-hx2-service-manual-full.pdf) : **brancher le disque ne suffit pas**, une étape logicielle détaillée dans le manuel est également nécessaire.

## Installation dans la borne

### Extraire le RingEdge 2 et libérer le compartiment du PC

Commencez par **débrancher tous les connecteurs du RingEdge 2** et sortez-le de la borne. Il ne servira plus : ne le conservez que si vous envisagez de reconvertir un jour la borne en FiNALE.

!!! tip "Sortez la planche entière"
    Selon le modèle de votre borne, le RingEdge 2 est probablement monté sur une planche. Si c'est le cas, retirez directement la planche plutôt que de vous battre avec les vis peu accessibles qui maintiennent le PC.

La plupart des composants voisins peuvent aussi être retirés. À droite du RingEdge 2, vous trouverez **trois PCB** :

- **L'IO3**, tout en haut, reconnaissable à la grosse nappe qui y est raccordée.
    * **À retirer**, avec son câble USB : elle est remplacée par l'IO4 sur *DX*.
- **L'adaptateur RS-232 vers USB**, en bas à gauche, relié au RingEdge 2 en USB. Deux connecteurs à deux fils sont normalement branchés sur sa rangée du bas.
    * **À conserver** : cette carte fait le lien entre les contrôleurs de LEDs et le PC. Profitez-en pour la sortir et la dépoussiérer, vous la réinstallerez plus tard.
- **Le contrôleur des dalles tactiles de FiNALE**, en bas à droite, relié au RingEdge 2 par un câble à trois fils terminé par un DB9.
    * **À retirer**, avec son câble et les deux câbles blancs raccordés en dessous : les dalles tactiles de *DX* sont radicalement différentes et n'utilisent plus ce composant.

Une fois ces trois PCB retirées, faites le ménage : **vous aurez besoin de tout l'espace disponible.** Si le RingEdge 2 était monté sur planche, vous devriez maintenant disposer d'une surface parfaitement plane. *S'il reposait sur deux lattes de bois, retirez-les également.* Dans la mesure du possible, fixez les câbles le long des parois latérales plutôt qu'au sol, afin de libérer un maximum de place.

**Le routeur et la caméra de FiNALE** peuvent aussi être retirés : le routeur servait notamment à relier la caméra au RingEdge 2, et cette caméra ne sert plus sur *DX*. Pensez également à retirer le câble audio jack 2,5mm qui reliait la caméra au RingEdge 2.

#### Les câbles vidéo

À l'origine, les bornes maimai pré-*DX* relient leurs écrans au RingEdge 2 par **deux câbles DVI vers VGA** (côté VGA sur l'écran). Un choix qui reste un mystère, puisque les deux écrans disposent d'une entrée DVI : beaucoup d'exploitants les ont donc remplacés par de simples câbles DVI vers DVI. Selon l'historique de votre borne, vous trouverez l'un ou l'autre :

- **Joueur 1** : retirez le câble, quel qu'il soit.
- **Joueur 2** : **conservez-le s'il s'agit d'un DVI vers DVI**, retirez-le s'il s'agit du DVI vers VGA d'origine.

!!! success "Ce qui doit rester"
    De la connectique d'origine du RingEdge 2, il ne devrait plus vous rester que :

    - les deux câbles audio jack 2,5mm des haut-parleurs joueur 1 et joueur 2
    - le câble Molex Mini-Fit Jr (alimentation)
    - éventuellement, le câble DVI vers DVI de l'écran joueur 2

### Installation du ALLS

Le ALLS est plus large que le RingEdge 2, mais l'espace que vous venez de libérer permet de l'installer confortablement, ainsi que les différentes PCB que nous y raccorderons par la suite. Sur les bornes *DX* officielles, le ALLS est d'ailleurs installé *à la verticale* : c'est une option si vous manquez de place. **L'essentiel est que le PC soit solidement fixé** et ne puisse pas bouger si la borne est déplacée.

Une fois le ALLS en place, vous pouvez déjà :

- **Fixer l'IO4**, idéalement à l'emplacement de l'ancienne IO3 pour profiter de la proximité des câbles d'alimentation d'origine. Si vous avez opté pour la [PCB de conversion]({{IO4_CONVERSION_PCB}}), prévoyez aussi sa place.
- **Réinstaller l'adaptateur RS-232 vers USB.**
- **Brancher le hub USB sur le port USB 2 du ALLS**, puis y raccorder l'adaptateur RS-232 vers USB.
- **Installer votre nouvelle alimentation à découpage 5V/12V** (voir [Alimentation](#alimentation)). Idéalement, placez-la côté joueur 1 avec les autres alimentations à découpage, même si cela demande des câbles plus longs.

Les autres câbles seront rebranchés au fil des étapes suivantes.

## Branchements

Voici la planche du [manuel officiel maimai DX](../resources/pdfs/maimai-dx-instruction-manual-full.pdf) (page 128) qui détaille toute la connectique d'un ALLS HX2. Voyons chaque connexion en détail.

!!! lightbox wide
    Vue arrière d'un ALLS HX2 et détail de sa connectique.

La plupart des appareils à connecter sont présentés plus en détail dans les étapes suivantes : en cas de doute sur un branchement, terminez d'abord le chapitre correspondant, puis revenez sur cette page. **D'après le manuel officiel de *DX*, l'ordre des ports USB a son importance** : respectez l'attribution ci-dessous.

### PSU interne

- **Connecteur C13** : Raccordement au secteur, accepte toute tension d'entrée de 100V à 240V.

### Keychip

- **Port USB** : Réservé au keychip. Ne peut **pas** servir de port USB classique.

### Carte mère

- **COM1 - Port DB9** : Lecteur Aime
- **LAN1 - Port RJ45** : Port réseau, à connecter au routeur de service. Le second port réseau est inutilisé.
- **Audio Jacks 2,5mm** :
    - **C/W** : [Prise casque](step-5-audio-headphones.md#les-prises-casques) Joueur 1
    - **FRONT** : [Haut-parleurs](step-5-audio-headphones.md#branchement-des-haut-parleurs) Joueur 1
    - **REAR** : [Haut-parleurs](step-5-audio-headphones.md#branchement-des-haut-parleurs) Joueur 2
- **USB** :
    - **USB 1** : SEGA IO4
    - **USB 2** : Hub USB, sur lequel sont branchés les deux caméras de QR codes et l'adaptateur `4x RS-232 vers USB`.
    - **USB 3** : Caméra des joueurs
    - **USB 4** : Port d'installation, pour y insérer une clé USB contenant les données de jeu à installer.

### Carte graphique

- **HDMI** : Raccordé à l'écran du joueur 1 via un câble HDMI - DVI-D.
- **DVI** : Raccordé à l'écran du joueur 2 via un câble DVI-D.
- **DisplayPort** : Inutilisé, duplique le signal vidéo du joueur 1.

### Cartes d'extension

- **COM2 - Port DB9** : VFD
- **COM3 - Port DB9** : Dalle tactile du joueur 1
- **COM4 - Port DB9** : Dalle tactile du joueur 2
- **SIDE** : [Prise casque](step-5-audio-headphones.md#les-prises-casques) Joueur 2

## Alimentation

La plupart des branchements sont assez intuitifs, mais **un connecteur indispensable du RingEdge 2 n'a pas d'équivalent sur le ALLS** : celui qui alimente les périphériques externes.

Sur le RingEdge 2, à côté du port du keychip, sort un **connecteur Molex Mini-Fit Jr 2x7 broches femelle**. Il relie plusieurs éléments de la borne, dont l'IO3, à l'alimentation interne du PC. Plutôt que de recâbler toute la zone, **le plus simple est de fabriquer un petit adaptateur** à partir d'un connecteur Molex Mini-Fit Jr identique, relié à une **alimentation à découpage fournissant du 5V et du 12V** (typiquement un modèle en boîtier métallique à bornier à vis, comme ceux de la marque Mean Well). Le connecteur d'origine fournit aussi du 3,3V, mais aucun matériel de la zone ne l'utilise.

!!! warning "Ne réutilisez pas les alimentations de la borne"
    Ce faisceau va notamment alimenter l'IO4. Réutiliser l'alimentation 5V existante n'aurait que peu de conséquences, mais **réutiliser l'alimentation 12V des LEDs serait une erreur** : pour éviter tout courant de retour, l'IO4 et les LEDs doivent chacune disposer de leur propre alimentation, l'IO4 n'étant pas conçue pour supporter une telle intensité.

!!! warning "Raccordez les masses"
    **Reliez le GND de votre nouvelle alimentation à celui d'une alimentation déjà en place dans la borne.** Une alimentation laissée flottante peut engendrer toutes sortes de problèmes inattendus.

Connecteur Molex Mini-Fit Jr 2x7 femelle, vue de face côté contacts : broches 1 à 7 en GND, 8 à 10 en +12V, 11 à 13 en +5V et 14 en +3,3V

Câblez le connecteur femelle en suivant le schéma ci-dessus. Il est représenté **de face, côté contacts** : ne le confondez pas avec le côté câbles.

- Broche 14 : **3,3V** (optionnel, inutilisé)
- Broches 13-11 : **5V**
- Broches 10-8 : **12V**
- Broches 7-1 : **GND**

Raccordez chaque fil au terminal correspondant de votre alimentation. Peu de courant traverse ce faisceau (moins de 3A au total, toutes tensions confondues), mais **assurez-vous d'utiliser une section adaptée** : le fil **20 AWG** (0,5mm²) de la [liste du matériel](equipment.md) est idéal. Du 22 AWG conviendrait aussi, puisque chaque tension est répartie sur plusieurs broches. Vérifiez simplement que vos cosses Mini-Fit Jr acceptent la section choisie (les modèles 18-24 AWG sont les plus courants).

Il ne vous reste plus qu'à brancher votre connecteur maison sur le câble d'origine.

!!! warning "L'alimentation doit être solidement fixée"
    La borne subit beaucoup de mouvements : **l'alimentation ne doit en aucun cas pouvoir bouger ou se renverser.** Vissez-la solidement au plancher du compartiment.

## En résumé
!!! tldr "Les grandes lignes"
    Pour le ALLS et l'alimentation :

    * Sortir le RingEdge 2 et libérer le compartiment (IO3, contrôleur tactile FiNALE, routeur, caméra)
    * Installer le ALLS HX2 à sa place et le fixer solidement
    * Raccorder les différents périphériques au ALLS (voir étapes suivantes)
    * Confectionner un câble adaptateur pour la connectique d'alimentation externe
    * Installer l'alimentation externe et le câble adaptateur dans la borne, raccorder le connecteur existant

---

Passons à l'[Étape 2 : Affichage et dalles tactiles HDX](step-2-touchscreen-display.md).

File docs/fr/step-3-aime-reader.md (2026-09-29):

---
title: "💳 3 - Lecteur Aime et VFD"
---

# 💳 Étape 3 : Le lecteur Aime et le VFD

**Les lecteurs Aime de FiNALE ne sont pas compatibles avec DX** : il faut installer un lecteur de nouvelle génération. Le VFD, lui, n'a aucune utilité réelle dans notre conversion, mais il reste nécessaire pour le logiciel. Bonne nouvelle : les deux sont très simples à installer.

## Explications techniques

??? note "Cliquez ici pour l'explication technique"
    FiNALE utilise deux lecteurs Aime d'ancienne génération, chaînés l'un à l'autre : celui du haut lit la carte du joueur de gauche, celui du bas celle du joueur de droite.

    Sur DX, il n'y a plus qu'**un seul lecteur**. Quand une carte est scannée, le profil apparaît sur les deux écrans : son propriétaire confirme la connexion sur son écran, puis le second joueur peut scanner sa propre carte. La technologie utilisée est complètement différente : **un lecteur Aime de FiNALE ne peut pas être réutilisé.**

    !!! info "aic_pico"
        Il est techniquement possible d'utiliser un [aic_pico]({{AIC_PICO_REPO}}), un projet open-source qui imite un véritable lecteur Aime de façon transparente pour le jeu. Il coûte beaucoup moins cher à produire, mais demanderait une bonne dose de bricolage pour être branché sur le port DB9 correspondant du ALLS.

    Les lecteurs Aime de dernière génération ne sont de toute façon pas si rares, et sont souvent vendus **en combo avec le VFD** dont nous avons également besoin. Cette génération est techniquement compatible avec le paiement électronique, mais même au Japon, cette fonction n'est presque jamais utilisée : les exploitants préfèrent installer leur propre terminal de paiement, plus flexible.

## La connectique

Le branchement au ALLS est extrêmement simple :

* Lecteur Aime : **COM1**
* VFD : **COM2**

Ces deux ports COM sont des ports DB9 physiques du ALLS. En revanche, votre combo Aime + VFD n'est probablement pas livré avec un câble DB9 prêt à brancher : **vous allez devoir sertir vos propres câbles**, du connecteur du lecteur Aime et du VFD jusqu'au DB9.

!!! lightbox
    Face avant d'un lecteur Aime issu d'une borne Star Horse 4
    Face arrière d'un lecteur Aime issu d'une borne Star Horse 4

### Préparer le câble DB9

Prenez votre câble DB9 femelle-femelle et **coupez-le en deux** pour en exposer les fils. Deux options :

* **Couper au milieu d'un câble long**, assez long une fois coupé pour aller proprement du ALLS jusqu'au centre de la borne, où sera installé le combo.
* **Couper à une vingtaine de centimètres** d'un connecteur, puis rejoindre le ALLS avec un simple câble DB9 mâle-femelle de longueur adaptée.

*La seconde option est recommandée* : pas de longueur de câble encombrante pendant le sertissage, une installation plus simple, et un combo plus facile à débrancher pour la maintenance.

!!! lightbox
    Câble DB9 femelle coupé, gaine retirée pour exposer les fils internes

### Repérer les bons fils

Les couleurs des fils varient d'un câble DB9 à l'autre : ne vous fiez donc pas à celles des photos. **Le plus sûr est d'utiliser un multimètre en mode continuité** :

* Placez une pointe du multimètre dans le trou de la fiche DB9 femelle correspondant à la broche voulue (voir les schémas ci-dessous).
    * Si la pointe est trop large, raccordez-y un fil Dupont mâle.
* Avec l'autre pointe, touchez les fils un par un jusqu'au bip sonore. **Le fil qui sonne correspond à votre broche** : repérez-le.
* Une fois tous les fils utiles repérés (*3 pour le lecteur Aime, 5 pour le VFD*), coupez les autres.

### Câble du lecteur Aime

Le lecteur Aime est le plus simple des deux : **seules 5 de ses 8 broches sont utilisées**. Les 5 fils sont tous sertis avec des broches **JST-PH femelle** et insérés dans un connecteur **JST-PH 8 broches** :

1. **3 fils de signal** : ceux que vous avez repérés sur le câble DB9.
2. **2 fils d'alimentation "volants"** : un fil **rouge** sur la broche **5V** et un fil **noir** sur la broche **GND** juste à côté. Ils ne sont pas reliés au DB9 : laissez leur autre extrémité libre pour l'instant, elle sera réunie avec celle du VFD sur un seul connecteur (voir [Regrouper les fils d'alimentation](#regrouper-les-fils-dalimentation)).

Correspondance des broches entre le connecteur JST-PH du lecteur Aime et le port DB9 femelle

!!! warning "Sertissez les deux GND"
    Deux des broches à sertir sont des GND (masse commune). Un seul suffirait en théorie, mais **câblez bien les deux** : l'un accompagne le 5V pour alimenter le lecteur, l'autre est relié au DB9 comme le veut la norme RS-232.

### Câble du VFD

Le VFD a un connecteur 7 broches, et **toutes doivent être serties**.

La méthode est presque identique à celle du lecteur Aime, à deux différences près :

* Le connecteur du VFD est un JST-**X**H (et non JST-PH) : sertissez les fils avec des broches **JST-XH femelle**.
* **5 fils de signal** au lieu de 3 : il faut aussi raccorder au port série les fils des signaux `CTS` et `RTS`.

Comme pour le lecteur Aime, ajoutez **2 fils d'alimentation volants**, rouge sur le **5V** et noir sur le **GND**, en laissant leur autre extrémité libre.

Correspondance des broches entre le connecteur JST-XH du VFD et le port DB9 femelle

### Regrouper les fils d'alimentation

Le lecteur Aime et le VFD ont maintenant chacun une paire de fils volants 5V/GND. **Réunissez-les en Y sur un seul connecteur JST-SM 2 broches** : les deux fils rouges (5V) ensemble sur une broche, les deux fils noirs (GND) ensemble sur l'autre. Placé à côté de vos deux câbles DB9, ce connecteur rend le combo plus simple à installer et à débrancher pour la maintenance.

Félicitations, vos câbles pour le ALLS sont prêts !

!!! lightbox
    Les deux câbles DB9 femelle finalisés, avec leurs connecteurs JST pour le lecteur Aime et le VFD

### Sécuriser les câbles

Branchez les deux câbles sur les connecteurs correspondants, puis **fixez-les à l'arrière du combo** pour qu'ils ne subissent aucune tension. Même bien sertis, ces connecteurs restent fragiles.

!!! lightbox
    Les câbles branchés puis fixés à l'arrière du combo lecteur Aime + VFD pour éviter toute tension sur les connecteurs

## Installation sur la borne

Utilisez [le modèle 3D conçu par SpiralGlide](spiralglide-resources.md#support-du-lecteur-aime), qui se fixe sur la borne grâce aux vis existantes de la vitre en acrylique. Conçu pour le lecteur Aime de Star Horse 4, il s'intègre **sans modification destructive**, en profitant des trous déjà prévus pour les lecteurs Aime. Il comprend aussi un emplacement pour les boutons 1P SELECT et 2P SELECT, que vous installerez à [l'étape suivante](step-4-io-board.md).

!!! lightbox
    Le support du lecteur Aime imprimé et monté dans la façade de la tour centrale, lecteur Aime en place. Photo par SpiralGlide

## Dernière étape

Une fois le combo installé en façade, il ne reste qu'à brancher les deux câbles aux ports DB9 du ALLS. Pour rappel : **Aime sur COM1**, **VFD sur COM2**.

N'oubliez pas ensuite de **raccorder le 5V et le GND** des deux connecteurs à l'alimentation installée à [l'étape 1](step-1-alls-and-psu.md).

**Vérifiez que tout fonctionne** avant de passer à la suite.

!!! lightbox
    Vue arrière d'un ALLS HX2 : des flèches rouges désignent le port DB9 du VFD, sur la carte d'extension en haut, et celui du lecteur Aime, en bas à droite de la carte mère

## En résumé
!!! tldr "Les grandes lignes"
    Pour le lecteur Aime et le VFD :

    * Fabriquer un câble DB9 femelle pour le lecteur Aime.
    * Fabriquer un câble DB9 femelle pour le VFD.
    * Sécuriser les câbles pour qu'ils ne bougent pas.
    * Installer le combo en façade sur la borne.
    * Brancher les deux connecteurs sur le ALLS.
    * Raccorder l'alimentation.

---

Passons à l'[Étape 4 : La Carte I/O et les Boutons](step-4-io-board.md).

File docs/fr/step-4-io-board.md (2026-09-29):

---
title: "🕹️ 4 - Carte I/O et boutons"
---

# 🕹️ Étape 4 : La Carte I/O et les Boutons

Pour faire tourner *DX*, **l'IO3 de FiNALE doit être remplacée par une IO4**, plus récente. Côté boutons, les deux modèles diffèrent peu, mais le câblage doit tout de même être adapté.

## Explications techniques

??? note "Cliquez ici pour l'explication technique"
    Le passage à l'IO4 entraîne deux modifications majeures du câblage de la borne DX par rapport à FiNALE :

    * **Le harnais de câbles a été modifié** : il intègre les deux boutons 1P SELECT et 2P SELECT, et le Coin Locker passe de la broche 51 à la broche 53.
    * **L'IO4 gère désormais l'éclairage** de plusieurs parties de la borne.

    Le premier point est simple, le second bien plus contraignant : **6 signaux LEDs passent désormais par l'IO4**, là où les contrôleurs de LEDs géraient seuls l'éclairage sur FiNALE.

    Autre changement : **l'IO4 communique avec le PC en USB**, et non plus en JVS comme sur RingEdge 2. *Certaines variantes d'IO4 gèrent aussi le JVS, mais peu importe ici : la connexion se fait forcément en USB.*

    !!! lightbox
        Une carte IO4 Sega (837-15257)

    *(Note : le détail complet du câblage de l'IO4 se trouve à la page 194 du [manuel](../resources/pdfs/maimai-dx-instruction-manual-full.pdf), ou directement [ici](../resources/images/wiring-diagrams/maimai-dx-wiring-diagram-2-of-4.jpg), de **[E-2]** à **[F-6]**.)*

    !!! info "Alimentation de l'IO4"
        La connexion USB ne suffit pas à alimenter l'IO4. Elle a aussi besoin :

        * d'une source **5V**, via le connecteur **CN7**, **CN8** ou les deux,
        * d'une source **12V**, via le connecteur **CN1**, **CN2** ou les deux.

        Bonne nouvelle : **les connecteurs d'alimentation de l'IO3 se branchent tels quels sur l'IO4**. Ils sont déjà raccordés à l'alimentation externe installée à [l'étape 1](step-1-alls-and-psu.md).

## Installation de l'IO4

Commencez par **brancher sur l'IO4, fixée à l'[étape 1](step-1-alls-and-psu.md), les connecteurs d'alimentation d'origine de l'IO3** : **CN1**/**CN2** pour le 12V, **CN7**/**CN8** pour le 5V.

Pour installer l'IO4 dans une borne FiNALE, deux options :

* **Modifier le harnais à la main.**
* **Utiliser la PCB de conversion.**

**La seconde option est de loin la plus simple** :

* **Aucune modification du harnais** : il se branche tel quel sur la PCB, qui s'occupe du reste.
* **Des connecteurs prêts à l'emploi** pour les nouveaux signaux absents de la borne, comme les boutons 1P SELECT et 2P SELECT.
* **Gratuite** : les fichiers sont [sur GitHub]({{IO4_CONVERSION_PCB}}), avec un petit guide pour la faire fabriquer vous-même.

Dans les deux cas, *les LEDs seront traitées en détail à [l'étape 6](step-6-lighting.md)* : ce chapitre se concentre sur le harnais.

??? example "La méthode facile - La PCB de conversion"

    ### La PCB de conversion

    La PCB de conversion simplifie fortement les choses, **en particulier pour les LEDs** à [l'étape 6](step-6-lighting.md). Elle porte deux connecteurs au même format que le CN3 : **l'un se branche sur l'IO4, l'autre accueille le harnais de la borne.**

    !!! lightbox
        La carte IO4 câblée et raccordée par nappes à la PCB de conversion

    #### Installer la PCB

    La PCB s'installe juste à côté de l'IO4. **Quatre branchements suffisent :**

    1. **J1** de la PCB → **CN3** de l'IO4.
    2. **J2** de la PCB → **CN9** de l'IO4.
    3. **12V** sur le connecteur **J22** de la PCB (voir ci-dessous).
    4. **Harnais de la borne** → **J3** de la PCB.

    !!! tip "Les nappes à utiliser"
        Le connecteur d'origine de l'IO4 est un JST-RA, mais **n'importe quel connecteur au pas de 2,54 mm fait l'affaire**. Le plus simple : des **nappes IDC avec un connecteur femelle à chaque bout**. Il vous en faut deux : une **2x30** pour le CN3 et une **2x10** pour le CN9.

    #### Alimenter la PCB

    La PCB a besoin d'un **12V propre sur le connecteur J22** : c'est lui qui allume les LEDs désormais gérées par l'IO4. **L'idéal est d'utiliser l'alimentation LEDs de la borne.**

    Un courant important va passer par ce circuit : **utilisez une section de fil suffisante**, idéalement **1,5 mm²**. *Mieux vaut trop que pas assez.*

    !!! warning "Polarité"
        **Vérifiez deux fois votre branchement.** En cas d'inversion du 12V et du GND, la PCB se protège : votre borne ne risque rien, *mais le fusible de la PCB grille* et devra être remplacé pour qu'elle fonctionne de nouveau.

    !!! danger "N'utilisez pas l'alimentation de l'IO4"
        L'IO4 et les LEDs doivent **chacune avoir leur propre alimentation**. Ne réutilisez donc pas pour la PCB l'alimentation à découpage installée à [l'étape 1](step-1-alls-and-psu.md), pour deux raisons :

        * **Puissance insuffisante** : sauf modèle haut de gamme, une petite alimentation à découpage ne tiendra pas la charge de toutes les LEDs. Elle chauffera plus que de raison, ce qui est dangereux. L'alimentation de la borne, elle, est justement prévue pour ça.
        * **Courant de retour** : le rail 12V de l'IO4 n'est pas conçu pour une telle charge. L'utiliser pour la PCB finirait par endommager l'IO4.

    #### Régler les jumpers

    La PCB porte deux emplacements de jumper :

    * **J34 - Pontage EXV** : relie le signal `EXV` au 5V. *Normalement, le harnais de la borne s'en charge déjà*, vous pouvez l'installer si ce n'est pas le cas.
    * **J35 - Type de harnais** : indique à la PCB si le harnais branché vient de FiNALE ou de DX.
        * **Harnais de FiNALE non modifié** (le cas de ce guide) : jumper sur les **deux broches de gauche**.
        * **Harnais déjà modifié à la main**, ou vraie borne DX : jumper sur les **deux broches de droite**.

    !!! lightbox
        Rendu de la PCB de conversion maiConvert-IO4, avec les emplacements de jumper encadrés en rouge : J34 (pontage EXV vers 5V) en haut, près des connecteurs J1 et J3, et J35 (mode de compatibilité du harnais, FiNALE à gauche, DX à droite) en bas à gauche

    #### Brancher les boutons Select

    La PCB fournit **deux connecteurs JST-XH 2 broches mâles** pour les boutons 1P SELECT et 2P SELECT : sertissez un **JST-XH 2 broches femelle** côté bouton, branchez, et le tour est joué. [Le support du lecteur Aime de SpiralGlide](spiralglide-resources.md#support-du-lecteur-aime), installé à l'[étape 3](step-3-aime-reader.md), leur réserve un emplacement.

    *Aucun autre bouton n'est à brancher sur la PCB* : **tous les autres passent par le harnais de la borne.**

??? example "Modification manuelle du harnais"

    ### Modification manuelle du harnais

    Pour modifier le harnais à la main, quatre points sont à traiter.

    #### Le bloqueur de pièces (Coin Locker)

    Sa broche a changé : **câblé sur la broche 51 sur *FiNALE*, il passe à la broche 53**.

    1. Sur le gros faisceau anciennement branché au connecteur **CN3** de l'IO3, repérez la broche **51**.
    2. Déplacez ce fil vers la broche **53**.

    #### L'ajout des boutons "Select"

    *DX* ajoute **deux boutons pour trier les chansons**, à câbler vous-même :

    1. **Installez les boutons** sur le panneau central. [Le support du lecteur Aime de SpiralGlide](spiralglide-resources.md#support-du-lecteur-aime), installé à l'[étape 3](step-3-aime-reader.md), leur réserve justement un emplacement.
    2. **Reliez une broche de chaque bouton à la masse (GND)** du faisceau du connecteur **CN3** (broches 9 à 16).
    3. **Reliez l'autre broche** à la broche correspondante du connecteur **CN3** :
        * "1P SELECT BUTTON" : broche **27**
        * "2P SELECT BUTTON" : broche **26**

    #### Préparer les LEDs de l'enseigne

    L'éclairage sera traité à [l'étape 6](step-6-lighting.md), mais **puisque vous travaillez déjà sur le CN3, préparez dès maintenant les deux signaux rouges de l'enseigne** :

    1. Sertissez un fil sur les broches **51** (`BILLBOARD LED L RED`) et **52** (`BILLBOARD LED R RED`) du **CN3**. *La 51 est justement celle libérée par le Coin Locker.*
    2. Terminez-les par un **JST-SM 2 broches femelle**, qui sera raccordé à la nappe de l'enseigne à l'étape 6. *Ce côté étant sous tension, le connecteur femelle évite tout contact accidentel.*

    ??? info "Pour référence : toutes les LEDs gérées par l'IO4"
        * "BILLBOARD LED L RED" : connecteur **CN3** - broche **51**
        * "BILLBOARD LED R RED" : connecteur **CN3** - broche **52**
        * "BILLBOARD LED L GREEN" : connecteur **CN9** - broche **5**
        * "BILLBOARD LED R GREEN" : connecteur **CN9** - broche **6**
        * "BILLBOARD LED L BLUE" : connecteur **CN9** - broche **9**
        * "BILLBOARD LED R BLUE" : connecteur **CN9** - broche **10**
        * "CAMERA LED WARM" : connecteur **CN9** - broche **7**
        * "CAMERA LED RED" : connecteur **CN9** - broche **8**
        * "1P CODE READER LED" : connecteur **CN3** - broche **55**
        * "2P CODE READER LED" : connecteur **CN3** - broche **56**

    #### Vérifier le pontage EXV

    Normalement déjà fait, mais vérifiez que les broches **1-2** du **CN3** sont reliées aux broches **3-4**. Ce pontage relie le signal `EXV` au 5V : **sans lui, le jeu ne détecte pas l'IO4.**

## Branchement USB

Il ne reste qu'à **brancher l'IO4 sur le port USB 1 du ALLS**, comme indiqué à [l'étape 1](step-1-alls-and-psu.md).

!!! lightbox
    Vue arrière d'un ALLS HX2 : des flèches rouges désignent le port USB 1, en bas à droite du bloc de ports USB, et son repère sur l'étiquette du boîtier

## En résumé
!!! tldr "Les grandes lignes"
    Pour la carte I/O :

    * Brancher les connecteurs d'alimentation d'origine sur l'IO4.
    * Installer les boutons 1P SELECT et 2P SELECT sur le panneau central.

    Si vous choisissez la PCB de conversion :

    * Relier la PCB aux connecteurs CN3 et CN9 de l'IO4 avec des nappes IDC, puis y brancher le harnais de la borne.
    * Alimenter la PCB en 12V depuis l'alimentation LEDs de la borne, en 1,5 mm².
    * Placer le jumper J35 sur la position FiNALE (deux broches de gauche).
    * Brancher les boutons Select sur leurs connecteurs JST-XH.

    Si vous choisissez le câblage manuel :

    * Déplacer le fil du Coin Locker de la broche 51 à la broche 53 du CN3.
    * Câbler les boutons Select sur les broches 26 et 27 du CN3.
    * Préparer un connecteur JST-SM 2 broches femelle pour les LEDs rouges de l'enseigne.
    * Vérifier le pontage EXV.

    Finalement :

    * Brancher l'IO4 sur le port USB 1 du ALLS.

---

Passons à l'[Étape 5 : Prises casques et Système Son](step-5-audio-headphones.md).

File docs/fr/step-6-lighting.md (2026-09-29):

---
title: "💡 6 - Lumières"
---

# 💡 Étape 6 : Lumières

L'éclairage est techniquement *optionnel* : il n'a aucun impact sur la jouabilité. Mais l'opération n'est pas si complexe et l'éclairage fait beaucoup pour le charme de DX. **Il est recommandé de ne pas faire l'impasse sur cette étape.**

## Explications techniques

??? note "Cliquez ici pour l'explication technique"
    ### Fonctionnement des LEDs sur une maimai DX

    Sur une véritable borne *DX*, l'éclairage est piloté par trois contrôleurs :

    * L'**IO4** gère l'**enseigne lumineuse** (désignée `BILLBOARD LED` / `ROOF LED` sur les schémas Sega). Voir l'[Étape 4](step-4-io-board.md).
    * Deux cartes de contrôle identiques (réf. `837-15070-04`) :
        * Côté P1 : les huit boutons, l'éclairage du fond et l'éclairage du côté gauche.
        * Côté P2 : les huit boutons, l'éclairage du fond et l'éclairage du côté droit.

    Chaîne de contrôle de l'éclairage : les cartes LED P1 et P2 (réf. ) rejoignent en RS-232 l'adaptateur RS-232 vers USB (réf. ), lui-même branché au hub USB partagé avec les caméras QR-Code de P1 et P2

    Les deux cartes de contrôle sont reliées en RS-232 à un unique adaptateur RS-232 vers USB, lui-même branché sur le même hub USB que les lecteurs de QR-Code (voir [Étape 7](step-7-cameras.md)).

    !!! info "Configuration logicielle des ports COM"
        Les contrôleurs de LEDs apparaissent sur les ports COM virtuels suivants du ALLS :

        * **COM21** pour les LEDs du P1.
        * **COM23** pour les LEDs du P2.

    ### Fonctionnement des LEDs sur une maimai FiNALE

    Le fonctionnement est un peu plus simple sur FiNALE :

    * Contrairement à DX, aucune LED ne passe par l'IO3.
    * Deux cartes de contrôle identiques gèrent les LEDs (réf. `837-15070-02-91`) :
        * Côté P1 : les huit boutons, l'éclairage du fond, les woofers, et l'enseigne lumineuse côté P1 et au centre.
        * Côté P2 : les huit boutons, l'éclairage du fond, les woofers, et l'enseigne lumineuse côté P2.

    Chaîne de contrôle de l'éclairage sur FiNALE : les cartes LED P1 et P2 (réf. ) rejoignent en RS-232 le même adaptateur RS-232 vers USB que sur DX (réf. ), branché directement sur un port USB du RingEdge 2, sans hub USB

    Comme sur DX, ces deux cartes sont reliées en RS-232 à un adaptateur RS-232 vers USB. Par chance, **c'est exactement le même sur FiNALE et sur DX (réf. `837-15067-02`)**. Seule différence : sur FiNALE, il se branche directement sur un port USB du RingEdge 2, sans hub.

    ### Ce que ça implique pour une conversion

    * **L'adaptateur RS-232 vers USB se branche sur le hub USB 4 ports** installé à l'[étape 1](step-1-alls-and-psu.md). N'importe quel port du hub convient.
    * **L'enseigne lumineuse doit être recâblée vers l'IO4** : sur DX, les contrôleurs de LEDs ne reçoivent plus d'information pour l'éclairer.
    * Surtout, **les contrôleurs de LEDs de FiNALE et de DX n'ont pas la même référence**. Branché sur un ALLS avec DX, un contrôleur FiNALE provoque **une erreur non bloquante au démarrage** : il annonce `837-15070-02-91` alors que le jeu attend `837-15070-04`. Fait amusant : dans cet état, le jeu envoie tout de même l'éclairage des boutons, mais pas celui du fond.

    Heureusement, ces trois problèmes ont une solution.

## Pour les boutons de jeu et le fond des deux joueurs

Pour les contrôleurs de LEDs, **DX attend l'identifiant `837-15070-04`**, mais ceux de FiNALE renvoient `837-15070-02-91`, ce qui met le jeu en erreur. C'est le seul problème : pour le reste, le contrôleur de FiNALE est 100 % compatible avec les instructions envoyées par DX.

Il faut donc que les deux contrôleurs renvoient l'identifiant attendu. Un correctif logiciel serait simple, mais nous voulons laisser le logiciel du jeu intact : **la solution sera donc matérielle.**

**La solution :** un simple Raspberry Pi Pico, avec un firmware dédié, placé entre le contrôleur de LEDs et l'adaptateur RS-232 vers USB. Il **modifie uniquement le message contenant l'identifiant**, et transmet tous les autres à l'identique, dans les deux sens.

Le firmware existe déjà : il s'agit de [mailight_pico]({{MAILIGHT_PICO_REPO}}), un portage de *[mailight_rs]({{MAILIGHT_RS_REPO}})* par [4ndr3w]({{GITHUB_4NDR3W}}) sur GitHub. Il ne reste plus qu'à fabriquer le proxy.

### Fabriquer un proxy

!!! info "En double exemplaire"
    Il vous faut **deux proxys**, un par contrôleur de LEDs. Réalisez donc chaque opération en double.

**1. Installer le firmware.** Flashez mailight_pico sur le Raspberry Pi Pico. Si vous ne l'avez jamais fait, c'est extrêmement simple : [toutes les instructions sont sur la page du projet]({{MAILIGHT_PICO_FIRMWARE_INSTRUCTIONS}}).

**2. Assembler le Pico sur le `Pico-2CH-RS232`.** Attention au sens : les inscriptions sous le `Pico-2CH-RS232` indiquent où doit se trouver le port USB du Pico.

!!! lightbox
    Le module , image tirée de la [page wiki officielle de Waveshare]({{WAVESHARE_PICO_2CH_RS232_WIKI}})

!!! warning "Attention au sens"
    Vérifiez que votre montage correspond bien à l'image. Si le port USB de votre Pico se retrouve par exemple entre les deux PCB plutôt qu'à l'extérieur, ses broches sont soudées dans le mauvais sens. **N'essayez pas de l'allumer**, vous endommageriez le `Pico-2CH-RS232`. Ressoudez les broches dans le bon sens, ou procurez-vous un Pico correctement assemblé.

**3. Préparer la connectique.** Le proxy s'insère entre le contrôleur de LEDs et l'adaptateur RS-232 vers USB. Le connecteur n'est pas le même selon le côté :

* Côté P1 : JST-XH **7** broches, mâle **et** femelle
* Côté P2 : JST-XH **9** broches, mâle **et** femelle

!!! lightbox
    Connecteur JST-XH côté P1
    Connecteur JST-XH côté P2

Pour vous simplifier la vie, reprenez les couleurs de la borne : **fil blanc sur la broche 4, fil rouge sur la broche 5**. Câblez les deux connecteurs de sorte que les couleurs soient alignées quand on enfiche le mâle dans le femelle.

Ces images proviennent du schéma de câblage, mais les connecteurs réels de la borne n'ont pas de fil `SHIELD` : la masse commune devra donc être raccordée ailleurs sur le `Pico-2CH-RS232`.

!!! lightbox
    Vue du dessus du module
    Le connecteur d'origine du contrôleur de LEDs dans la borne enfiché dans le connecteur confectionné à la main

**4. Câbler les borniers.** Le connecteur **JST-XH femelle va sur le bornier Channel0** (côté adaptateur RS-232 vers USB), le connecteur **JST-XH mâle sur le bornier Channel1** (côté contrôleur de LEDs) :

* Channel0
    * TX0 : rouge
    * RX0 : blanc
    * GND : un fil noir, dont l'autre extrémité va sur le GND de l'alimentation installée à l'[étape 1](step-1-alls-and-psu.md).
* Channel1
    * TX1 : blanc
    * RX1 : rouge

**5. Alimenter le proxy.** Le plus simple est de brancher un câble micro-USB sur le Pico et d'en couper l'autre extrémité : **fil rouge sur le 5V, fil noir sur le GND** de l'alimentation installée à l'[étape 1](step-1-alls-and-psu.md).

Votre proxy est terminé !

!!! lightbox
    Le proxy terminé : le Raspberry Pi Pico assemblé sur le , avec le connecteur JST-XH femelle (Channel0, côté adaptateur RS-232 vers USB) et le connecteur JST-XH mâle (Channel1, côté contrôleur de LEDs) câblés en fil rouge et blanc, et le câble micro-USB d'alimentation

### Installer le proxy

Pour chaque contrôleur de LEDs :

* Débranchez le connecteur du contrôleur de LEDs et branchez-le sur le **connecteur mâle** du proxy.
* Branchez le **connecteur femelle** du proxy à sa place, sur l'adaptateur RS-232 vers USB.
* Alimentez le proxy.

Il ne reste plus qu'à brancher l'adaptateur RS-232 vers USB sur le ALLS via le hub USB. **Le jeu devrait reconnaître les contrôleurs de LEDs nativement**, sans aucune modification logicielle.

!!! warning "Branchez l'adaptateur correctement"
    Comme indiqué à l'[étape 1](step-1-alls-and-psu.md), **le hub USB doit être branché sur le port USB n°2** du ALLS, et l'adaptateur RS-232 vers USB sur ce hub. maimai DX est très exigeant sur les ports USB : en cas de mauvais branchement, les LEDs ne s'allumeront pas.

## Pour l'enseigne lumineuse et les woofers

??? note "Cliquez ici pour l'explication technique"
    Sur FiNALE, les woofers et l'enseigne lumineuse partagent le même circuit : allumer l'un allume forcément l'autre. Les woofers ne sont plus éclairés sur DX, mais ce n'est pas un problème puisque l'enseigne, elle, l'est toujours.

    En revanche, sur DX, **c'est l'IO4 qui gère ces LEDs** : le jeu n'envoie tout simplement plus cette information au contrôleur de LEDs. La raison de ce changement reste mystérieuse, mais il faut donc recâbler une partie des branchements.

    Par chance, le schéma de câblage de FiNALE référence un connecteur très pratique, qui permet de distribuer le signal côté joueur 1 et joueur 2 sans recâbler toute la borne :

    !!! lightbox
        Schéma de câblage FiNALE, connecteur AB côté P1 : le harnais MAI-60109 alimente les cartes CENTER LED, ROOF LED (L), ROOF LED (R) et WOOFER LED
        Schéma de câblage FiNALE, connecteur BB côté P2 : le harnais MAI-60109 alimente les cartes WOOFER LED, ROOF LED (L) et ROOF LED (R), le connecteur SM5P n'étant pas utilisé
        Connecteur JST-SM 8 broches qui connecte les woofers et l'enseigne lumineuse (en noir)

    Le schéma du P1 comporte un élément `CENTER LED`, absent côté P2 : c'est l'éclairage du centre de l'enseigne. Sur DX, cette distinction n'existe pas : même si les signaux sont séparés, l'enseigne est toujours de la même couleur des deux côtés. Le plus simple est donc de **relier les broches `A2`, `A5` et `A8` du connecteur P1 aux broches `C3`, `C5` et `C8`**, pour que le centre prenne la même couleur que le côté joueur 1.

Deux méthodes sont possibles :

* **Avec la [PCB de conversion]({{IO4_CONVERSION_PCB}})**, si vous l'avez installée à l'[étape 4](step-4-io-board.md) : il suffit de brancher les LEDs sur les bons ports de la PCB.
* **Sans elle** : fabriquez votre propre nappe de câbles, compatible avec l'IO4, pour y raccorder les LEDs.

??? example "La méthode facile - La PCB de conversion"
    Branchez simplement le connecteur de sortie du contrôleur de LEDs sur la PCB de conversion. C'est tout : *le 12V est déjà raccordé depuis l'[étape 4](step-4-io-board.md).*

    !!! tip "Rappel : deux alimentations séparées"
        La PCB est alimentée par **l'alimentation LEDs de la borne**, jamais par le 12V de l'IO4. Les deux circuits partagent une masse commune, mais restent séparés.

    Il vous faudra une rallonge pour atteindre le câble existant : **2 mètres côté joueur 2, 3 mètres côté joueur 1**. Elle se sertit facilement : un connecteur `JST-XH 8 positions femelle` d'un côté, un `JST-SM 8 positions femelle` de l'autre.

    !!! lightbox
        PCB de conversion [maiConvert-IO4]({{IO4_CONVERSION_PCB}}) : repérage du connecteur J22 ( , attention à la polarité) et des connecteurs J23/J24 ( / ) où raccorder la nappe de LEDs de l'enseigne lumineuse
        Nappes de câbles en JST-SM 8 positions mâle, gérant les LEDs de l'enseigne lumineuse et des woofers, débranché du connecteur raccordé au contrôleur de LED sur une borne FiNALE

    *Si vous comptez installer les caméras à l'étape suivante*, la PCB de conversion vous simplifiera aussi la vie : elle propose déjà des connecteurs prêts à l'emploi pour leurs LEDs.

??? example "La confection manuelle d'une nappe de câbles"
    La nappe se branche sur l'IO4 via un connecteur JST-RA 20 broches (CN9), et se termine par deux connecteurs JST-SM 8 broches, pour les côtés gauche et droit. Si vous avez suivi les suggestions de l'[étape 4](step-4-io-board.md), vous avez déjà un connecteur JST-SM 2 broches femelle câblé sur le CN3 de l'IO4 pour les signaux `BILLBOARD LED L RED` et `BILLBOARD LED R RED`.

    !!! lightbox
        Repérage visuel des broches LED sur l'IO4 : le connecteur CN9 (JST-RA 20 broches) porte BILLBOARD LED L/R GREEN, CAMERA LED WARM/RED et BILLBOARD LED L/R BLUE, tandis que BILLBOARD LED L/R RED se trouve sur le connecteur CN3
        Schéma de câblage officiel de l'IO4 centré sur les broches LED : connecteur CN9 (RA20P) pour BILLBOARD LED L/R GREEN, CAMERA LED WARM/RED et BILLBOARD LED L/R BLUE, et connecteur CN3 (RA60P) broches 51-52 pour BILLBOARD LED L/R RED

    Réalisez la nappe d'après le schéma ci-dessous, avec une longueur suffisante pour une installation propre : **3 mètres côté joueur 1, 2 mètres côté joueur 2**. Pour le 12V, **n'utilisez pas la broche 12V du CN9** : raccordez-vous directement à l'alimentation 12V des LEDs de la borne, pour ne pas charger inutilement la carte I/O.

    ![Nappe de câbles pour l'éclairage de l'enseigne lumineuse : depuis l'IO4 (CN9 broches 5, 6, 9 et 10, et CN3 broches 51-52 déjà câblées à l'étape 4) et l'alimentation 12V interne, fabrication de deux connecteurs JST-SM 8 broches - côté P1 (3 mètres, avec pontage des broches 1-4 vers 5-8 pour alimenter aussi CENTER LED) et côté P2 (2 mètres, broches 5-8 non utilisées) - qui se branchent ensuite sur les connecteurs d'origine AB et BB](../resources/images/step-6-lighting/led-topper-harness.svg)

    Une fois la nappe terminée, branchez-la à l'IO4, raccordez le 12V, puis branchez les deux connecteurs JST-SM 8 broches d'origine sur votre nouveau câble. **Testez la continuité de tous vos câbles avant l'installation**, pour écarter toute broche mal sertie.

    !!! lightbox
        Nappes de câbles en JST-SM 8 positions mâle, gérant les LEDs de l'enseigne lumineuse et des woofers, débranché du connecteur raccordé au contrôleur de LED sur une borne FiNALE

    !!! tip "Les LEDs des caméras"
        Si vous comptez installer les caméras optionnelles, sertissez dès maintenant quelques connecteurs supplémentaires :

        - JST-SM 2 broches femelle sur les broches 7 et 8 du CN9, pour les signaux `CAMERA LED WARM` et `CAMERA LED RED` respectivement.
        - JST-SM 2 broches femelle sur les broches 55 et 56 du CN3, pour les signaux `1P CODE READER LED` et `2P CODE READER LED` dans cet ordre.

## En résumé
!!! tldr "Les grandes lignes"
    Pour les LEDs des boutons et le fond de la borne :

    * Fabriquer deux proxys, chacun à base d'un Raspberry Pi Pico et d'un `Pico-2CH-RS232`.
    * Installer chaque proxy entre son contrôleur de LEDs et l'adaptateur RS-232 vers USB.
    * Brancher l'adaptateur sur le hub USB, et le hub sur le port USB n°2 du ALLS.

    Pour l'enseigne lumineuse et les woofers :

    * Soit : raccorder les connecteurs existants de la borne à la [PCB de conversion]({{IO4_CONVERSION_PCB}}).
    * Soit : confectionner et installer une nappe de câbles partant de l'IO4 et se branchant sur les connecteurs existants de la borne.

---

Passons à l'[Étape 7 : Caméras (Optionnel)](step-7-cameras.md).

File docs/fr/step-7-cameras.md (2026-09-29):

---
title: "📷 7 - Caméras (Optionnel)"
---

# 📷 Étape 7 : Caméras (Optionnel)

À ce stade, une seule fonctionnalité sépare encore votre conversion d'une véritable *DX* : **les caméras**. Le jeu s'en sert très peu, et elles sont largement considérées comme optionnelles. Mais si vous voulez vous rapprocher au maximum d'une vraie *DX*, elles sont heureusement assez simples à installer.

## Explications techniques

??? note "Cliquez ici pour l'explication technique"
    Une véritable *DX* compte **trois caméras** : une pointée vers les joueurs, et deux qui servent de lecteurs de QR-Code pour les *DX Pass*.

    - **La caméra des joueurs** : une simple caméra USB UVC, en 1280x960 avec un HFOV de 95°. [[référence]]({{SHIKINO_PLAYER_CAMERA_REFERENCE}})
    - **Les caméras des lecteurs de QR-Code** : deux caméras USB UVC, en 640x480 avec un FOV de 50°.

    !!! info "Les DX Pass"
        Les DX Pass sont des cartes physiques que les joueurs font imprimer sur la borne "Sega CardMaker". Cette borne est rare hors du Japon, et plus encore en état d'imprimer. De plus, les DX Pass sont aujourd'hui associés automatiquement au compte du joueur : la carte physique n'est plus nécessaire. **Les lecteurs de QR-Code sont donc largement optionnels**, voire inutiles.

        Certains événements en jeu ne se déclenchent qu'en scannant des cartes spécifiques, mais la plupart des serveurs privés les débloquent par défaut.

    **Pour la caméra des joueurs, n'importe quelle caméra USB UVC fait l'affaire**, même une webcam bon marché. Le jeu s'en sert uniquement pour afficher une photo des joueurs à la fin de chaque musique, une option que la plupart des joueurs désactivent pour gagner du temps.

    **Pour les lecteurs de QR-Code, le jeu est bien plus exigeant** : il faut obligatoirement des caméras USB UVC capables de filmer en 640x480, avec un FOV précis, sans quoi les QR-Codes ne sont pas reconnus.

    Dans les deux cas, le jeu prévoit **un éclairage dédié pour chaque caméra**, piloté par l'IO4. Il n'est pas indispensable de le raccorder, mais sans éclairage adapté, les lecteurs de QR-Code risquent de très mal fonctionner. Pour la caméra des joueurs, l'éclairage devient nécessaire si votre borne est dans une salle sombre. Le jeu pilote aussi une LED rouge, qui prévient les joueurs que la caméra filme.

    Les caméras se branchent en USB sur le ALLS : la caméra des joueurs directement sur la carte mère, les deux caméras des lecteurs de QR-Code sur le hub USB qui accueille déjà l'adaptateur RS-232 vers USB des contrôleurs de LEDs (voir l'[étape 6](step-6-lighting.md)).

## Caméra des joueurs (Photos in-game)

Chaque modèle de caméra est différent, il est donc difficile de proposer un support universel. Le mieux est de **concevoir un support imprimable en 3D** à installer au sommet de la borne, en profitant des vis existantes de la vitre en acrylique.

* **Installation sur la borne :** Impression 3D.
* **Branchement au ALLS :** En USB, sur le port **n°3**.
* **Branchement à l'IO4 :**
    - **CAMERA LED WARM : CN9 - Broche 7** : cathode de l'anneau de LEDs blanches qui éclaire la zone filmée.
    - **CAMERA LED RED : CN9 - Broche 8** : cathode de la LED rouge qui indique aux joueurs que la caméra filme.

Si vous avez fabriqué votre propre nappe de câbles et suivi la suggestion de l'[étape 6](step-6-lighting.md), vous avez déjà un connecteur prêt pour l'IO4. Avec la PCB de conversion, deux connecteurs dédiés sont disponibles pour ces LEDs.

!!! lightbox
    Schéma du ALLS : port USB n°3 utilisé pour la caméra des joueurs, mis en évidence par la flèche rouge
    PCB de conversion [maiConvert-IO4]({{IO4_CONVERSION_PCB}}) : repérage des connecteurs J29 ( ) et J30 ( )

## Caméras des lecteurs de QR-Code

L'idéal est de vous procurer **deux petits modules de 30mm x 25mm** : ils s'adaptent au [modèle 3D conçu par SpiralGlide](spiralglide-resources.md#support-du-lecteur-de-qr-code-dx-pass-reader), qui se fixe grâce aux vis existantes de la vitre en acrylique.

* **Installation sur la borne :** [Impression 3D](spiralglide-resources.md#support-du-lecteur-de-qr-code-dx-pass-reader).
* **Branchement au ALLS :** En USB, via le hub USB branché sur le port **n°2** à l'[étape 1](step-1-alls-and-psu.md). N'importe quel port du hub convient.
* **Branchement à l'IO4 :**
    - **1P CODE READER LED : CN3 - Broche 55** : cathode commune (R, G et B) de la bande de LEDs qui éclaire le lecteur du joueur 1.
    - **2P CODE READER LED : CN3 - Broche 56** : cathode commune (R, G et B) de la bande de LEDs qui éclaire le lecteur du joueur 2.

Si vous avez suivi la suggestion de l'[étape 6](step-6-lighting.md), vous avez déjà un connecteur prêt pour ces deux signaux. Ils sont aussi disponibles sur la PCB de conversion.

**Pour que le jeu identifie les caméras, chacune doit filmer un QR-Code précis** : *SDEZ01* côté joueur 1, *SDEZ02* côté joueur 2. Le modèle 3D de SpiralGlide comporte une encoche à la bonne taille pour ces codes. Imprimez [ce PDF](../resources/images/step-7-cameras/codes-for-qr-code-readers.pdf) en A4, sur une imprimante correctement calibrée, pour obtenir des QR-Codes à la bonne taille, puis collez-les à leur emplacement.

Si vous avez choisi les caméras de la [liste de courses](equipment.md), leur lentille est réglable : vous pouvez ajuster la mise au point.

!!! tip "Les LEDs des lecteurs de QR-Code"
    *DX* utilise d'origine une bande de LEDs RGB, mais ses trois couleurs partagent une seule cathode pilotée par l'IO4 : elles s'allument donc toujours ensemble, à (presque) la même intensité. **Une bande de LEDs blanc chaud donnera le même résultat.**

    **Ne braquez pas les LEDs directement vers la lentille de la caméra.** Éclairez plutôt la paroi en plastique, pour que la lumière se diffuse sur la carte. Un éclairage de face crée un reflet qui éblouit la caméra et empêche la lecture du QR-Code.

!!! tip "Installation des modules de caméra"
    **Le jeu est très exigeant sur l'orientation des caméras** : si l'angle n'est pas le bon, il ne lira pas le QR-Code des cartes. Attention aussi : un QR-Code par défaut bien lu ne garantit pas que les cartes le seront, faites des essais. Pour ajuster la hauteur et l'inclinaison d'un module, vous pouvez par exemple ajouter des écrous sur ses vis. Ce n'est pas idéal, mais ça fonctionne.

    Testez la détection dans le menu Test du jeu. Malheureusement, rien ne remplace les essais successifs pour cette étape.

!!! lightbox
    Schéma du ALLS : port USB n°2 utilisé pour le hub des caméras des lecteurs de QR-Code, mis en évidence par la flèche rouge
    PCB de conversion [maiConvert-IO4]({{IO4_CONVERSION_PCB}}) : repérage des connecteurs J25 ( ) et J26 ( )
    Écrous utilisés comme entretoises sur les vis du modèle 3D imprimé, afin d'ajuster la hauteur et l'angle des modules de caméra au-dessus des QR-Codes

## Validation de l'installation

Le menu Test du jeu propose une page dédiée aux caméras. Le jeu y cherche **trois flux vidéo**, dont deux doivent filmer les QR-Codes par défaut [SDEZ01](../resources/images/step-7-cameras/SDEZ01.svg) et [SDEZ02](../resources/images/step-7-cameras/SDEZ02.svg). Ces deux caméras sont reconnues automatiquement grâce à leur QR-Code, et la caméra restante est attribuée aux joueurs.

**Si les trois caméras sont reconnues dans le bon ordre, félicitations, l'installation est terminée !**

---

Passons à la [Conclusion](conclusion.md).

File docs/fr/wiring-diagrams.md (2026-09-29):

---
title: "Schémas de câblage"
---

# 🖨️ Schémas de câblage

Les [manuels officiels](official-manuals.md) contiennent, dans leurs toutes dernières pages, le schéma de câblage complet de la borne (planches au format A3, une par manuel de plusieurs dizaines de Mo). Pour éviter d'avoir à télécharger l'intégralité d'un manuel et à zoomer dans un lecteur PDF juste pour retrouver un fil, voici ces planches extraites en haute résolution.

_(Cliquez sur une planche pour l'ouvrir en pleine résolution dans un nouvel onglet. Chaque planche est précédée de la liste des cartes/modules qui y apparaissent, avec leur numéro de pièce, pour pouvoir retrouver une carte avec `Ctrl+F`. Les coordonnées entre crochets, ex. **[C-3]**{: .wiring-coord }, renvoient à la grille de repérage imprimée sur le pourtour de chaque planche - colonnes A à G, lignes 1 à 6 - et indiquent où se trouve la pièce sur le schéma.)_

## Manuel maimai DX

Chapitre *22 総合配線図* (« schéma de câblage général »), pages 193 à 196 du [manuel maimai DX](../resources/pdfs/maimai-dx-instruction-manual-full.pdf).

### Planche 1/4 - Alimentation, PC *ALLS*, ampli et écrans joueurs

* `MMT-1050` **ASSY AC UNIT** **[A-1]**{: .wiring-coord } - bloc d'entrée secteur (filtre antiparasite, fusible, prise IEC)
* `MMT-4200` **ASSY XFMR** **[C-1]**{: .wiring-coord } - transformateur d'alimentation
* `MMT-4300` / `601-13203-63` **ASSY ROUTER (ROUTER RTX830 BD MMT)** **[F-1]**{: .wiring-coord } - carte routeur réseau
* `MMT-4100` **ASSY ELEC BD** **[A-2]**{: .wiring-coord } - carte électronique principale, qui regroupe :
    * `838-15228` **2.1CH 40W STEREO AMP BD** ×2 **[B-2/B-3]**{: .wiring-coord } - amplis audio joueur 1 et 2
    * `839-1363-01` **HEADPHONE AMP BD SHC** ×2 **[B-5/B-6]**{: .wiring-coord } - amplis casque joueur 1 et 2
    * `400-5489-15024` **SW REGU VS150E-24** **[A-3]**{: .wiring-coord } - alimentation à découpage 24V
    * `400-5464-01505` **SW REGU VS15C-5** **[A-4]**{: .wiring-coord } - alimentation à découpage 5V
* `849-1004` **ASSY CASE ALLS HX2 W HDD** **[E-4]**{: .wiring-coord } - le boîtier du PC *ALLS* lui-même
* `MMT-1000` / `MMT-1500` **ASSY CABINET 1P / 2P** **[D-2/G-2]**{: .wiring-coord } - écrans joueurs (`200-6280` **LCD DSPL 43 LED**)
* `MMT-1200` / `MMT-1700` **ASSY SW BASE 1P / 2P** **[C-5/D-4]**{: .wiring-coord } - embases des boutons

Schéma de câblage maimai DX, planche 1 sur 4

---

### Planche 2/4 - Boutons, LEDs de boutons, hub USB et carte I/O

* `MMT-1200` / `MMT-1700` **ASSY SW BASE 1P / 2P** **[A-1]**{: .wiring-coord } - embases des boutons
* `837-15070-04` **IC BD LED DRV32CH RS232** ×2 **[E-2/D-2]**{: .wiring-coord } - pilote de LEDs, un par côté
* `837-20008` **4PORT USB HUB BD MINIB TO A** **[B-4]**{: .wiring-coord } - hub USB 4 ports
* `837-15067-02` **IC BD USB TO 4SERIAL 232 IF** **[A-5]**{: .wiring-coord } - adaptateur USB vers 4 ports série
* `837-15257-01` **I/O CONTROL BD 4 FOR USB** **[E-4]**{: .wiring-coord } - la carte **IO4** (JVS), voir l'[étape 4](step-4-io-board.md)
* `MMT-1000` / `MMT-1500` / `MMT-1900` **ASSY CABINET 1P / 2P / SIDE COVER BASE 1P** **[G-3/G-6/G-1]**{: .wiring-coord }

Schéma de câblage maimai DX, planche 2 sur 4

---

### Planche 3/4 - Boutons, capteur de l'anneau tactile, enseigne lumineuse

* `MMT-2000` **ASSY BUTTON SWITCH** ×8 **[B-1→B-4]**{: .wiring-coord } - boutons, avec pour chacun :
    * `838-15235-01` **LED BD RGB 3X1BLOCK 5050** **[B-1→B-4]**{: .wiring-coord } - LED RGB du bouton
    * `370-5359` **PHOTO INTERRUPTER OJ-555S-A5** **[C-1→C-4]**{: .wiring-coord } - capteur optique d'appui du bouton
* `837-20015` **HEADPHONE JACK BD** (`MMT-1070`) **[E-3]**{: .wiring-coord } - carte de la prise casque
* `509-6483` **TOUCH SENSOR UNIT TPK** **[B-6]**{: .wiring-coord } - carte du capteur de l'anneau tactile
* `MMT-1800-01` **ASSY BILLBOARD** **[F-5]**{: .wiring-coord } - enseigne lumineuse en haut de la borne
    * `390-5768` **LED TAPE RGB** **[F-4/G-4]**{: .wiring-coord } - rubans LED RGB de l'enseigne lumineuse
    * `MMT-1080` haut-parleurs `130-5310` **[F-5/G-5]**{: .wiring-coord }
* `390-7244` **LED TAPE WHITE M3528W-A** **[E-2]**{: .wiring-coord } - rubans LED blancs de l'anneau
* `130-5280-01` **WOOFER 4OHM 80W** **[E-6]**{: .wiring-coord }

Schéma de câblage maimai DX, planche 3 sur 4

---

### Planche 4/4 - Caméras, lecteur Aime, monnayeur et panneau d'entrée

* `MMT-1350` / `MMT-1370` **ASSY PLAYER CAMERA / PLAYER CAMERA UNIT** **[D-1]**{: .wiring-coord } - caméras joueurs
    * `601-13249` **CAMERA KBCR-S03MU-HPB2033-C300** **[D-1]**{: .wiring-coord }, voir l'[étape 7](step-7-cameras.md)
* `MMT-1440` **ASSY AIME AND VFD** **[B-3]**{: .wiring-coord } - module lecteur Aime (AIME RW UNIT) et afficheur 
    * `200-6275` **VFD GP1232A02A FUTABA** **[A-4]**{: .wiring-coord }, voir l'[étape 3](step-3-aime-reader.md)
* `MMT-1470` **ASSY CODE READER** **[B-5]**{: .wiring-coord } - lecteur de QR code
    * `601-13216-01` **USB CAMERA MS-M33NU2AMSH43-S2** **[A-5/A-6]**{: .wiring-coord }
* `MMT-1400` **ASSY CENTER TOWER** **[B-4]**{: .wiring-coord } - tour centrale
* `MMT-1450` **ASSY ENTRY PANEL** **[D-3]**{: .wiring-coord } - boutons de sélection joueur
    * `509-5970` **SW PB OBSF-24TR** **[D-3]**{: .wiring-coord } - référence Sanwa
* `MMT-1420` **ASSY SELECTOR DOOR** **[G-5]**{: .wiring-coord } - sélecteur/monnayeur
    * `220-5846-91-01` **[G-5]**{: .wiring-coord } - mécanisme accepteur de pièces
    * `220-5798-01` **MAG CNTR 4P MZ674** **[F-6]**{: .wiring-coord } - compteur de pièces
* `MMT-1460` **SW UNIT** **[G-5]**{: .wiring-coord } - boutons test/service
    * `838-14548-10` **SW & VOL BD** **[G-5]**{: .wiring-coord }
* `MMT-1900` / `MMT-1950` **ASSY SIDE COVER BASE 1P / 2P** **[A-1/G-2]**{: .wiring-coord }

Schéma de câblage maimai DX, planche 4 sur 4

---

## Manuel maimai PiNK

Chapitre *25 WIRING DIAGRAM*, pages 189 à 193 du [manuel maimai PiNK](../resources/pdfs/maimai-pink-manual-full.pdf).

### Planche 1/4 - Alimentation, écran et sélecteur de pièces

* `MAI-1050` **AC UNIT** **[B-1]**{: .wiring-coord } - bloc d'entrée secteur
* **ASSY LCD** **[F-1]**{: .wiring-coord } - Joueur 1, écran (`200-6226-91` **ASSY LCD DSPL 42 TYPE LED Y**)
* mécanisme accepteur de pièces
    * `MAI-1420` **ASSY SELECTOR DOOR** **[A-4]**{: .wiring-coord } - version Japon
        * `220-5846-01` **PFB-730 QL203 12VBK 100** **[B-3]**{: .wiring-coord }
    * `MAI-1420-01` **ASSY SELECTOR DOOR EXP** **[C-4]**{: .wiring-coord } - version export
        * `220-5842` **ELEC CC REJR SG-828** **[C-3]**{: .wiring-coord }
* **XFMR WIRING** **[B-5→G-6]**{: .wiring-coord } - transformateurs multi-tension
    * `560-5515-V-91` **[B-6]**{: .wiring-coord } - variante zone 100V
    * `560-5599` **[C-5]**{: .wiring-coord } - variante zones 110V à 240V (répétée à plusieurs tensions sur la planche)

Schéma de câblage maimai PiNK, planche 1 sur 4

---

### Planche 2/4 - Lecteur Aime, haut-parleurs, LEDs et alimentations

* `MAI-1400` **ASSY COIN CHUTE TOWER** **[B-2]**{: .wiring-coord } - tour centrale
    * `838-14971` **NFC RW BD TN32MSEC003S** **[D-1/D-2]**{: .wiring-coord } - la carte du lecteur de carte Aime, remplacée à l'[étape 3](step-3-aime-reader.md)
* `MAI-1420` **ASSY SELECTOR DOOR** **[D-2]**{: .wiring-coord }
    * `220-5798-01` **MAG CNTR 4P MZ674** **[C-2]**{: .wiring-coord } - compteur de pièces
* `MAI-1460` **SW UNIT** (`838-14548-10` **SW & VOL BD**) **[D-3]**{: .wiring-coord } - boutons test/service et volume
* `MAI-0500` **ASSY SPEAKER** **[G-1]**{: .wiring-coord } - haut-parleurs
    * `838-15228` **2.1CH 40W STEREO AMP BD** ×2 **[F-2/F-3]**{: .wiring-coord }
    * `130-5296` caisson **[G-1]**{: .wiring-coord }
    * `130-5280` woofer **[G-2]**{: .wiring-coord }
* `MAI-1090` **FAN UNIT DC12V** (`260-0139`) **[D-4]**{: .wiring-coord } - ventilateur
* `MAI-4000` **ASSY SW RGLTR** **[C-4]**{: .wiring-coord } - alimentations à découpage (`400-5489-15024`/`15012`)
* `MAI-1080` **CENTER LED / ROOF LED (L) / ROOF LED (R)** ×3 **[F-3/F-4]**{: .wiring-coord }
    * `MAI-1070` **WOOFER LED** **[E-5]**{: .wiring-coord } - LEDs décoratives (`838-15235-01` **LED BD RGB**)

Schéma de câblage maimai PiNK, planche 2 sur 4

---

### Planche 3/4 - Carte I/O (JVS), adaptateur Serial-USB, contrôleur tactile et PC *RingEdge 2*

* **ASSY LCD** **[G-1]**{: .wiring-coord } - Joueur 2, écran (`200-6226-91` **ASSY LCD DSPL 42 TYPE LED Y**)
* `837-14505` **I/O CONTROL BD FOR JVS** **[D-1]**{: .wiring-coord } - la carte IO3, remplacée par l'IO4 à l'[étape 4](step-4-io-board.md)
* `837-15067-02` **IC BD USB TO 4SERIAL 232 IF** **[F-2]**{: .wiring-coord } - l'adaptateur RS-232 vers USB mentionné à l'[étape 6](step-6-lighting.md)
* `838-15221` **SERIAL I/F BD TOUCHPANEL GUNZE** **[D-4]**{: .wiring-coord } - carte contrôleur de la dalle tactile
* **ASSY CASE RGE2 W M2G S64G** **[E-3/E-4]**{: .wiring-coord } - PC *RingEdge 2* 
    * `846-5003D` **[E-3]**{: .wiring-coord } (version Japon)
    * `846-5003D-02` **[E-4]**{: .wiring-coord } (version export)
* `MAI-4100` **ASSY ROUTER** (`601-12336-34` **ROUTER RT107E BD MAI**) **[F-6]**{: .wiring-coord }

Schéma de câblage maimai PiNK, planche 3 sur 4

---

### Planche 4/4 - Boutons, contrôleur de LEDs et anneau tactile

* `MAI-1200` / `MAI-1201` **ASSY SW BASE** **[D-1/D-5]**{: .wiring-coord } - embase et disposition des 8 boutons
    * `838-15235-01` **LED BD RGB** **[D-1→D-3]**{: .wiring-coord }
    * `370-5359` **PHOTO INTERRUPTER OJ-535S-A5** **[E-1→E-3]**{: .wiring-coord }
* `837-15070-02-91` **IC BD LED DRV32CH RS232** **[C-4]**{: .wiring-coord } - le contrôleur de LEDs mentionné à l'[étape 6](step-6-lighting.md)
* `509-6384` **TOUCH SENSOR PANEL UNIT** **[E-5]**{: .wiring-coord } - carte du capteur de l'anneau tactile

Schéma de câblage maimai PiNK, planche 4 sur 4

---

### Kit caméra en option - Caméra joueur et boîtier de contrôle

* `MAI-3100` **ASSY CAMERA SW RGLTR** **[C-1]**{: .wiring-coord } - PSU de la caméra
    * `400-5489-05012` **SW REGU VS50E-12** **[C-3]**{: .wiring-coord }
* `MAI-3000` **ASSY CAMERA BOX** **[D-1]**{: .wiring-coord } - boîtier caméra, voir l'[étape 7](step-7-cameras.md)
    * `838-15222` **MOVIE CAMERA CTRL BD** **[D-3]**{: .wiring-coord }
    * `601-12827-01` **BD CAMERA KBCR-S01MG-HPB1022** **[F-2]**{: .wiring-coord }
* `MAI-3050` **ASSY LCD W/CUSHION** **[F-3]**{: .wiring-coord } - écran de retour
    * `200-6211` **LCD MODULE NL6448BC18-01 NLT** **[F-3]**{: .wiring-coord }
* **ASSY CASE RGE2 W M2G S64G** **[C-3/C-4]**{: .wiring-coord } - PC *RingEdge 2* 
    * `846-5003D` **[C-3]**{: .wiring-coord } (version Japon)
    * `846-5003D-02` **[C-4]**{: .wiring-coord } (version export)
* `MAI-4100` **ASSY ROUTER** (`601-12336-34` **ROUTER RT107E BD MAI**) **[B-5]**{: .wiring-coord }

Schéma de câblage maimai PiNK, kit caméra en option

---

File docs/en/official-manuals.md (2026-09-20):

---
title: "Official manuals"
---

# 📚 Official manuals

This page lists the official manuals referenced throughout this guide.

* [maimai DX Instruction manual](../resources/pdfs/maimai-dx-instruction-manual-full.pdf): the official maintenance manual for the cabinet in its **maimai DX** version, the one this guide proposes converting to.
* [maimai DX service manual](../resources/pdfs/maimai-dx-service-manual-full.pdf): the official *service manual* for **maimai DX**, focused on the cabinet's software rather than its hardware.
* [ALLS HX2 service manual](../resources/pdfs/alls-hx2-service-manual-full.pdf): the official *service manual* for the **ALLS HX2** PC, the central PC used by *maimai DX* (see the [ALLS and PSU](step-1-alls-and-psu.md) step).
* [maimai PiNK manual](../resources/pdfs/maimai-pink-manual-full.pdf): the official maintenance manual for the cabinet in its **maimai PiNK** version, a revision earlier than *FiNALE*. However, there is no notable hardware difference between PiNK and FiNALE.

The *maimai DX* and *maimai PiNK* manuals each contain, in their last pages, a complete wiring diagram of the cabinet. A high-resolution extraction of those plates, quicker to consult than the full PDFs, is available on the [Wiring diagrams](wiring-diagrams.md) page.

---

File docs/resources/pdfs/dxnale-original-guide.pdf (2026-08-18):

# So, you’ve decided to DxNALE?

## Preface

## Considerations

- Are you capable of scouring over wiring diagrams?
- This is not a step-by-step guide, it’s more high level instructions and descriptions of what is required. I think I’ve done a good job of documenting most of the important stuff—But I absolutely may have missed something.
- Do you really want to do this in the first place?
- Playing DX is nice, but it is a ton of effort. Also, you won’t be able to return to FiNALE easily.
- This is still cost effective compared to real DX, but again, work. Lots of it. Be prepared to sacrifice a week+ of your time.
- Is there anything you need to replace on your cab?
- You should try to get your cab running FiNALE perfectly before doing this jump. It’ll help investigating issues later.
- It’ll save potential work items and purchase items if it all works.
- Do you care about getting on Mythos?
- You don’t need a pi if not. You can just set up serial for your ADX cons, and run the data USB directly to your PC.
- Do you care about player cameras/code readers?
- You can save some money and effort running cables here. If you’re mythos-bound, Felix can disable this functionality for you.
- Do you care about LEDs?
- You can save some effort here if your LED controllers were dead, or you don’t care about the billboard LEDs.

## Costs

To personally detail the costs on my own cab,
- Cab - $3250
- Shipping – 1500$ (total $4750)
- Controllers – 2000$ + 300$ shipping to US (total $7050)
- Rabbit buttons (https://bluespringexpress.net/en-us/products/maimai-button) – 440$ + 30$ shipping (total $7520)
- Raspberry Pi 5 (https://www.amazon.com/dp/B0D2WYFS23) (I got a shitty starter kit because I’m lazy) – 130$. (total $7560)
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

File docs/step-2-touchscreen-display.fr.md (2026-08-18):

---
title: "📺 2 - Écrans et dalles tactiles"
---

# 📺 Étape 2 : L'Affichage et les Dalles Tactiles ADX

Toute la complexité réside au niveau de la connexion des dalles tactiles ADX, mais dans un premier temps, commençons par les installer.

## Les connexions vidéo

Le jeu est programmé pour envoyer la vidéo d'une manière bien précise aux deux écrans. L'ordre doit être respecté. *(Référence : [Manuel](pdfs/maimai-dx-manual-full.pdf) officiel de la borne DX, page 128)*

* **Joueur 1 (P1) :** Doit être branché sur le port **DisplayPort** (Attention : le [manuel](pdfs/maimai-dx-manual-full.pdf) officiel comporte une erreur et indique HDMI à tort).
* **Joueur 2 (P2) :** Doit être branché sur le port **DVI**.

*(Le port HDMI restant sur la carte graphique peut être utilisé pour brancher du matériel de capture vidéo, toutefois celui-ci ne propose que la sortie du joueur 1)*.

Il existe toutefois une légère différence native entre les écrans d'une *FiNALE* et d'une *DX*. Dans les deux cas, il s'agit d'écrans 1920x1080 cadencés à 60 Hz, mais les écrans de *FiNALE* mesurent 42" de diagonale, alors que les écrans de *DX* mesurent 43". La différence est pratiquement imperceptible en jeu.
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

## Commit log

2026-08-18 Add Styling options from two-torial, rework flow, add emojis, fix pipeline deploay
2026-08-19 Adding manuals and high definition extracts of the wiring diagrams for easier access
2026-08-19 Add boards references on the diagram page for easy search
2026-08-21 Add coordinates for every elements to the wiring-diagrams page
2026-08-21 Fix display issue on top of wiring-diagrams
2026-08-23 Removed the — people seem to hate so much for some reason
2026-08-24 Update led page informations
2026-09-02 Add pictures to step 6, step is now final except for mount instructions
2026-09-03 Adding reference to SpiralGlide's work
    [dxnale-dx-pass-reader-front-panel-v2.stl, dxnale-dx-pass-reader-midpanel-v2.stl, dxnale-dx-pass-reader.stl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]
2026-09-11 Add mention of the custom conversion PCB in the lighting page
2026-09-17 Add Cameras chapter, finalize lighting and aime reader sections
2026-09-18 Add substitute for external links for easy update in case of one them dies
2026-09-20 Adding new manuals and files
    [maimai-aime-reader.ipt]
